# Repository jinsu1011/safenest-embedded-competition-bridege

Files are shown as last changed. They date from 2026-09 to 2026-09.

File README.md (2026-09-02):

# SafeNest

밀폐공간 작업자의 **호흡·움직임·자세**와 **공기질**을 동시에 감시해, 위험을 스스로 알릴 수 없는 상태가 되기 전에 경보하는 임베디드 안전 모니터링 시스템.

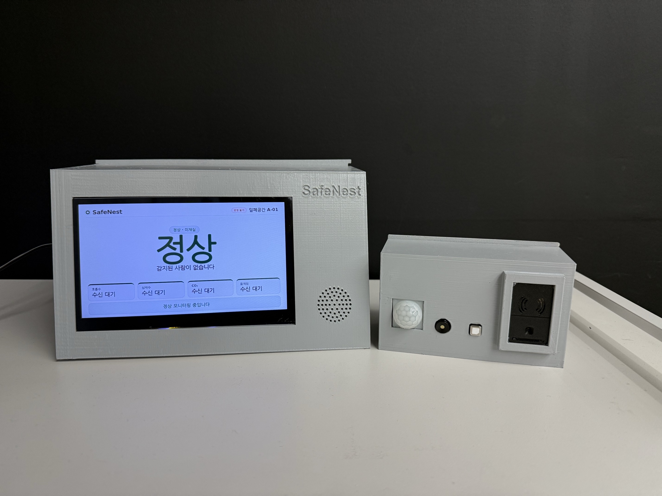
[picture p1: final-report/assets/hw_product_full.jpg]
SafeNest 완제품


| 현장 LCD 패널 | 관제 웹 대시보드 |
|---|---|
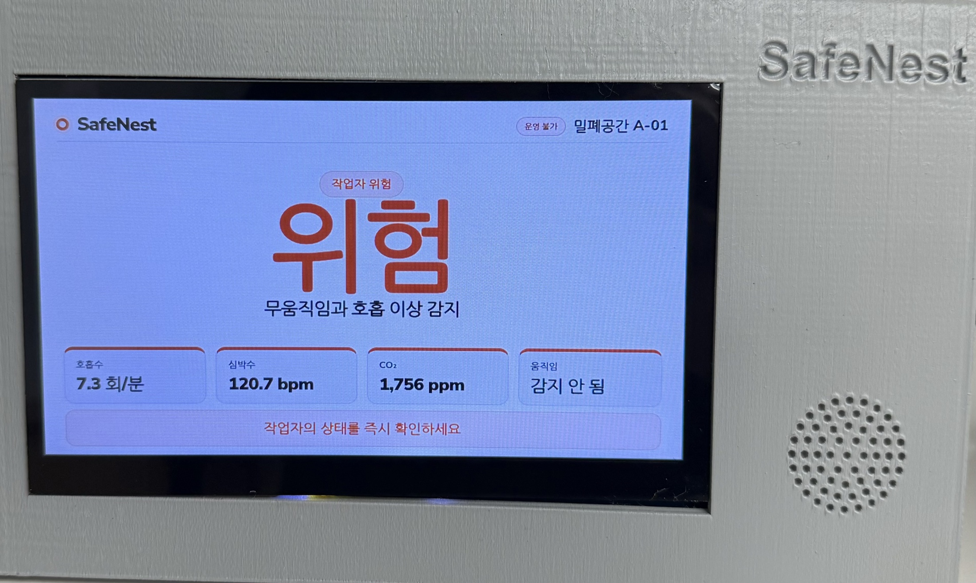
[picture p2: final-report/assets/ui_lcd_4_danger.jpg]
LCD 위험 상태
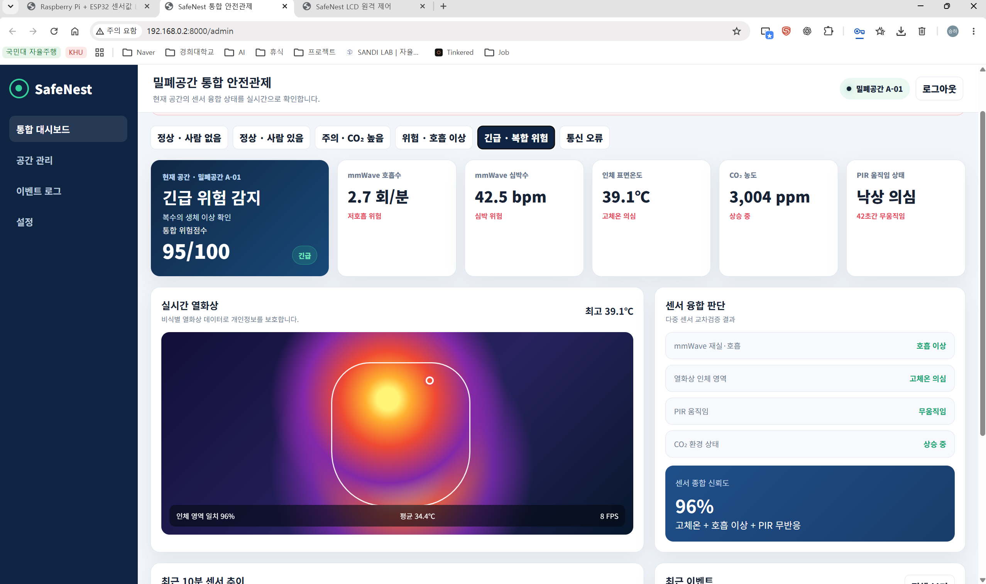
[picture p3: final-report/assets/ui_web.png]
웹 대시보드
|  |  |

---

## 프로젝트 개요

**문제.** 맨홀·정화조·탱크 같은 밀폐공간 질식 재해는 쓰러진 뒤에는 본인이 도움을 요청할 수 없다. 사고의 대부분은 "감지가 늦어서"가 아니라 "아무도 보고 있지 않아서" 커진다. 반대로 CO₂ 센서만 두면 사람이 이미 무호흡 상태여도 공기질이 기준 이하면 정상으로 표시된다.

**접근.** SafeNest는 한 가지 신호에 의존하지 않는다. mmWave 레이더로 **호흡**을, 열화상으로 **자세**를, PIR로 **움직임**을, NDIR 센서로 **CO₂**를 각각 독립적으로 관측하고, 네 결과를 하나의 위험도로 융합한다.

추론은 전부 Raspberry Pi 위에서 수행된다. **센서 데이터 처리, AI 추론, 위험도 판단, 현장 경보(부저·TTS), 화면 표시는 클라우드 서버 없이 Pi 안에서 완결된다.** ESP32 센서 노드와 Raspberry Pi 사이는 현장 Wi-Fi 의 TCP/UDP 로 연결되므로 이 구간이 끊기면 해당 센서는 데이터 없음(`INDETERMINATE`) 으로 처리된다.

**적용 환경.** 밀폐공간 단독·소수 작업, 상시 관제 인력이 없는 현장.

---

## 핵심 기능

- **4채널 센서 수집** — mmWave 호흡/심박, MH-Z19B CO₂, PIR 움직임, 80×62 열화상 프레임
- **이중 전송 경로** — 저속 스칼라는 TCP(`SNST` v1), 열화상 프레임은 청크 UDP(`SNTU` v1). 프레임 CRC32·형상·길이를 모두 검증하고 순서 무관 재조립
- **센서 상태 관리** — 센서별 freshness/유효성을 값과 분리해 추적. 오래된 값을 최신값처럼 표시하지 않음
- **온디바이스 AI 3종** — Thermal 자세 proxy(TFLite), CO₂ 재실 판정(TFLite INT8), mmWave 호흡 파형(PyTorch). 각 모델은 서로 격리되어 하나가 실패해도 나머지 판단이 유지됨
- **증거 충분성 기반 위험도 융합** — 가중합에 더해 ① 심각 신호가 평온한 신호에 희석되지 않는 escalation floor, ② 근거가 부족하면 NORMAL 대신 `INDETERMINATE` 를 게시하는 evidence gate, ③ 상위 두 확률 차가 작으면 "판단 없음"으로 처리하는 decisiveness gate
- **비상 대응 HMI** — 위험 확정 시 부저, 로컬 한국어 TTS 음성 안내, 담당자 SMS, 경보 확인/해제 절차
- **관제 화면 3종** — 관리자 포털, 관제 대시보드, QR 게스트 화면
- **현장 LCD 패널** — Raspberry Pi 로컬 LCD 상태 화면
- **SQLite 영속화** — 상태 스냅샷과 전이 이벤트 기록, 디스크 쿼터를 지키는 원시 센서 로깅

---

## System Architecture

```
MR60BHA2 (호흡·심박) ┐
MH-Z19B   (CO₂)      ├─→ ESP32 ─┬─ TCP  :9000  SafeNest v1 스칼라 telemetry
PIR       (움직임)   │          └─ UDP  :5005  Thermal 청크 프레임
MI48xx    (열화상)   ┘                 │
                                       ▼
                        Raspberry Pi ── Gateway (프로토콜 검증 / UDP 재조립)
                                       │
                                       ▼
                              Sensor State Manager  (freshness · 유효성 · revision)
                                       │
                                       ▼
                              On-device AI Pipeline
                                 ├ Thermal  TFLite fp32
                                 ├ CO₂      TFLite int8
                                 └ mmWave   PyTorch fp32
                                       │
                                       ▼
                              Risk Formula V1  (가중합 + escalation floor + evidence gate)
                                       │
                     ┌─────────────────┼─────────────────┐
                     ▼                 ▼                 ▼
                  SQLite         FastAPI :8000       Emergency
              (이벤트/이력)      REST + WebSocket   부저 · TTS · SMS
                                       │
                     ┌─────────────────┼─────────────────┐
                     ▼                 ▼                 ▼
                  /admin           /dashboard      /display (LCD)
                                   /guest/...
```

위험 등급: `NORMAL` · `WARNING` · `DANGER` · `INDETERMINATE`(근거 부족)

---

## Hardware

| 장치 | 부품 | 연결 |
|---|---|---|
| 센서 노드 MCU | ESP-WROOM-32 (ESP32 Dev Module) | — |
| 호흡 · 심박 · 재실 | Seeed MR60BHA2 60 GHz mmWave | UART2 GPIO 16/17 |
| CO₂ | Winsen MH-Z19B NDIR | UART1 GPIO 32/33 (별도 4.5–5.5 V 전원) |
| 움직임 | PIR 모션 센서 | GPIO 13 |
| 열화상 80×62 | MI48xx 기반 Thermal Camera HAT | I²C 21/22 제어 + SPI 18/19/23/27, READY 26, RESET 25 |
| 게이트웨이 · AI · 백엔드 | Raspberry Pi 5 | 2.4 GHz Wi-Fi |
| 표시 | Raspberry Pi 연결 LCD (Chromium 키오스크) | — |
| 경보 | 부저(GPIO), 스피커 | — |

외함 STL 과 설계 사양은 [`hardware/3d_models/`](hardware/3d_models/) 에 있다.

---

## Repository Structure

```
.
├── run_safenest.sh                  ★ 공식 실행 진입점 (유일)
├── README.md · THIRD_PARTY_NOTICES.md · COMPONENT_SOURCES.json
│
├── ESP32/
│   ├── Arduino/esp32_sensor_node/
│   │   ├── esp32_sensor_node.ino   ★ 정본 펌웨어
│   │   ├── secrets.example.h
│   │   └── ESP32.md
│   └── docs/            빌드 환경 가이드 · 통신 프로토콜 명세
│
├── RaspberryPi/
│   ├── Runtime/         ★ 게이트웨이 · 상태 · AI · 위험도 · 백엔드 · DB
│   │   ├── deployment/  run_pi.sh · verify_bundle.py
│   │   ├── gateway/     protocol.py · receiver.py · thermal_udp.py
│   │   ├── state/       manager.py
│   │   ├── ai/          pipeline.py · runtime.py · mmwave_b23_* · co2_canonical_runtime.py
│   │   ├── risk/        formula_v1.py · risk_formula_v1.json · engine.py
│   │   ├── backend/     app.py · run_backend.py · runtime.py · views.py · portal.py
│   │   ├── database/    schema.sql · repository.py · store.py
│   │   ├── services/    tts.py · buzzer.py · sms_service.py · emergency.py
│   │   ├── storage/     sensor_logger.py
│   │   ├── hil/         preflight.py(기동 필수) · 현장 수집/판정 도구
│   │   └── tests/       소프트웨어 테스트
│   ├── Ondevice_AI/
│   │   ├── inference/   ★ Thermal·CO₂ 활성 어댑터 (+ 비활성 M-N9)
│   │   ├── models/      ★ model_manifest.json + 모델 아티팩트
│   │   ├── risk/        risk_config.json (구형 V4, 활성 엔진 미사용)
│   │   └── tests/       활성 Thermal 모델 계약 테스트
│   ├── Web/             ★ 관리자 포털 · 대시보드 · 게스트 화면
│   │   └── vendor/      외부 라이브러리 로컬 포함 (Chart.js)
│   └── LCD/static/      ★ display.html · common.css
│
├── hardware/            3D 하우징 STL 및 설계 사양
└── final-report/        대회 개발완료보고서 PDF/PPTX 및 이미지 자산
```

---

## 실행되는 코드

런타임이 실제로 로드하는 진입점과 자산은 다음이다. 저장소에는 이 밖에 비활성 모델 아티팩트와 데모 모드 전용 대시보드 자산이 함께 보관되어 있으며, 어느 것도 기본 실행 경로에 로드되지 않는다.

| 구성 | 경로 |
|---|---|
| **ESP32 펌웨어** | [`ESP32/Arduino/esp32_sensor_node/esp32_sensor_node.ino`](ESP32/Arduino/esp32_sensor_node/esp32_sensor_node.ino) |
| **Runtime 진입점** | [`run_safenest.sh`](run_safenest.sh) → [`RaspberryPi/Runtime/deployment/run_pi.sh`](RaspberryPi/Runtime/deployment/run_pi.sh) → [`RaspberryPi/Runtime/backend/run_backend.py`](RaspberryPi/Runtime/backend/run_backend.py) |
| **Web 관리자** | [`RaspberryPi/Web/portal/preview.html`](RaspberryPi/Web/portal/preview.html) + `portal/admin-api.js` + `portal/thermal-client.js` |
| **Web 대시보드** | [`RaspberryPi/Web/index_final.html`](RaspberryPi/Web/index_final.html) + `app_final.js` + `styles_final.css` |
| **Web 게스트** | [`RaspberryPi/Web/guest/index.html`](RaspberryPi/Web/guest/index.html) |
| **LCD** | [`RaspberryPi/LCD/static/display.html`](RaspberryPi/LCD/static/display.html) + [`RaspberryPi/LCD/static/common.css`](RaspberryPi/LCD/static/common.css) |

경로 상수는 [`RaspberryPi/Runtime/paths.py`](RaspberryPi/Runtime/paths.py) 한 곳에 모여 있다.

---

## 핵심 코드

| # | 파일 | 역할 |
|---|---|---|
| 1 | [ESP32 정본 펌웨어](ESP32/Arduino/esp32_sensor_node/esp32_sensor_node.ino) | 4센서 수집, `delay()` 없는 millis 스케줄링, TCP/UDP 를 각각 FreeRTOS 태스크로 분리, 1-슬롯 열화상 큐로 최신 프레임 우선 |
| 2 | [`gateway/protocol.py`](RaspberryPi/Runtime/gateway/protocol.py) | `SNST` v1 16바이트 헤더 파싱과 페이로드 검증, 9,936바이트 열화상 계약 |
| 3 | [`gateway/thermal_udp.py`](RaspberryPi/Runtime/gateway/thermal_udp.py) | 청크 UDP 순서 무관 재조립, CRC32·형상·범위 검증, 프레임 타임아웃 |
| 4 | [`state/manager.py`](RaspberryPi/Runtime/state/manager.py) | 센서별 freshness/유효성/기기 건강을 값과 분리해 관리, publication revision 발행 |
| 5 | [`ai/pipeline.py`](RaspberryPi/Runtime/ai/pipeline.py) | 모델별 격리 평가. mmWave 는 wire rate 로 누적, CO₂ 는 measurement-event 기준으로 누적 |
| 6 | [`ai/runtime.py`](RaspberryPi/Runtime/ai/runtime.py) | 지연 로딩 + 실패 격리 어댑터. manifest selector 와 런타임이 어긋나면 `MODEL_SELECTOR_DRIFT` 로 차단 |
| 7 | [`ai/mmwave_b23_runtime.py`](RaspberryPi/Runtime/ai/mmwave_b23_runtime.py) | 활성 mmWave 경로. 30초 호흡 파형을 10 Hz 300표본으로 정규화 후 621차원 입력 생성 |
| 8 | [`risk/formula_v1.py`](RaspberryPi/Runtime/risk/formula_v1.py) | **활성 위험도 엔진.** 가중합 + escalation floor + evidence sufficiency + decisiveness gating |
| 9 | [`backend/app.py`](RaspberryPi/Runtime/backend/app.py) | FastAPI 라우트, WebSocket 게시, Web/LCD 서빙, 공간 포털, 비상 액션 API |
| 10 | [`hil/preflight.py`](RaspberryPi/Runtime/hil/preflight.py) | 기동 전 필수 검사. 모든 모델 SHA256 을 manifest 와 대조해 불일치 시 기동 차단 |

---

## Installation

Raspberry Pi 5 / 64-bit OS / **Python 3.10 이상** 기준.

```bash
git clone https://github.com/jinsu1011/safenest-embedded-competition-bridege.git safenest
cd safenest
./run_safenest.sh --install
```

`--install` 이 수행하는 것:

1. 저장소 루트에 `.venv` 생성
2. `RaspberryPi/Runtime/requirements-backend.txt` 설치 — FastAPI, uvicorn, qrcode, piper-tts
3. `RaspberryPi/Ondevice_AI/requirements-pi.txt` 설치 — LiteRT, numpy/scipy, spidev/smbus2, **torch(CPU wheel index 사용)**
4. `import fastapi, piper, qrcode, torch, uvicorn` 로 설치 검증
5. Piper 한국어 음성 `ko_KR-kss-medium` 다운로드 (`RaspberryPi/Runtime/data/tts/`, Git 미추적)

> **torch 가 필수인 이유** — 활성 mmWave 경로 B23 은 PyTorch float32 모델이고, 해당 모듈이 `backend/app.py → backend/runtime.py → ai/pipeline.py` import 체인에 포함된다. torch 가 없으면 백엔드가 기동되지 않는다.
> 일반 PyPI 의 ARM64 torch 는 Pi 에 없는 CUDA/NVIDIA 의존성을 끌어오므로, `requirements-pi.txt` 는 공식 CPU wheel index(`https://download.pytorch.org/whl/cpu`)를 함께 지정한다.

민감 설정은 저장소 루트 `.env` 로 주입한다. 키 목록은 [`RaspberryPi/Runtime/.env.example`](RaspberryPi/Runtime/.env.example) 참고 (SMS 자격증명, 담당자 연락처, 부저 GPIO, 센서 데이터 쿼터 등). `.env` 는 Git 에 올리지 않는다.

---

## Execution

**공식 실행 방법은 하나다.**

```bash
./run_safenest.sh
```

이 한 줄이 하나의 프로세스 트리에서 다음을 모두 띄운다.

| 구성 | 포트 |
|---|---|
| SafeNest TCP v1 게이트웨이 (mmWave/CO₂/PIR) | `9000/tcp` |
| SafeNest Thermal UDP v1 수신기 | `5005/udp` |
| FastAPI + WebSocket (Web · LCD · API) | `8000/tcp` |

기동 직전 `hil.preflight` 가 Python 버전, 필수 모듈, 포트 가용성, **모델 SHA256 계약**을 검사하고 실패 시 기동을 중단한다.

주요 옵션은 그대로 전달된다. 예: `./run_safenest.sh --api-port 8080 --room "밀폐공간 B-02"`

<details>
<summary>선택: Thermal 모델 A/B 비교 실행</summary>

```bash
# 현재 활성 모델 — 환경변수 없이 그대로 기동
./run_safenest.sh

# TV2 Candidate A
SAFENEST_THERMAL_TEST_MODE=1 SAFENEST_THERMAL_MODEL_SELECTOR=thermal_tv2_candidate_a_a0_fp32_v1 ./run_safenest.sh

# TV2 Candidate B
SAFENEST_THERMAL_TEST_MODE=1 SAFENEST_THERMAL_MODEL_SELECTOR=thermal_tv2_candidate_b_seed42_fp32_test_v1 ./run_safenest.sh
```

`SAFENEST_THERMAL_TEST_MODE=1` 이 없으면 selector 지정은 fail-closed 로 거부되고, manifest 에서 `controlled_test_allowed: true` 인 모델만 선택된다. 평시 운영 경로(`./run_safenest.sh`)는 영향을 받지 않는다. Candidate A/B 는 비교 대상이지 배포 모델이 아니다.
</details>

---

## ESP32 Build & Flash

1. Arduino IDE 에 ESP32 보드 패키지 설치 후 **ESP32 Dev Module** 선택
2. Library Manager 에서 **Seeed Arduino mmWave** 설치 (하위 의존성 `Install all`)
3. 자격증명 파일 생성 — 실제 값은 커밋되지 않는다

   ```bash
   cd ESP32/Arduino/esp32_sensor_node
   cp secrets.example.h secrets.h
   ```

   `secrets.h` 에 2.4 GHz Wi-Fi SSID/비밀번호, Raspberry Pi 의 WLAN IPv4(`RPI_HOST`), TCP 포트(`RPI_PORT`, 기본 9000)를 입력한다. 열화상 UDP 도 같은 호스트의 5005 로 전송된다.
4. `esp32_sensor_node.ino` 를 열어 컴파일 후 업로드
5. Serial Monitor `115200 baud` 에서 `[health]` 로그의 `wifi=up`, `rpi=<Pi IP>`, `udp_sent` 증가 확인

상세 절차·배선표·오류 대응은 [`ESP32/docs/ARDUINO_ENVIRONMENT_SETUP_KO.md`](ESP32/docs/ARDUINO_ENVIRONMENT_SETUP_KO.md), 와이어 포맷은 [`ESP32/docs/COMMUNICATION_PROTOCOL.md`](ESP32/docs/COMMUNICATION_PROTOCOL.md).

---

## Web Dashboard

`./run_safenest.sh` 실행 후 같은 네트워크에서 접속한다. 별도 웹 서버는 없다.

| 화면 | URL | 서빙 파일 |
|---|---|---|
| 관리자 포털 (기본 진입) | `http://<pi>:8000/admin` | `Web/portal/preview.html` |
| 관제 대시보드 | `http://<pi>:8000/dashboard` | `Web/index_final.html` |
| 게스트 QR 화면 | `http://<pi>:8000/guest/dashboard/<space_id>` | `Web/guest/index.html` |
| LCD 패널 | `http://<pi>:8000/display` | `LCD/static/display.html` |
| 헬스체크 | `http://<pi>:8000/health` | — |

`http://<pi>:8000/` 은 `/admin` 으로 리다이렉트된다.

**모든 화면은 외부 네트워크 자산을 참조하지 않는다.** 그래프 라이브러리(Chart.js 4.5.1)까지 저장소에 포함해 `/vendor/chart.js/chart.umd.min.js` 로 같은 서버가 서빙하므로, 인터넷이 없는 현장에서도 관리자·대시보드·게스트·LCD 화면이 모두 완전하게 동작한다. 출처와 라이선스는 [`THIRD_PARTY_NOTICES.md`](THIRD_PARTY_NOTICES.md) 6장 참고.

**API / WebSocket** — 전체 계약은 [`backend/views.py`](RaspberryPi/Runtime/backend/views.py) 의 `ROUTE_CONTRACTS` 에 정의되어 있다.

| 종류 | 경로 |
|---|---|
| 상태 | `GET /api/status` · `GET /api/sensors` · `GET /api/state` |
| 이력 | `GET /api/events` · `GET /api/history` |
| 공간 관리 | `GET/POST /api/spaces` · `GET/PATCH/DELETE /api/spaces/{id}` · `GET /api/qr/{id}.png` |
| 열화상 | `GET /api/thermal/{space_id}` (ETag 기반 바이너리 프레임) |
| 비상 대응 | `POST /api/emergency/contact` · `/acknowledge` · `/recovery/acknowledge` · `/voice` |
| 실시간 | `WS /ws` — publication revision 이 바뀔 때만 상태 문서 전송 |

**관리자 계정은 저장소에 없다.** `/admin` 로그인은 환경변수로만 설정한다.

```bash
export SAFENEST_ADMIN_ID=...
export SAFENEST_ADMIN_PASSWORD=...
export SAFENEST_AUTH_SECRET=...        # 선택. 없으면 프로세스마다 무작위 서명 키
```

두 값을 모두 설정하기 전까지 로그인은 **항상 거부**된다(fail-closed). 빈 값끼리 일치해 통과하는 경로도 없다. 나머지 런타임·API·LCD·게스트 화면은 계정 설정과 무관하게 정상 동작하며, 현재 설정 여부는 `GET /health` 의 `admin_auth_configured` 로 확인한다.

`SAFENEST_DEMO_MODE=1` 로 실행하면 데모 전용 화면(`/control`, `/dashboard` 의 데모판)과 119 신고 시뮬레이션 API 가 추가로 열린다. 평시 운영에서는 사용하지 않는다.

---

## LCD

Raspberry Pi 에 연결된 LCD 는 **통합 백엔드가 직접 서빙**한다. 별도 LCD 서버 프로세스는 없다.

| 경로 | 파일 |
|---|---|
| `/display` | `RaspberryPi/LCD/static/display.html` |
| `/common.css` | `RaspberryPi/LCD/static/common.css` |

`display.html` 은 `GET /api/state` 를 폴링해 갱신하며, 외부 자산을 참조하지 않는다. Chromium 키오스크 실행·종료 절차는 [`RaspberryPi/LCD/LCD_KIOSK_KO.md`](RaspberryPi/LCD/LCD_KIOSK_KO.md).

---

## On-device AI

추론은 모두 Raspberry Pi 에서 수행된다. 활성 모델은 [`models/model_manifest.json`](RaspberryPi/Ondevice_AI/models/model_manifest.json) 이 selector 와 SHA256 으로 고정하며, 기동 시 preflight 가 전 항목을 대조한다.

| 센서 | selector | 아티팩트 | 형식 | 출력 |
|---|---|---|---|---|
| Thermal | `thermal_public_sdt_fp32_active` | `models/thermal/public_sdt/public_sdt_pooled_mlp_fp32_tflite_v1.tflite` | TFLite fp32 | `NOT_HUMAN` / `HUMAN_NORMAL` / `HUMAN_FALL_PROXY` |
| CO₂ | `co2_occupancy_c_b6` | `models/rp_x0_b_complete/co2/C_B6_REDUCED_CO2_SLOPE_CANDIDATE_001_full_integer_int8.tflite` | TFLite full-int8 | 실내 재실 여부 |
| mmWave | `mmwave` (M-PROT-B23) | `models/mmwave/m_prot_b23/candidate_seed_23.pt` | PyTorch fp32 | 호흡 파형 판정 + 품질 |

**실행 경로.** [`ai/pipeline.py`](RaspberryPi/Runtime/ai/pipeline.py) 가 세 모델을 서로 격리해 평가한다.

| 센서 | 호출되는 코드 |
|---|---|
| Thermal | `ai/runtime.py` 의 `LazyModel` → `Ondevice_AI/inference/thermal_interpreter.py` |
| CO₂ | `ai/runtime.py` 의 `LazyModel` → `Ondevice_AI/inference/co2_c_b6_interpreter.py` |
| mmWave | [`ai/mmwave_b23_runtime.py`](RaspberryPi/Runtime/ai/mmwave_b23_runtime.py) 의 `B23TeamRuntime` (PyTorch 직접 실행) |

> **M-N9 은 활성 경로가 아니다.** `Ondevice_AI/inference/mmwave_m_n9_interpreter.py` 와
> `models/mmwave/m_n9/MMWAVE_M_N9_FULL_INT8_V1.tflite` 가 저장소에 남아 있지만,
> `ai/pipeline.py` 의 mmWave 경로는 항상 `B23TeamRuntime` 을 호출하므로 이 어댑터는
> 실행되지 않는다. manifest 에서도 `deployment_allowed: false`,
> `runtime_role: LEGACY_M_N9_NONACTIVE` 이며 강제 로드 시 `MODEL_RELEASE_BLOCKED` 로
> 차단된다. 파일이 남아 있는 이유는 기동 preflight 가 manifest 에 등재된 모든
> 아티팩트의 SHA256 을 검증하기 때문이다.

**주장 범위를 명시한다.**

- Thermal 모델은 공개 데이터(SDT)로 학습했고 **위험도에서는 사람 유무만** 판정한다. 실제 낙상 이벤트를 검증하지 않았다. 위험도에 들어가는 자세(서기·앉기 vs 눕기)는 모델 softmax 가 아니라 bbox 종횡비 오버레이가 정하며, `HUMAN_FALL_PROXY` 는 제한된 가중치(0.4)의 자세 proxy 로서 단독으로 비상을 선언하지 못한다.
- CO₂ 모델의 의미는 **실내 재실 판정**이며 질식·유해가스 ground truth 가 아니다. 안전 판정은 모델이 아니라 규칙이 담당한다. 빈방에서는 위험·긴급을 선언하지 않는다. 주의(`WARNING`)는 로컬라이징 기준값 대비 상대 상승(+500 ppm 진입 / +350 ppm 해제)과 CO₂ 기울기(50 ppm/min)로만 발생하고, 남아 있는 절대 ppm 트립은 비상 오버라이드 5,000 ppm 하나뿐이다.
- mmWave B23 은 prototype integration freeze 단계로, 위험도 기여가 유보(`risk_contribution_deferred`)되어 있다.

학습 데이터 출처와 이용 조건은 [`THIRD_PARTY_NOTICES.md`](THIRD_PARTY_NOTICES.md) 5장 참고. 원본 데이터셋은 저장소에 포함하지 않는다.

---

## Risk Engine

활성 엔진은 [`RaspberryPi/Runtime/risk/formula_v1.py`](RaspberryPi/Runtime/risk/formula_v1.py) (`SAFENEST_RISK_V1` v1.3.3), 설정은 [`risk/risk_formula_v1.json`](RaspberryPi/Runtime/risk/risk_formula_v1.json).

| 항목 | 값 |
|---|---|
| 가중치 | CO₂ 0.30 · Thermal 0.30 · mmWave 0.25 · PIR 0.15 |
| 종합 위험도 임계값 | `DANGER` ≥ 65 (종합 산식은 `WARNING` 을 게시하지 않는다) |
| 재실 게이트 | `DANGER`/`EMERGENCY` 는 `presence_detected == true` 일 때만 발생. 비재실이면 종합 위험도는 `NORMAL` |
| 주의 산식 | `SAFENEST_CAUTION_CO2_V1` — CO₂ 단독. 기준값 대비 +500 ppm 진입 · +350 ppm 해제 · 기울기 50 ppm/min |
| 비상 절대 트립 | CO₂ 5,000 ppm (유일한 절대 ppm 트립). 재실이면 즉시 긴급, 비재실이면 `WARNING` 으로 강등 |
| Thermal 자세 | 모델은 사람 유무만 판정. 서기/앉기 vs 눕기는 bbox 종횡비 오버레이 (`HUMAN_NORMAL` 0.0 / `HUMAN_FALL_PROXY` 0.4). 오버레이 실패 시 `PRESENCE_ONLY` + `HUMAN_NORMAL` |
| 증거 게이트 | 사용 가능한 구성요소의 가중치 합이 0.5 미만이면 `INDETERMINATE` |

단순 가중합이 갖지 못한 다섯 가지 성질을 갖는다.

1. **Escalation floor** — 심각한 신호 하나가 평온한 신호 셋에 희석되어 NORMAL 로 떨어지지 않는다.
2. **Evidence sufficiency** — 근거가 부족하면 NORMAL 을 게시하지 않고 `INDETERMINATE` 를 게시한다. "센서가 죽어서 조용한 것"과 "실제로 안전한 것"을 구분한다.
3. **Decisiveness gating** — 상위 두 확률의 차가 기준 미만인 분류 결과는 점수화하지 않고 "판단 없음"으로 처리한다.
4. **Caution 분리** — `WARNING` 은 가중합 점수 구간이 아니라 CO₂ 전용 주의 산식이 만든다. mmWave·PIR·Thermal 은 점수와 `DANGER`/`EMERGENCY` 에는 기여하지만 주의를 올리지 못한다. 밀폐 공간이 상시 1,500 ppm 근처에 머물러 종일 `WARNING` 을 만들던 절대 임계값(1,500 ppm)과 `danger_ppm` 2,500 ppm 은 제거했다.
5. **재실 게이팅** — 빈방에서는 위험·긴급을 만들지 않는다. `DANGER`/`EMERGENCY` 는 `presence_detected == true` 를 요구하고, 사람이 없는 공간의 5,000 ppm 은 `WARNING` 으로만 게시한다. 사람이 확인된 공간의 5,000 ppm 은 즉시 긴급이다. 자세 판정도 같은 원칙을 따른다 — 모델은 사람 유무만 결정하고, 위험도에 들어가는 서기/앉기 vs 눕기는 bbox 오버레이가 정한다. 모델의 눕기 softmax 는 위험도 입력이 아니며, 오버레이가 실패하면 `PRESENCE_ONLY` + `HUMAN_NORMAL` 로 떨어진다.

규칙 임계값(호흡 정상범위 10–24 rpm, 무호흡 지속 판정, PIR 무움직임 유예 30초 · 위험 180초, CO₂ 상대 +500/−350 ppm 및 절대 비상 5,000 ppm)은 활성 엔진이 읽는 [`RaspberryPi/Runtime/risk/risk_formula_v1.json`](RaspberryPi/Runtime/risk/risk_formula_v1.json) 한 곳에 있다.

---

## Validation

**검증 환경:** Raspberry Pi 5 (aarch64) / Debian 13 / Python 3.13.5 / 런타임 venv (fastapi 0.141.1, uvicorn, numpy 1.26.4, scipy, ai-edge-litert, torch 2.13.0+cpu, qrcode). 아래 소프트웨어 검증은 실제 배포 대상 Raspberry Pi 에서 실행했다. ESP32 빌드 환경은 사용하지 않았고, 센서 실측 결과는 별도 evidence 문서를 따른다.

| 항목 | 결과 | 비고 |
|---|---|---|
| Python 구문 검사 (전체 추적 `.py`) | **PASS** | 오류 0 |
| Shell 구문 검사 (`bash -n`) | **PASS** | `run_safenest.sh`, `run_pi.sh` |
| Runtime 테스트 (`RaspberryPi/Runtime/tests`) | **417 passed · 21 failed · 1 skipped** | Risk 1.3.3 / 재실 게이팅 / CO₂ 주의 산식 / TTS 우선순위 테스트 포함. 실패 21건은 아래 Known Limitations 참조 |
| On-device AI 테스트 (`RaspberryPi/Ondevice_AI/tests`) | **25 passed · 2 skipped** | 활성 Thermal 모델 SHA/selector 계약 + bbox 종횡비 자세 오버레이 |
| 모델 SHA256 계약 (preflight) | **PASS** | manifest 등재 10개 아티팩트 전부 일치 |
| 제출본 무결성 (`verify_bundle.py`) | **PASS** | 필수 파일 누락 0, 금지 산출물 0 |
| Web 정적 참조 정합성 | **PASS** | `/admin` HTML → JS(58개 DOM id) → API/WS 전 경로 연결 확인 |
| HTTP smoke (19개 route + `WS /ws`) | **PASS** | 실제 앱 부팅 후 응답 확인 |
| 외부 네트워크 자산 참조 | **0건** | 웹·LCD 전체에 외부 CDN/호스트 참조 없음 |
| Chart.js 오프라인 동작 | **PASS** | 브라우저에서 `window.Chart` 4.5.1 로드·차트 인스턴스 생성 확인, 배포본 SHA-256 일치 |
| 관리자 인증 fail-closed | **PASS** | 미설정 시 로그인 거부(503)·보호 API 401, 설정 후 정상 로그인·토큰 인가 |
| LCD 자산 참조 | **PASS** | `display.html` → `common.css`, `GET /api/state` |
| 문서 링크 · 파일 참조 | **PASS** | 4개 문서 47개 상대 링크, 깨짐 0 |
| `COMPONENT_SOURCES.json` 경로 | **PASS** | 30개 구성요소 경로 전부 실재 |
| 중복 파일 검사 | **PASS** | `.gitkeep` 외 바이트 동일 중복 없음 |
| Secret 스캔 | **PASS** | 토큰·키·자격증명 값 없음. `*.example` 템플릿만 추적 |
| 추적된 DB/캐시/빌드 산출물 | **PASS** | 없음 |
| **ESP32 펌웨어 빌드** | **PASS** | - |
| **Raspberry Pi 소프트웨어 검증** | **PASS — 실기기에서 실행** | 위 표의 테스트·preflight·부팅·HTTP/WS 검증을 배포 대상 Raspberry Pi 5 에서 직접 실행 |
| **Raspberry Pi 라이브 센서 구동** | **PASS** | - |
| **실제 낙상 이벤트 검증** | **NOT VERIFIED** | — |

> 별도 기록으로, Raspberry Pi 5 / aarch64 / torch 2.13.0+cpu 환경에서 PyTorch import, B23 모델 load, 백엔드 기동이 확인된 소유자 제공 결과가 있다. 해당 실행 기록은 소유자가 보유하며 제출 저장소에는 포함하지 않았다. 이는 **pre-live 준비 상태**이며 라이브 센서 E2E 검증이 아니다.

제출본 구성 완전성은 다음으로 확인할 수 있다.

```bash
python3 RaspberryPi/Runtime/deployment/verify_bundle.py
```

---

## Known Limitations

- **웹 대시보드에 런타임 상태(O4) 표시 미구현** — 백엔드는 `runtime_status`(센서 가용성과 AI 가용성을 분리한 판정)를 `/api/status`·`/api/sensors`·`/api/state` 로 이미 게시하고 **LCD 화면은 이를 소비**한다. 반면 웹 대시보드(`Web/app.js`·`app_final.js`)는 이 필드를 읽지 않고, 요구되는 DOM 요소(`runtimeBadge`, `thermalSensor`, `thermalAiStatus`, `co2Ai`, `pirAi`)도 없다. 해당 UI 는 과거 대시보드 세대에 구현되었으나 이후 웹 화면을 새로 작성해 교체하는 과정에서 유실되었고, 백엔드·LCD·검사 계약만 남았다. `--offline-preflight` 의 관련 검사 2건과 UI 테스트 8건(대시보드 정적 검사 1건 포함)이 이 때문에 실패한다. 이 검사는 **오프라인 검사 전용**이라 Raspberry Pi 기동 경로(`pi_start_document`)에는 포함되지 않아 실행을 막지 않는다.
- **stage9 스모크 도구 테스트 실패** — 현장 수집 판정 도구(`hil/stage9_*`)의 테스트 6건이 실패 상태다. 평가 도구 자체의 문제이며 런타임 판단 경로와 무관하다.
- **LCD legacy state 매핑 테스트 실패** — `test_legacy_lcd_state_mapping` 1건이 `runtime_status` 를 기대해 실패한다. 팀 운영 저장소 동일 리비전에서도 같은 실패가 재현되는 상류 기존 이슈이며, 위 O4 미구현과 같은 원인이다.
- **preflight 모델 해시 검사 개수 불일치** — `test_hil_criteria` 가 6개를 기대하지만 manifest 에 10개 항목이 있어 실패한다. 실제 해시 검증은 10개 모두 통과한다.
- **Thermal 모델의 낙상 판정은 proxy** — 공개 데이터 기반 자세 분류이며, 실제 낙상 이벤트와 MI48xx 하드웨어 도메인에서 검증되지 않았다. 단독 비상 선언 권한이 없다.
- **mmWave B23 위험도 기여 유보** — mmWave 센서의 관찰 범위가 최대 1.5m인 점을 감안하여 prototype freeze 단계로 위험도 산출에 정식 반영되지 않는다.

---

## License / External Sources

프로젝트 자체 라이선스는 **아직 지정하지 않았다.**

외부 라이브러리·모델·데이터셋의 출처와 이용 조건은 [`THIRD_PARTY_NOTICES.md`](THIRD_PARTY_NOTICES.md) 에 정리했다. 특히 다음 조건은 반드시 준수한다.

- **SDT Dataset** (doi:10.5281/zenodo.4124309) — 비상업적 연구 목적 + 출처 표시
- **Piper `ko_KR-kss-medium` 음성** — CC BY-NC-SA 4.0
- **UCI Occupancy Detection Dataset** — 원 배포처 조건

저장소 구성요소별 경로·역할·분류는 [`COMPONENT_SOURCES.json`](COMPONENT_SOURCES.json) 참고.

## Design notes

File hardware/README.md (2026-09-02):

# hardware

SafeNest 장치의 물리 하드웨어 설계 자산을 보관한다.

## 목적

센서 배치와 시야각 제약을 만족하는 외함을 제3자가 그대로 재현할 수 있도록,
출력 가능한 3D 모델과 치수 사양을 함께 둔다.

## 구성

| 경로 | 내용 |
|---|---|
| [`3d_models/`](3d_models/) | 센서 노드 외함과 LCD·부저 하우징 STL 4종 + 설계 사양 |

세부 치수·개구부·출력 조건은 [`3d_models/README.md`](3d_models/README.md) 참고.

## SafeNest 시스템과의 관계

| 하우징 요소 | 대응 구성 |
|---|---|
| 전면 개구부 (PIR / Thermal / CO₂ / mmWave) | ESP32 센서 노드에 연결된 4개 센서 |
| LCD 개구부 | 백엔드가 `:8000/display` 로 서빙하는 현장 LCD 패널 |
| 부저 그릴 | 위험 확정 시 동작하는 경보 부저 |
| 측면 팬/공기 개구부, 후면 환기 슬롯 | MH-Z19B 주변 공기 유통 |

센서 핀 배치와 배선은 [`ESP32/docs/ARDUINO_ENVIRONMENT_SETUP_KO.md`](../ESP32/docs/ARDUINO_ENVIRONMENT_SETUP_KO.md) 와 일치해야 한다.

## 포함 / 비포함 기준

포함: 출처가 확인된 STL·CAD, 치수 사양, 출력 조건, 조립 주의사항.
비포함: 펌웨어·코드, 슬라이서 G-code 및 캐시, 출처 불명 외부 모델, 개인 프린터 프로파일.

## 출처

이 디렉터리의 3D 모델과 설계 사양은 모두 SafeNest 팀이 직접 설계·제작했다.
외부에서 가져온 자산은 없다.

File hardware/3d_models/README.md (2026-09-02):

# hardware/3d_models

SafeNest 외함의 3D 프린팅용 STL 과 설계 사양이다. 단위는 모두 **mm**.

## 파일

| 파일 | 역할 |
|---|---|
| `housing_body.stl` | 센서 노드 외함 본체 (직육면체, 137×80×60) |
| `sliding_back_panel.stl` | 센서 노드 슬라이딩 후면 패널 |
| `trapezoid_housing_body.stl` | LCD·부저 하우징 본체 (사다리꼴, 240 W × 140 H) |
| `trapezoid_T_back_panel.stl` | LCD·부저 하우징 T형 후면 패널 (환기 슬롯 포함) |
| [`설계_사양.txt`](설계_사양.txt) | 센서 노드 외함 치수·개구부·환기구·출력 조건 |
| [`사다리꼴_하우징_설계사양.txt`](사다리꼴_하우징_설계사양.txt) | LCD·부저 하우징 치수·부저 그릴·음각·환기 사양 |

렌더 이미지는 [`final-report/assets/`](../../final-report/assets/) 의 `3d_*.png` 에 있다.

## 센서 개구부 (센서 노드 외함)

| 개구부 | 치수 | 대응 센서 |
|---|---|---|
| PIR | 24 × 24 | PIR 모션 센서 |
| Thermal | 직경 11.85 | MI48xx 열화상 |
| CO₂ | 13 × 26 (직각 모서리) | MH-Z19B |
| mmWave | 36 × 55 + 외부 L자 커버 | MR60BHA2 |

정확한 좌표와 공차는 `설계_사양.txt` 를 따른다.

## 출력 시 주의

- 출력 전 단위(mm)와 실제 센서 보드 치수를 반드시 대조한다.
- 본체는 센서 전면을, 후면 패널은 넓은 평면을 빌드 플레이트에 놓는다.
- 슬라이드 레일이 빡빡하면 XY 보정을 0.1–0.2 적용한다.
- 시험 출력 없이 최종 출력을 진행하지 않는다.

## 관리 규칙

동일 파일명을 덮어쓰지 않고 버전 접미사를 붙인다. 추가 시 설계 버전, 단위,
프린터·재질 조건, 변경 근거를 함께 남긴다. STL 은 재생성하지 않고 원본을 보존한다.

## 출처

SafeNest 팀 자체 설계다. 외부에서 내려받은 모델은 포함하지 않는다.

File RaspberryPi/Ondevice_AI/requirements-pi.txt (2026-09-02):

# Raspberry Pi OS 64-bit / Python 3.10+용 LiteRT interpreter.
ai-edge-litert>=2.1,<2.2
numpy>=1.24,<2
scipy>=1.8.0
pandas>=1.5,<3
matplotlib>=3.7
Pillow>=9
joblib>=1.3
scikit-learn>=1.3
spidev>=3.6
smbus2>=0.4.3

# 활성 mmWave 경로(M-PROT-B23)는 PyTorch float32 state_dict 를 그대로 로드한다.
# ai/mmwave_prototype/mmwave_m_prot_2_b23_runtime.py 가 최상위에서 torch 를 import 하고,
# 이 모듈은 backend/app.py -> backend/runtime.py -> ai/pipeline.py 체인에 포함되므로
# torch 가 없으면 backend 기동 자체가 실패한다.
#
# 일반 PyPI 의 ARM64 torch 는 CUDA/NVIDIA 의존성을 함께 끌어온다(Pi 에는 CUDA 없음).
# 반드시 공식 CPU wheel index 를 함께 사용한다. Raspberry Pi 5 / aarch64 에서
# torch 2.13.0+cpu 로 import·모델 load·backend 기동이 확인되었다. 해당 실행 기록은
# 소유자가 보유하며 제출 저장소에는 포함하지 않는다.
--extra-index-url https://download.pytorch.org/whl/cpu
torch>=2.1.0

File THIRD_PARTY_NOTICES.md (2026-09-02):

# Third-Party Notices

SafeNest가 사용하는 외부 라이브러리·모델·데이터셋의 출처와 이용 조건이다.

라이선스 식별자는 **저장소 안에 근거 기록이 있는 경우에만** 적었다.
근거가 없는 항목은 임의로 라이선스를 지정하지 않고 `확인 필요`로 남겼으며,
재배포 여부가 불확실한 원본 데이터는 이 저장소에 포함하지 않았다.

---

## 1. ESP32 펌웨어가 사용하는 Arduino 라이브러리

정본 스케치
`ESP32/Arduino/esp32_sensor_node/esp32_sensor_node.ino`
가 `#include` 하는 외부 라이브러리다. 소스는 저장소에 포함하지 않으며,
Arduino IDE / `arduino-cli` 로 각자 설치한다.

| 라이브러리 | 제공 | 용도 | 검증 버전 | 출처 | 라이선스 |
|---|---|---|---|---|---|
| Seeed Arduino mmWave (`Seeed_Arduino_mmWave.h`) | Seeed Studio | MR60BHA2 mmWave 레이더 파싱 | 안정 계열 `1.0.0` | https://github.com/Seeed-Projects/Seeed-mmWave-library | 확인 필요 — 상단 저장소 참조 |
| Adafruit NeoPixel | Adafruit | 위 라이브러리의 하위 의존성 | Seeed 라이브러리 요구 버전 | https://github.com/adafruit/Adafruit_NeoPixel | 확인 필요 — 상단 저장소 참조 |
| hp_BH1750 | Stefan Armborst | 위 라이브러리의 하위 의존성 | Seeed 라이브러리 요구 버전 | https://github.com/Starmbi/hp_BH1750 | 확인 필요 — 상단 저장소 참조 |
| Arduino ESP32 core (`WiFi`, `WiFiUdp`, `Wire`, `SPI`, FreeRTOS, lwIP) | Espressif | 보드 런타임 | ESP32 Dev Module 대응 core | https://github.com/espressif/arduino-esp32 | 확인 필요 — 상단 저장소 참조 |

설치 절차는 `ESP32/docs/ARDUINO_ENVIRONMENT_SETUP_KO.md` 에 있다.

## 2. 하드웨어 (센서 · 보드)

| 부품 | 제조사 | 역할 | 문서 |
|---|---|---|---|
| ESP-WROOM-32 (ESP32 Dev Module) | Espressif | 센서 노드 MCU | — |
| MR60BHA2 60 GHz mmWave | Seeed Studio | 호흡/심박/재실 | https://wiki.seeedstudio.com/getting_started_with_mr60bha2_mmwave_kit/ |
| MH-Z19B NDIR CO₂ | Winsen | CO₂ 농도 | — |
| MI48xx 기반 Thermal Camera HAT (80×62) | Waveshare / Meridian Innovation | 열화상 프레임 | — |
| PIR 모션 센서 | — | 움직임 감지 | — |
| Raspberry Pi 5 | Raspberry Pi Ltd. | 게이트웨이 · 온디바이스 AI · 백엔드 | — |

## 3. Raspberry Pi Python 의존성

설치 목록은 `RaspberryPi/Runtime/requirements-backend.txt`,
`RaspberryPi/Ondevice_AI/requirements-pi.txt` 에 있다.
PyPI 배포본을 그대로 설치하며 소스는 저장소에 포함하지 않는다.
각 패키지의 라이선스는 배포처 메타데이터를 따른다.

| 패키지 | 용도 |
|---|---|
| `fastapi`, `uvicorn[standard]` | HTTP/WebSocket 백엔드 |
| `qrcode[pil]` | 게스트 대시보드 QR 생성 |
| `piper-tts` | 로컬 한국어 TTS 음성 안내 |
| `ai-edge-litert` | TFLite 인터프리터 (Thermal · CO₂ 모델) |
| `torch` | mmWave B23 PyTorch float32 모델 |
| `numpy`, `scipy`, `pandas`, `scikit-learn`, `joblib`, `matplotlib`, `Pillow` | 전처리·수치 연산 |
| `spidev`, `smbus2` | Raspberry Pi SPI/I²C |

`torch` 는 반드시 공식 CPU wheel index
(`https://download.pytorch.org/whl/cpu`) 를 함께 사용한다.
일반 PyPI 의 ARM64 배포본은 Raspberry Pi 에 없는 CUDA/NVIDIA 의존성을 끌어온다.

## 4. TTS 음성 모델

| 항목 | 값 |
|---|---|
| 음성 | `ko_KR-kss-medium` (Piper) |
| 취득 | `./run_safenest.sh --install` 이 `piper.download_voices` 로 내려받음 |
| 저장 위치 | `RaspberryPi/Runtime/data/tts/` — **Git 미추적** |
| 라이선스 | 음성 데이터셋 **CC BY-NC-SA 4.0** (저장소 내 `RaspberryPi/Runtime/deployment/run_pi.sh` 주석에 기록) |

비상업적 조건이 있어 모델 바이너리를 저장소에 포함하지 않는다.

## 5. 온디바이스 AI 모델의 학습 데이터 출처

학습에 사용한 원본 데이터셋은 **이 저장소에 포함하지 않는다.**
배포되는 것은 학습 결과 아티팩트(`.tflite` / `.pt`)와 계약 메타데이터뿐이다.

### 5.1 Thermal — 활성 모델 `thermal_public_sdt_fp32_active`

| 항목 | 값 |
|---|---|
| 데이터셋 | SDT Dataset (Simulated/real thermal-depth posture dataset, TU Wien CVL) |
| 공식 문서 | https://cvl.tuwien.ac.at/research/cvl-databases/sdt-icip/ |
| 배포 기록 | https://zenodo.org/records/4124309 (doi:10.5281/zenodo.4124309) |
| 원 라벨 | `LYING`, `SITTING`, `STANDING`, `EMPTY_ROOM` |
| 이용 조건 | **비상업적 연구 목적 + 출처 표시**. 원 배포처 조건을 따른다 |
| 저장소 포함 여부 | 원본 아카이브 미포함 (모델 아티팩트만 포함) |

SafeNest 3-class(`NOT_HUMAN` / `HUMAN_NORMAL` / `HUMAN_FALL_PROXY`)는
SDT 자세 라벨에서 파생한 **proxy** 매핑이며, 실제 낙상 이벤트 라벨이 아니다.

### 5.2 CO₂ — 활성 모델 `co2_occupancy_c_b6`

| 항목 | 값 |
|---|---|
| 데이터셋 | UCI Occupancy Detection Dataset |
| 공식 출처 | https://archive.ics.uci.edu/dataset/357/occupancy+detection |
| 원 논문 | Candanedo, L. M., & Feldheim, V. (2016). *Accurate occupancy detection of an office room from light, temperature, humidity and CO2 measurements using statistical learning models.* Energy and Buildings, 112, 28–39 |
| 이용 조건 | UCI Machine Learning Repository 배포 조건 — 원 출처 확인 필요 |
| 저장소 포함 여부 | 원본 아카이브 미포함 (모델 아티팩트만 포함) |

의미 범위는 **실내 재실(occupancy) 판정**이며, 질식·유해가스 ground truth가 아니다.

### 5.3 mmWave — 활성 모델 `mmwave` (M-PROT-B23)

| 항목 | 값 |
|---|---|
| 데이터 | 팀이 MR60BHA2 로 직접 수집한 `breath_phase` 파형 |
| 외부 데이터셋 | 사용하지 않음 |
| 저장소 포함 여부 | 원 캡처 로그 미포함 (모델 아티팩트 + scaler 통계만 포함) |

## 6. 웹 프론트엔드에 포함한 외부 자산

관리자 화면의 추이 그래프에 사용하는 Chart.js 를 저장소에 포함(vendoring)했다.
외부 인터넷이 없는 현장에서도 동작해야 하기 때문이다.

| 항목 | 값 |
|---|---|
| 구성요소 | **Chart.js** |
| 버전 | **4.5.1** (고정) |
| 포함 경로 | `RaspberryPi/Web/vendor/chart.js/chart.umd.min.js` |
| 서빙 경로 | `/vendor/chart.js/chart.umd.min.js` (백엔드 same-origin) |
| 크기 · SHA-256 | 208,522 bytes · `48444a82d4edcb5bec0f1965faacdde18d9c17db3063d042abada2f705c9f54a` |
| 취득처 | `https://cdn.jsdelivr.net/npm/chart.js@4.5.1/dist/chart.umd.min.js` (공식 npm 배포본) |
| 저작권 | (c) Chart.js Contributors — https://www.chartjs.org |
| **라이선스** | **MIT** — 전문은 `RaspberryPi/Web/vendor/chart.js/LICENSE.md` |

번들에 포함된 의존성:

| 구성요소 | 버전 | 저작권 | 라이선스 |
|---|---|---|---|
| @kurkle/color | 0.3.2 | (c) 2023 Jukka Kurkela | MIT (배포본 배너에 명시) |

배포본은 수정하지 않고 원본 바이트 그대로 포함했다. 위 SHA-256 은 취득 시점의
공식 배포본과 일치하며, `.gitattributes` 에서 줄바꿈 정규화를 제외해 바이트
동일성을 유지한다.

그 외 웹·LCD 자산(HTML/CSS/JS, 아이콘, 폰트)은 모두 SafeNest 팀이 작성했고
외부 호스트를 참조하지 않는다. 현재 제출본의 웹·LCD 화면은 **외부 네트워크
자산을 하나도 참조하지 않는다.**

## 7. 이 저장소 자체의 라이선스

프로젝트 라이선스는 **아직 지정되지 않았다.** 별도로 결정한다.
라이선스가 없는 동안 위 3항의 외부 구성요소 조건은 그대로 유효하며,
5항 데이터셋의 비상업적/출처표시 조건은 어떤 경우에도 지켜야 한다.

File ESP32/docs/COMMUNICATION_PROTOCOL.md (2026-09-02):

# SafeNest 통신 규격 요약

## 포트

| 용도 | 프로토콜 | 기본 포트 | 방향 |
|---|---|---:|---|
| 센서 데이터 | TCP | 9000 | ESP32 → Raspberry Pi |
| Thermal frame | UDP | 5005 | ESP32 → Raspberry Pi |
| LCD/API | HTTP | 8000 | LCD·노트북 → Raspberry Pi |

## TCP 패킷 헤더

모든 정수는 네트워크 바이트 순서(big-endian)입니다. 헤더 크기는 16바이트입니다.

| 오프셋 | 크기 | 필드 | 값/설명 |
|---:|---:|---|---|
| 0 | 4 | magic | ASCII `SNST` |
| 4 | 1 | version | `1` |
| 5 | 1 | type | `1`: telemetry JSON, `2`: thermal frame |
| 6 | 2 | flags | v1에서는 `0` |
| 8 | 4 | sequence | 패킷 순번 |
| 12 | 4 | payload_length | 뒤따르는 payload의 바이트 수 |

TCP는 패킷 경계를 보존하지 않으므로 Raspberry Pi는 `recv_exact()`로 헤더와 payload 길이만큼 끝까지 읽습니다.

## Type 1: 센서 telemetry JSON

스키마 이름은 `safenest.telemetry.v1`입니다.

```json
{
  "schema": "safenest.telemetry.v1",
  "device_id": "esp32-01",
  "boot_id": "0123456789abcdef0123456789abcdef",
  "seq": 42,
  "uptime_ms": 12345,
  "resp_rate_bpm": 16.25,
  "heart_rate_bpm": 72.5,
  "co2_ppm": 820,
  "co2_measurement_event_id": 42,
  "co2_measurement_monotonic_ms": 12000,
  "co2_measurement_event_valid": true,
  "pir_motion": true,
  "pir_event_id": 3,
  "pir_last_transition_monotonic_ms": 11500,
  "valid": {
    "respiration": true,
    "heart": true,
    "co2": true
  },
  "health": {
    "telemetry_queue_overwrites": 0,
    "thermal_queue_overwrites": 0,
    "tcp_connection_failures": 0,
    "tcp_send_failures": 0,
    "thermal_udp_frames_sent": 42,
    "thermal_udp_send_failures": 0,
    "co2_data_ready_query_failures": 0,
    "co2_read_failures": 0,
    "thermal_status_query_failures": 0
  }
}
```

유효하지 않거나 아직 측정되지 않은 수치 값은 `null`로 보냅니다. `valid` 플래그와 값을 함께 확인해야 합니다. 기존 v1 sender의 확장 필드 부재는 허용하지만, 새 sender의 `boot_id + co2_measurement_event_id`가 실제 측정의 reboot-safe identity입니다. 같은 event ID가 약 1초마다 재전송되어도 새 물리(또는 추론) 측정으로 중복 계산하지 않습니다.

### CO₂ 계측기 (SCD4x와 MH-Z19B)

**이 저장소가 포함하는 sender 는 MH-Z19B 하나뿐입니다** (`ESP32/Arduino/esp32_sensor_node/`). 아래 표의 SCD4x 열은 같은 프로토콜을 쓰던 이전 팀 변형으로, 제출본에 포함하지 않았습니다. 대조해 두는 이유는 event identity 의미가 서로 다르고, 이어지는 규칙이 그 차이를 전제하기 때문입니다.

**ppm 단위가 같다고 drop-in 호환이 아닙니다.** Pi는 계속 `co2_ppm`과 event identity로 150 s slope를 재구성하며, ESP32는 slope/점유 모델을 돌리지 않습니다. C-B6 threshold 0.43과 모델 아티팩트는 이 프로토콜 변경으로 건드리지 않습니다.

| CO₂ 센서 | 제출본 포함 | 버스 | 이벤트 정체성 |
|---|---|---|---|
| Winsen MH-Z19B | **예 — 정본 sender** | UART1 9600 8N1, ESP32 RX=32 / TX=33 (**MR60 UART2 16/17과 공유 금지**) | **INFERRED_UART_SAMPLE**. manufacturer data-ready 없음. checksum-valid `0x86`를 선언된 UART poll 주기(기본 5 s)당 최대 1회 수락한 뒤에만 `co2_measurement_event_id` 증가. 이 주기는 물리 NDIR 변환 주기가 아님 |
| Sensirion SCD40/SCD4x | 아니오 — 이전 변형 | I²C `0x62`, SDA=21 SCL=22 | SCD4x `getDataReadyStatus` 후 성공한 `readMeasurement`만 새 이벤트. `co2_ppm==0`은 이벤트 아님 |

MH-Z19B sender는 다음 필드를 추가로 보냅니다.

```json
{
  "firmware_version": "safenest-esp32-sensor-node/1.7.0-mhz19b.1",
  "co2_sensor_model": "MH-Z19B",
  "co2_event_identity_class": "INFERRED_UART_SAMPLE",
  "co2_measurement_event_id": 42,
  "co2_measurement_monotonic_ms": 180000,
  "co2_measurement_event_valid": true,
  "co2_preheat": false
}
```

규칙:

- checksum 실패, timeout, short frame, 예열(3분), stale(`CO2_STALE_MS` 15 s)에서는 `co2_ppm`이 `null`이고 `valid.co2=false`이며, event tuple은 프로토콜이 요구하는 `0 / 0 / false`입니다.
- `valid.co2`(최근 성공이 stale 한도 안)와 `co2_measurement_event_valid`(이번 snapshot이 그 이벤트를 현재로 실어도 되는지)는 다릅니다.
- `co2_event_identity_class`가 `INFERRED_UART_SAMPLE`이면 SCD40 conversion이라고 기록하지 마십시오. 두 센서를 한 device-domain으로 풀링하지 않습니다.
- MH-Z19B는 Vin 4.5–5.5 V(피크 150 mA)가 필요합니다. ESP32 3.3 V 레일로 켜지 않습니다.

## Thermal UDP v1 logical frame

payload는 16바이트 metadata 다음에 80 × 62개의 `uint16` 픽셀이 이어집니다.

| 오프셋 | 크기 | 필드 |
|---:|---:|---|
| 0 | 2 | width (`80`) |
| 2 | 2 | height (`62`) |
| 4 | 4 | frame_sequence |
| 8 | 4 | uptime_ms |
| 12 | 2 | minimum_raw |
| 14 | 2 | maximum_raw |
| 16 | 9,920 | 픽셀 4,960개, 각 `uint16` big-endian |

logical payload 9,936바이트는 1,168바이트 이하 payload를 가진 9개 UDP datagram으로 나뉩니다. 각 32바이트 UDP header는 `SNTU`, version 1, frame sequence, chunk index/count, logical size/offset/length와 logical-frame CRC32를 포함합니다. Pi는 순서와 무관하게 bounded reassembly한 뒤 CRC32, shape, payload length와 min/max를 모두 검증합니다. Thermal은 TCP로 보내지 않습니다.

## Sequence와 시간 의미

- TCP telemetry `seq`: scalar publication 때 증가
- `co2_measurement_event_id`: SCD4x sender는 새 `readMeasurement` 성공 때만 증가. MH-Z19B sender는 checksum-valid `0x86`를 선언된 UART poll 주기로 수락했을 때만 증가(`INFERRED_UART_SAMPLE`). 어느 sender든 1 Hz TCP 재전송에서는 증가하지 않음
- Thermal `frame_sequence`: frame 획득 때 증가
- Thermal `chunk_index`: 동일 frame 안의 chunk 위치이며 sequence가 아님
- `pir_event_id`: PIR 상태 전환 때만 증가
- ESP `uptime_ms`와 event time은 source monotonic domain, Pi 수신 wall/monotonic time은 receiver domain이며 clock synchronization을 가정하지 않음

`health`는 scalar/thermal queue overwrite, TCP connect/send failure, Thermal UDP frame send success/failure와
센서 취득 경로에서 실제로 관찰된 실패의 누적값을 담는다. SCD4x sender의 `co2_data_ready_query_failures`는
`getDataReadyStatus` API 오류만 세며 정상적인 `not-ready` 응답은 실패가 아니다. `co2_read_failures`는
`readMeasurement` 오류만 세고, 성공했지만 유효한 CO₂ 값이 없는 경우에는 새 measurement event를 만들지
않는다. MH-Z19B v2-port sender는 slim LCD JSON에 `health` 객체를 넣지 않으며, UART checksum/timeout/short
frame 카운터는 Serial `[health] co2` 줄에만 남긴다. `thermal_status_query_failures`는 READY 핀 fallback에서
실제 I2C status query가 실패한 경우만 센다. Queue overwrite는 소비 task가 dequeue한 sequence gap으로
계산하므로 실제로 건너뛴 one-slot queue item만 센다.

현재 MI48xx/SPI 경로는 독립적인 acquisition result나 camera-native CRC를 제공하지 않는다
(`THERMAL_ACQUISITION_ERROR_DETAIL_UNAVAILABLE`). 따라서 그런 값을 꾸며내지 않는다. SafeNest logical-frame
CRC32와 Pi reassembly failure는 별도 metric이다.

## HTTP API

| 메서드 | 경로 | 설명 |
|---|---|---|
| GET | `/display` | Raspberry Pi LCD 화면 |
| GET | `/control` | 노트북 원격 제어 화면 |
| GET | `/api/state` | 화면 상태와 최신 센서 데이터 |
| POST | `/api/state` | 화면 상태 또는 공간 이름 변경 |
| GET | `/health` | 서버, 부저, 센서 연결 상태 |

상태 변경 예시 (`SAFENEST_DEMO_MODE=1` 로 기동했을 때만 열리는 데모 전용 경로):

```bash
curl -s -X POST http://127.0.0.1:8000/api/state \
  -H 'Content-Type: application/json' \
  -d '{"state":"emergency"}'
```

허용 상태:

- `normal-empty`
- `normal-occupied`
- `warning`
- `danger`
- `emergency`
- `offline`

## 장애 확인 순서

1. Raspberry Pi에서 `ss -ltn | grep ':9000 '`으로 TCP 수신 포트를 확인합니다.
2. ESP32 시리얼 로그에서 Wi-Fi 연결과 `Raspberry Pi connected`를 확인합니다.
3. `/health`의 `sensors.status`, `peer`, `age_seconds`, `listener_error`를 확인합니다.
4. HTTP 서버는 정상이지만 LCD가 보이지 않으면 `logs/chromium.log`를 확인합니다.
5. 종료할 때는 `bash stop_lcd.sh`를 사용합니다.

## Pi ingest note (MH-Z19B, 2026-08-31)

ESP32 스케치 변경은 PR #68 (`feature/esp32-mhz19b-co2-v2-port`)으로 `main`에 들어갔습니다. 이 절은 Raspberry Pi 수신만 적습니다.

Pi Runtime은 아래 필드를 `safenest.telemetry.v1`의 **optional** 확장으로 파싱합니다. 없으면 거절하지 않습니다.

- `co2_sensor_model` (`MH-Z19B`)
- `co2_event_identity_class` (`INFERRED_UART_SAMPLE`; SCD40 `getDataReady` 변환이 아님)
- `co2_preheat_complete` (bool). 펌웨어가 `co2_preheat`만 보내면 Pi가 같은 의미로 매핑합니다.
- `abc_enabled`, `configured_range_ppm` (`2000` / `5000` / `10000`)

H150(`CO2_slope`, 150 s endpoint difference)은 `co2_measurement_event_id`만 이력 키로 씁니다. Pi는 `seq`, `/health`의 `fresh`, `age_seconds`로 event id를 만들지 않습니다. `co2_preheat_complete`가 true가 아니면 C-B6 입력에 넣지 않습니다. 수식·scaler·threshold 0.43은 그대로입니다.

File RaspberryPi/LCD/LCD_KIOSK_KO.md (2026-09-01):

# LCD 키오스크 실행 방법

Raspberry Pi 에 연결된 LCD 에 SafeNest 상태 화면을 띄우고 내리는 방법이다.

LCD 화면은 별도 서버가 아니라 **SafeNest 통합 백엔드(`:8000`)가 직접 서빙**한다.

| 경로 | 파일 |
|---|---|
| `http://127.0.0.1:8000/display` | `RaspberryPi/LCD/static/display.html` |
| `http://127.0.0.1:8000/common.css` | `RaspberryPi/LCD/static/common.css` |

화면은 `GET /api/state` 를 주기적으로 폴링해 갱신한다. 별도의 LCD 서버 프로세스는 없다.

## 1. 백엔드 확인

```bash
pgrep -af run_backend.py || true
curl -fsS http://127.0.0.1:8000/health
curl -fsS -o /dev/null http://127.0.0.1:8000/display
```

백엔드가 실행 중이 아니면 저장소 루트에서 시작한다.

```bash
mkdir -p logs
nohup bash ./run_safenest.sh > logs/runtime.log 2>&1 &
echo $! > .runtime.pid
```

## 2. LCD 화면 켜기

```bash
export DISPLAY=:0
export WAYLAND_DISPLAY=wayland-0
export XDG_RUNTIME_DIR=/run/user/1000
[ -f "$HOME/.Xauthority" ] && export XAUTHORITY="$HOME/.Xauthority"

pkill -f "chromium.*8000/display" 2>/dev/null || true

nohup chromium --kiosk --noerrdialogs --disable-infobars \
  --check-for-update-interval=31536000 \
  --user-data-dir=/tmp/safenest-chromium-display \
  --ozone-platform=x11 \
  http://127.0.0.1:8000/display \
  >/tmp/chromium-display.log 2>&1 &
```

## 3. 화면만 끄기

통합 백엔드는 유지하고 Chromium 만 종료한다.

```bash
pkill -f "chromium.*8000/display" 2>/dev/null || true
```

## 4. 화면과 백엔드 모두 끄기

```bash
pkill -f "chromium.*8000/display" 2>/dev/null || true
kill "$(cat .runtime.pid)" 2>/dev/null || true
pkill -f "backend/run_backend.py" 2>/dev/null || true
```

## 5. 실행 확인

```bash
pgrep -af "chromium.*8000/display" | head -3
curl -fsS http://127.0.0.1:8000/health
```

## 6. 데모용 수동 상태 전환 (선택)

`SAFENEST_DEMO_MODE=1` 로 백엔드를 실행하면 `http://<pi>:8000/control` 조작
화면이 함께 열리고, `POST /api/state` 로 LCD 표시 상태를 수동 전환할 수 있다.
평시 운영에서는 사용하지 않는다.

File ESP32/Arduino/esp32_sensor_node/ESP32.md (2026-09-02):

# ESP32 MH-Z19B v2 포트 변경 로그

## 범위

이 스케치는 SCD40/SCD4x I²C 를 쓰던 v2 스케치를 **제자리에서 덮어쓰지 않고** 복사한 뒤, CO₂ 계측만 Winsen MH-Z19B UART 로 바꾼 것에서 출발했습니다. 아래 변경 이력의 폴더명은 각 버전 당시의 이름이며, 현재 정본 위치는 다음과 같습니다.

- 폴더: `ESP32/Arduino/esp32_sensor_node/`
- 펌웨어: `safenest-esp32-sensor-node/1.7.10-mhz19b.1` (`esp32_sensor_node.ino` 의 `NODE_FIRMWARE_VERSION`)
- 출발점이던 SCD40 v2 스케치는 이 제출 저장소에 포함하지 않았습니다.

모델 재학습, threshold 0.43, C-B6 scaler/TFLite, ESP32 쪽 slope/점유 모델은 **범위 밖**입니다. Pi `RaspberryPi/Runtime/ai/co2_canonical_runtime.py`가 이미 ENDPOINT_H150 / 150 s slope를 재구성합니다.

## 배선 / 전원 (MH-Z19B)

Winsen MH-Z19B User’s Manual v1.7 (2020-10-15) 기준입니다. 임의 블로그가 아닙니다.

| 항목 | 값 | 주의 |
|---|---|---|
| Vin | 4.5–5.5 V DC | **ESP32 3.3 V 레일에서 켜지 말 것.** 피크 150 mA |
| UART | 9600 8N1 TTL 3.3 V (5 V 호환) | TX/RX **교차** |
| 이 스케치 UART | **UART1** GPIO **32 (RX)** / **33 (TX)** | MR60 UART2 GPIO **16/17을 절대 공유하지 않음** |
| PWM | 미사용 | PWM 주기(~1 s)를 UART 변환 주기로 취급하지 않음 |
| HD | 미연결 | 잠긴 교정 정책이 생기기 전에는 쓰지 않음 |
| 예열 | 3분 | 예열 중 TCP 패킷은 나가지만 모델 측정으로 표시하지 않음 |

핀을 32/33으로 고른 이유: v2 핀맵(I²C 21/22, PIR 13, Thermal SPI/I2C 18/19/23/27/26/25, MR60 16/17) 이후 남는 출력 가능 GPIO이고, WROOM 플래시/스트래핑 핀이 아닙니다. `HardwareSerial(1).setPins()`를 `begin()` 전에 호출해 기본 9/10(플래시)을 피합니다.

공통 GND는 ESP32와 5 V 공급을 함께 묶습니다.

## ABC / 측정 범위

- Winsen 문서상 출하 ABC는 **ON** (24 h, 400 ppm). 이 스케치는 `0x79`를 **보내지 않습니다.** 의도 상태는 factory default ON입니다.
- 범위 명령 `0x99`도 **보내지 않습니다.** 모듈 variant를 실측으로 증명하기 전입니다.
- 수용 상한은 **10000 ppm** (0은 fail-closed). UCI 학습이 2076 ppm까지 갔으므로 2000 ppm 클립을 가정하지 않습니다. 구성된 실측 범위는 **미확인**이며 5000 ppm class를 선호할 뿐입니다.
- SCD40 숫자에 맞추려고 ABC를 켜고 끄는 “같아 보일 때까지 교정”은 구현하지 않았습니다.

ppm 단위가 같다고 drop-in 호환이 **아닙니다.** 감사 결론은 `COMPATIBLE_ONLY_AS_NEW_DEVICE_DOMAIN` / PATH B, 재학습 NO, threshold 0.43 유지입니다.

## 이벤트 정체성 (INFERRED_UART_SAMPLE)

MH-Z19B에는 SCD4x `getDataReadyStatus`가 없습니다. 공식 문서는 각 `0x86` 응답이 새 NDIR 변환임을 증명하지 않습니다. 반복 UART 읽기는 최신 가용 값을 돌려줍니다.

따라서 이 노드는 **추론된** producer identity를 붙입니다.

| JSON 필드 | 의미 |
|---|---|
| `co2_sensor_model` | `"MH-Z19B"` |
| `co2_event_identity_class` | `"INFERRED_UART_SAMPLE"` — SCD40 conversion이라고 주장하지 않음 |
| `co2_measurement_event_id` | checksum-valid `0x86`를 **선언된 UART poll 주기당 최대 1회** 수락했을 때만 증가. wrap 시 0 건너뜀 |
| `co2_measurement_monotonic_ms` | 수락 시점의 `millis()` |
| `co2_measurement_event_valid` | 그 샘플이 stale/예열이 아닐 때만 true. 아니면 `0/0/false` |
| `co2_preheat` | boot 후 180 s 동안 true (지금 예열 중) |
| `co2_preheat_complete` | `!co2_preheat`. Pi C-B6 게이트. canonical이 있으면 alias를 이긴다 |
| `valid.co2` | 예열 종료 후 마지막 성공이 `CO2_STALE_MS`(15 s) 안. **새 이벤트와 다름** |

정책:

- 선언된 UART 샘플 주기: `CO2_UART_SAMPLE_PERIOD_MS = 5000`. SCD4x가 ~5 s였고 PWM 인코딩은 ~1 s라서 그 사이에 맞춘 것입니다. **UART poll rate = 물리 변환 rate가 아닙니다.**
- 1 Hz TCP snapshot마다 event_id를 올리지 않습니다. 같은 event_id는 캐시 재전송이며 Pi slope가 무시해야 합니다.
- ppm이 안 변할 때만 올리는 방식은 쓰지 않습니다(빈 방이 영원히 freeze됨).
- checksum 실패 / timeout / short frame → 추정 ppm을 발행하지 않음. JSON `co2_ppm`은 `null`, `valid.co2=false`.
- stale ppm을 새 이벤트로 forward-fill하지 않음.
- 3분 예열: 패킷은 계속 나가지만 `event_valid=false`, `valid.co2=false`.

ESP32는 slope를 계산하지 않습니다.

## v2에서 유지한 것

- MR60 UART2 16/17, `human_detected_raw` 3상태 null/true/false
- Thermal SPI/I2C/UDP 계약, PIR
- TCP `safenest.telemetry.v1`, FreeRTOS TCP/UDP, backpressure / mutex
- loop에 `delay()` 없음, `millis()` 스케줄
- 무효 수치는 JSON `null`
- `secrets.h` 미커밋

## 검증 및 제한

- v2 대비 차이는 CO₂ 드라이버와 그에 필요한 JSON 필드에 한정되도록 정적 비교했습니다.
- JSON `snprintf` truncation은 전송 실패(fail-closed). 호스트에서 worst-case payload < 1024 B를 확인합니다.
- Arduino CLI가 있으면 이 스케치를 컴파일합니다.
- **실기 flash / MH-Z19B UART ppm 관측은 이 작업에서 수행하지 않았습니다.** `DEVICE_VALIDATED=NO`.
- 잔여 위험: ABC 출하 상태, 범위 variant(2000/5000/10000), manufacturer data-ready 부재.

## 1.7.1 — UDP 청크 양보 + 주기 힙 회수

MH-Z19B 스케치는 PR #71 청크 양보가 빠져 있었고, 9개 UDP datagram을 2 ms 간격으로 연속 송신하면 lwIP 풀이 차고 TCP 1 Hz JSON이 밀렸습니다. 힙이 ~40 KB 떨어지는 현상과 같은 경로입니다.

- 청크 사이 `UDP_CHUNK_GAP_MS = 20`. TCP가 그 틈에 mutex를 잡고 JSON을 보냅니다.
- TCP write/connect 중이면 같은 청크를 버리고 끝내지 않고 기다렸다가 이어서 보냅니다 (`yieldRadioToTcp`). 센서 JSON 값/시퀀스는 바꾸지 않습니다.
- 5초마다, 또는 free heap이 48 KB 아래로 떨어지면 thermal UDP 소켓만 `stop()`/`begin()` 해서 lwIP pbuf를 돌려줍니다. TCP 클라이언트와 큐에 있는 telemetry JSON은 건드리지 않습니다. TCP가 보내는 중이면 회수를 건너뜁니다.
- 펌웨어 id: `safenest-esp32-sensor-node/1.7.1-mhz19b.1`

## 1.7.2 — mmWave 0.0 vs stale null

`[health] sensors resp=0.0`는 Pi의 `nan`/`null`과 다른 의미였습니다. 헬스는 마지막 캐시를 stale 검사 없이 찍고, `mmw_miss`는 레이더 고장이 아니라 `update(0)`이 빈 UART에서 false를 준 루프 횟수였습니다.

- 헬스 `resp`/`heart`는 TCP와 같이 10 s stale이면 `null`. `resp_age_ms` / `heart_age_ms` / `presence_age_ms`를 같이 찍습니다.
- `mmw_miss`는 UART에 바이트가 있는데 프레임이 안 열릴 때만 증가합니다.
- thermal SPI 전후에 mmWave를 drain합니다.
- 레이더가 보낸 0.0 bpm(미검출)은 그대로 0.00으로 둡니다. 0을 숨기지 않습니다.

## 1.7.4 — MR60 breath_phase 복구 (Pi 300윈도우)

LCD 슬림 JSON이 `mmwave.human_detected_raw`만 남겨서 Pi M-N4/B23 창이 한 샘플도 못 쌓았습니다. 벤더 `resp_rate_bpm`은 창에 들어가지 않습니다.

- `pollMmWave()`가 다시 `getHeartBreathPhases()`를 호출합니다 (0x0A13).
- JSON `mmwave`에 1.3.0과 같은 `breath_phase` / `total_phase` / `heart_phase` / `breath_rate_raw` / `phase_age_ms` / `ts_monotonic_ms` / `seq` / `schema_version`을 넣습니다. MH-Z19B 이벤트 필드는 유지합니다.
- 위상 값은 `PHASE_MAX_AGE_MS = 500` 안에서만 숫자로 나갑니다. seq/시각은 마지막 샘플이 있으면 남깁니다.
- `TELEMETRY_PERIOD_MS`를 1000 → 100으로 되돌립니다. 1 Hz면 500 ms freshness에 걸려 `breath_phase`가 거의 항상 null입니다.
- JSON 버퍼 1536 B. 펌웨어 id: `safenest-esp32-sensor-node/1.7.4-mhz19b.1`

## 1.7.5 — 부분 TCP 패킷 스킵

UDP를 꺼도 TCP가 `wrote=97/808 errno=11`로 세션을 닫고, 실패 로그가 Serial mutex를 잡아 MR60 파서가 풀렸습니다.

- 한 바이트도 못 나가면 40 ms 후 그 스냅샷만 버리고 소켓은 유지.
- 이미 나간 부분 패킷만 200 ms 안에 끝내고, 실패 시 세션 종료.
- `[tcp-drop]`/`[tcp-send-fail]`/`[tcp-send-timeout]`는 1초에 한 줄.
- `u`로 UDP를 끄면 SPI capture도 같이 멈춤.
- 펌웨어 id: `safenest-esp32-sensor-node/1.7.5-mhz19b.1`

## 1.7.6 — TCP 원자 송신 + 로컬 mmWave 프레임 조립

1.7.5를 켠 부팅 로그에서 mmWave는 180 s 동안 `phase=nan` / `mmw_ok=0`이었고, TCP는 `wrote=186/794 errno=11`로 세션을 닫은 뒤 `connect_ms=1502 errno=119` 폭풍이 났습니다. thermal UDP는 기본이 켜져 있었습니다.

- 첫 `lwip_send`가 0 바이트면 재시도하지 않고 스냅샷만 건너뜀. 40 ms 동안 EAGAIN을 기다리다가 186 바이트만 나가는 경로를 없앰.
- thermal UDP/capture 기본 OFF. 시리얼 `u` 다음에 `c`.
- 부분 송신으로 소켓을 닫은 뒤 300 ms를 기다리고 다시 SYN.
- Seeed `fetch()`의 static `startFrame`을 쓰지 않음. UART2를 로컬 조립하고 100 ms 미완성 프레임은 버림. 5 s 동안 `mmw_ok=0`이면 `[mmw-rx]` hex dump.
- 펌웨어 id: `safenest-esp32-sensor-node/1.7.6-mhz19b.1`
- 스케치 폴더: `ESP32/Arduino/esp32_sensor_node_mhz19b_20260901-0431-junwoo/`

## 1.7.10 — 열화상 런타임 재초기화

1.7.9는 `initializeThermalCamera()`를 `setup()`에서만 호출한다. 부팅 때 MI48가 I2C에 없으면 `thermalStarted`가 false로 남고, 카메라가 나중에 켜져도 프레임이 0이다. 현장은 시리얼 입력을 전제로 하지 않는다.

- 루프가 2초마다 상태를 본다. 캡처가 7초 멈추거나 시작 실패면 GPIO25를 **먼저** 리셋하고 그다음 0x40/0x41을 본다. I2C ACK를 기다렸다가 리셋하면, 버스에서 빠진 MI48는 영원히 STALE이다.
- 캡처가 돌고 있으면 카메라를 건드리지 않는다.
- 시리얼 `t`는 디버그 강제 재init일 뿐이고, 복구 조건이 아니다.
- `c`/`u`로 끈 상태는 죽은 카메라로 보지 않는다.
- 펌웨어 id: `safenest-esp32-sensor-node/1.7.10-mhz19b.1`
- 스케치 폴더: `ESP32/Arduino/esp32_sensor_node/`

## 1.7.9 — C-B6 H150 예열 극성

1.7.8은 `co2_preheat`(예열 중 true)만 보냈다. Pi는 그 필드를 반전 없이 `co2_preheat_complete`로 써서, 예열이 끝나면 모델 입력이 영원히 0건이 된다.

- JSON에 `co2_preheat_complete`를 `!co2_preheat`로 보낸다. Pi는 canonical을 우선한다.
- `co2_preheat` 의미는 그대로(180 s 동안 true). Pi 코드는 안 바꾼다.
- 펌웨어 id: `safenest-esp32-sensor-node/1.7.9-mhz19b.1`
- 스케치 폴더: `ESP32/Arduino/esp32_sensor_node_mhz19b_20260901-1958-junwoo/`

## 1.7.8 — TCP 다운 시 thermal capture 정지 해제

1.7.7은 `tcpLinkHealthy`가 false면 SPI capture까지 멈췄다. UDP send는 이미 `TCP_CRITICAL_BIT`에 양보하므로, 재연결 동안 capture를 끄면 Pi thermal만 STALE이 되고 TCP는 그대로 흔들렸다.

- `captureThermalIfReady()`에서 `tcpLinkHealthy` 가드를 뺀다. UDP가 꺼져 있으면 (`u`) SPI는 여전히 안 한다.
- thermal UDP/capture 기본 ON. 시리얼 `u`/`c`로 끌 수 있다.
- UDP send의 `tcpLinkHealthy` defer와 `yieldRadioToTcp`는 그대로. 캡처만 계속하고, 세션이 내려가 있으면 송신은 미룬다.
- 펌웨어 id: `safenest-esp32-sensor-node/1.7.8-mhz19b.1`
- 스케치 폴더: `ESP32/Arduino/esp32_sensor_node_mhz19b_20260901-1921-junwoo/`

## 1.7.7 — AP 업링크 TCP 유지

SafeNest-ESP에서 Pi가 ESP를 −80 dBm으로 듣고 ARP/SYN이 깨진 뒤 `connect_ms=1503 errno=119` 폭풍이 났습니다. 리셋만으로는 같은 패턴이 반복됩니다.

- STA TX를 `WIFI_POWER_19_5dBm`으로 고정. Pi가 ESP를 듣게 하는 방향.
- connect timeout 1.5 s → 4 s. 실패 후 2.5 s 대기. 5연속 실패 시 `WiFi.reconnect()`.
- 부분 송신 후 재SYN 대기를 300 ms → 2 s. SYN-RECV 적체 완화.
- 펌웨어 id: `safenest-esp32-sensor-node/1.7.7-mhz19b.1`

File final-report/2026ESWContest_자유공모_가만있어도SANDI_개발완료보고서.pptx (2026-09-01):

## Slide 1

제24회 임베디드SW경진대회 개발완료보고서

자 유 공 모 부 문

SafeNest

엣지 AI 기반 밀폐공간·차량 생명감지 및 위험도 자동경보 시스템

가만있어도SANDI

경희대학교 전자공학과

김진수 · 유승하 · 김태균 · 한준우 · 강유나

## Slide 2

Ⅰ. 개발 개요

1.1 밀폐공간 질식재해 현황과 개발 필요성

재해 통계 (최근 10년, 2014~2023)

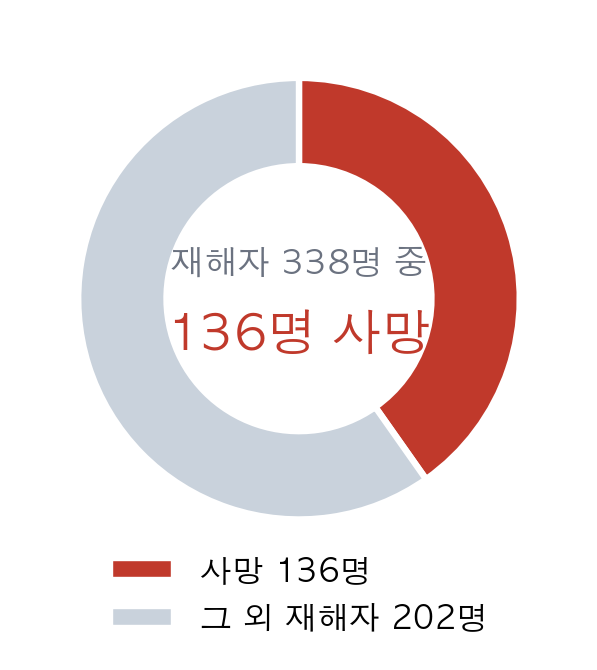
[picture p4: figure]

밀폐공간 질식재해 발생 건수

174건

제도와 현실의 간극

· 산업안전보건법 제619조는 밀폐공간 작업 시 산소·유해가스 농도 측정과 감시인 배치를 사업주 의무로 규정한다.

· 중대재해처벌법 확대 적용으로 소규모 사업장까지 예방 설비 수요가 늘었다.

· 감시인 상시 배치가 어려운 소규모 사업장이 대다수여서, 사람의 상태까지 자동으로 확인하는 무인 감시 수단이 필요하다.

재해자

338명

사망자

136명

검찰 송치 중대재해 중
산소·유해가스 농도 미측정 상태에서 발생

85.7%

사고 진행 단계와 현재 감시 수단의 공백

가스 감지기·PIR·CCTV가 사람의 상태를 놓치는 구간

작업자 진입

밀폐공간 내부

이상 발생

산소결핍·유해가스

움직임 정지

스스로 신고 불가

▼

발견 지연

감시인 부재

▼

사고 확정

구조 골든타임 경과

▶

▶

▶

▶

SafeNest는 이 구간에서 사람의 존재와 상태를 자동으로 확인하고 현장에 경보를 낸다.

※ 출처 : 고용노동부 밀폐공간 질식재해 예방 보도자료(2024), 경향신문 밀폐공간 중대재해 분석 보도(2025). 법령 : 산업안전보건법 제619조.

SafeNest · 가만있어도SANDI

1

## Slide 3

Ⅰ. 개발 개요

1.2 기존 감지 방식의 한계

감지 방식 | 정지 인체 | 사생활 보호 | 착용 불필요 | 환경 위험 감시 | 한계
가스 감지기 | × | ○ | ○ | ○ | 공기질만 측정하므로 사람의 존재를 알지 못한다
CCTV | △ | × | ○ | × | 정지 인체 판별이 어렵고 사생활 침해 소지가 크다
PIR 센서 | × | ○ | ○ | × | 움직일 때만 감지하여 쓰러진 사람을 놓친다
웨어러블 | ○ | ○ | × | × | 착용과 충전에 의존하며 미착용 시 무력하다
단일 mmWave | ○ | ○ | ○ | × | 환경 위험을 모르고 비생체 반사와 구분이 어렵다
단일 열화상 | △ | ○ | ○ | × | 히터·기계 열원과 사람의 구분이 어렵다

공백의 성격

여섯 가지 방식은 각각 다른 이유로 실패한다. 공통점은 하나다. 센서가 값을 내지 못하거나 값이 오래된 상황을 스스로 인지하지 못한다는 점이다.
그래서 값이 도착하지 않아도 시스템은 조용하고, 조용한 상태는 안전한 상태로 읽힌다. SafeNest는 서로 다른 성질의 증거를 함께 모으고, 그 증거를 지금 신뢰해도 되는지까지 판정하는 구조로 이 공백에 대응한다.

○ 충족 · △ 조건부 충족 · × 미충족. 비교는 감지 방식의 범주를 기준으로 하며 특정 제품의 성능을 단정하지 않는다. 유사 제품과의 비교는 15페이지에 별도로 제시한다.

SafeNest · 가만있어도SANDI

2

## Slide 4

Ⅰ. 개발 개요

1.3 개발 목표 및 시스템 구성

시스템 구성도

mmWave
MR60BHA2

UART2

resp_rate_bpm
heart_rate_bpm

▼

Thermal-44
(80×62)

I²C + SPI

thermal_max_c

▼

PIR

GPIO

pir_motion

▼

SCD40
(CO₂)

I²C

co2_ppm

▼

개발 목표 (중간계획서 기준 초기 목표)

① mmWave와 열화상 융합으로 정지 상태의 인체를 비영상 방식으로 감지한다.

② 다중 센서 증거 융합과 온디바이스 AI로 정상·주의·위험 3단계를 자동 판단한다.

ESP32 Dev Module 4센서 수집 · 유효성 판정 · 패킷화

▼ SafeNest TCP protocol v1 (16 B 헤더 · Wi-Fi · valid{} 동봉)

③ 위험 감지 시 현장 경보·상태 표시·이벤트 기록을 자동 수행한다.

④ Raspberry Pi 단일 노드 MVP를 완성하고 다중 노드로 확장 가능한 구조를 갖춘다.

Raspberry Pi 5
유효성·신선도 재검사 → INT8 TFLite 추론 → Risk Engine 가중 융합

▼

소스코드 (GitHub)

시연동영상 (YouTube)

SafeNest는 mmWave·열화상·PIR·CO₂ 센서의 서로 다른 정보를 결합하고, 각 값의 유효성과 신선도를 확인한 뒤 위험도를 판단하여 현장 경보와 화면으로 전달하는 임베디드 안전 시스템이다.

정상

R < 30

▼

주의

30 ≤ R < 65

▼

위험

R ≥ 65

▼

판단 보류

증거 부족

▼

부저

GPIO18 · 880 Hz

LCD

상태 6종 표시

Web 관제

Express 5 · QR 공간코드

표기 원칙 : 구현 완료 / SW 검증 / 실기기 검증 / 실기기 E2E / 미검증 을 구분해 표기한다. 초기 개발 목표와 달성 결과는 분리하며, 달성 여부는 16페이지 완성도 표에 증거 등급과 함께 제시한다.

SafeNest · 가만있어도SANDI

3

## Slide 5

Ⅱ. 개발 환경 설명

2.1 시스템 계층 구조 및 개발 환경

감지

4계층 역할 분담

MR60BHA2 · Thermal-44 · SCD40 · PIR

수집·검증

ESP32 Dev Module. 버스 판독, valid·freshness 판정, CRC, 패킷화

판단

대응

Raspberry Pi 5. 센서 상태 관리, INT8 TFLite 추론, Risk Engine

부저·LCD·Web 관제. 등급별 경보와 상태 표시

개발 환경

구분 | 사용 기술 | 대상 기기 | 저장소 근거 경로
MCU 펌웨어 | Arduino / PlatformIO (C++) | ESP32 Dev Module | devices/esp32_node/firmware/
수신·표시 서버 | Python 3 표준 라이브러리 (http.server, socket, struct) | Raspberry Pi 5 | integration/pi_lcd/server.py
온디바이스 AI | TensorFlow Lite INT8 추론 / 학습·검증 TensorFlow 2.19.1 | Raspberry Pi 5 | ondevice_ai/inference/, models/
위험도 엔진 | Python, 규칙+플로어 융합 | Raspberry Pi 5 | RaspberryPi/Runtime/risk/formula_v1.py
웹 관제 | Node.js Express 5 (bcryptjs · jsonwebtoken · qrcode) | Raspberry Pi 5 | integration/web/
센서 계약 | Python 추상 인터페이스 | 전 영역 공통 | shared/contracts/base_sensor.py
외함 | 3D CAD → STL 4종 | FDM 출력 | hardware/3d_models/

저장소 전체 파일 수 1,904개 (패키징 시점 개발 스냅샷, commit 3f22fb1). 위 표는 개발 환경에 해당하는 구성만 발췌한 것이다.

SafeNest · 가만있어도SANDI

4

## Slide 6

Ⅱ. 개발 환경 설명

2.2 센서 구성 및 하드웨어 인터페이스

센서 | 인터페이스 | ESP32 핀 / 주소 | 수집 값
MR60BHA2 (mmWave) | UART2 115200 bps | RX GPIO16 / TX GPIO17 | 호흡수, 심박수, 재실, phase
SCD40 (CO₂) | I²C 100 kHz | SDA 21 / SCL 22 / 0x62 | co2_ppm
PIR | GPIO 디지털 입력 | GPIO 13 (20 ms 폴링) | pir_motion
Thermal-44 (MI48xx) | I²C 제어 + SPI 1 MHz | 0x40 · 0x41 / SCLK18 MISO19 MOSI23 CS27 READY26 RESET25 | 80×62 uint16 프레임

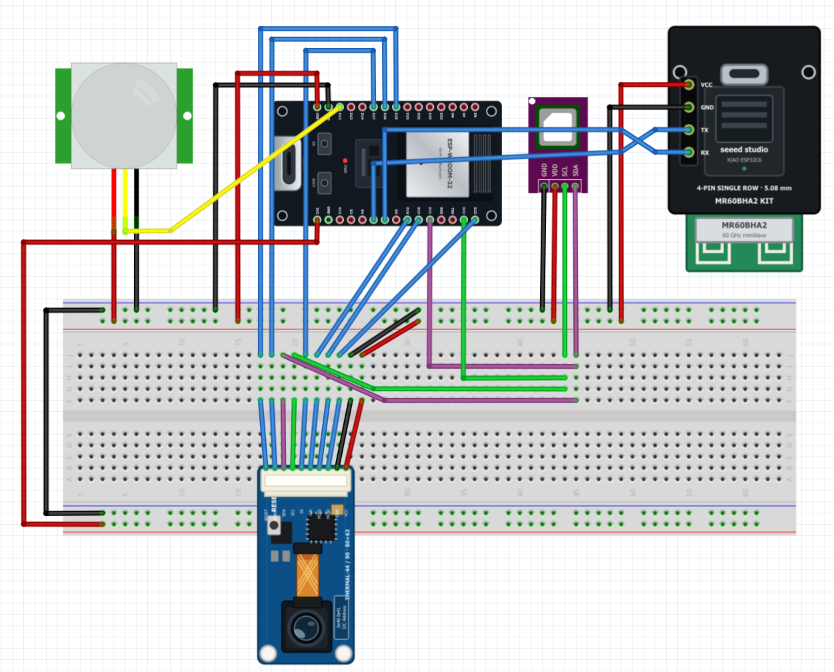
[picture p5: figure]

[그림 1] ESP32 4센서 결선도. 좌측 표의 핀 배정과 1:1로 대응한다.

설계상 중요한 점

· 열화상 RESET(GPIO25)을 단독 핀으로 확보해 부팅 시퀀스와 무프레임 자동 재초기화를 구현하였다.

· 브레드보드·점퍼 배선 환경을 고려해 SPI 1 MHz, I²C 100 kHz로 운용한다.

· 실행 루프에서 delay()를 사용하지 않고 millis() 주기 판정과 FreeRTOS 네트워크 태스크로 분리하였다.

· 10개 신호선이 서로 다른 버스에 물리므로 핀 상수를 펌웨어 상단에 모아 배선도와 1:1로 대응시켰다.

근거 : devices/esp32_node/firmware/esp32_sensor_node.ino (741줄) 의 핀 상수 정의 PIN_*, SCD4X_ADDRESS, THERMAL_ADDRESS_A·B.

SafeNest · 가만있어도SANDI

5

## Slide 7

Ⅲ. 개발 프로그램 설명

3.1 소프트웨어 모듈 구성

경로 | 역할 | 입력 → 출력
devices/esp32_node/firmware/ esp32_sensor_node.ino | 4센서 수집, 유효성 판정, 패킷화 (741줄) | 센서 버스 → SafeNest TCP v1 패킷
devices/{mmwave,co2,pir,thermal}/src/ | 센서별 어댑터, mock, 설정 | 원시 판독 → 공용 센서 계약
shared/contracts/base_sensor.py | 모든 영역이 의존하는 센서 계약 | 인터페이스 정의
integration/pi_lcd/server.py | TCP 9000 수신, HTTP 8080 API, 상태 6종, 부저 | 패킷 → 상태·화면·경보
ondevice_ai/inference/ | TFLite Interpreter, 모델 레지스트리, 검증기 | 프레임·윈도우 → InferenceResult
RaspberryPi/Runtime/risk/ formula_v1.py | 가중 융합 + 채널별 안전기준 플로어 | 센서·AI → risk_score / WARNING·DANGER
ondevice_ai/integrated_node/run_node.py | 통합 실행 노드, 외부 provider 주입 | 센서 provider → 위험도 출력
integration/web/ | Express 5 관제 웹, QR 생성, 시뮬레이터 | 상태 → 관리자·방문자 화면
hardware/3d_models/ | 외함 CAD STL 4종 + 설계사양 2종 | 설계 → FDM 출력

외부 오픈소스 및 데이터셋 고지 (대회 규정 제10조 ③)

데이터셋 : Zenodo mmWave vital-sign (DOI 10.5281/zenodo.18599983, CC BY 4.0) · UCI Occupancy Detection (ID 357, CC BY 4.0) · SDT Thermal (TU Wien / Zenodo 4124309, 라이선스 조건 확인 중)
라이브러리 : TensorFlow Lite, Sensirion SCD4x, Seeed mmWave, Express 5, gpiozero, NumPy. 위 자산은 학습·추론·통신에 활용하였으며, 센서 통합 펌웨어와 통신 프로토콜, 상태 관리, 위험도 엔진은 팀 자체 구현이다.

본 보고서의 저장소 경로는 패키징 시점 스냅샷(commit 3f22fb1) 기준이다. 이후 저장소를 기기 단위로 재편하여 현재 main 에서는 ESP32/ 와 RaspberryPi/ 아래에 있으며, 스냅샷 구조는 archive/legacy_main_repo/ 에 그대로 보존되어 있다.

SafeNest · 가만있어도SANDI

6

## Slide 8

Ⅲ. 개발 프로그램 설명

3.2 통신 프로토콜 설계

SafeNest TCP protocol v1. 모든 정수는 network byte order

16 B 고정 헤더 구조

magic

4 B

"SNST"

version

1 B

1

type

1 B

1=JSON, 2=열화상

flags

2 B

0

sequence

4 B

uint32

payload_length

4 B

uint32

전송 흐름과 페이로드

센서 판독

▶

유효성 판정

▶

SNST 16 B 헤더 + payload

▶

TCP 9000 송신

▶

Pi 수신·재검사

Type 1 스칼라 JSON, 1초 주기

Type 2 열화상 프레임, 현재 비활성

Type 1 페이로드 (schema safenest.telemetry.v1)

device_id · seq · uptime_ms
resp_rate_bpm · heart_rate_bpm · co2_ppm
thermal_max_c · pir_motion
valid { respiration, heart, co2, thermal }

Type 2 규격 (12페이지의 구조 변경으로 전송 비활성)

16 B 메타 (width 80, height 62, frame_sequence,
uptime_ms, minimum_raw, maximum_raw)
+ 4,960 × uint16 = 9,920 B
→ payload 9,936 B / 패킷 9,952 B

0 ppm과 측정 실패를 같은 숫자로 보내면 수신 측은 둘을 구분할 수 없다. 값과 valid 플래그를 함께 보내야 판단 계층이 결측을 정상값으로 오해하지 않는다.

무효값 처리

void formatNullableFloat(char *output, size_t outputSize, bool valid, float value) {
if (valid && isfinite(value)) snprintf(output, outputSize, "%.2f", value);
else strlcpy(output, "null", outputSize); // 0으로 대체하지 않는다
}

근거 : esp32_sensor_node.ino 프로토콜 정의 L113–124, formatNullableFloat L546–553 · integration/pi_lcd/server.py 의 PACKET_HEADER, recv_exact.

SafeNest · 가만있어도SANDI

7

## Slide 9

Ⅲ. 개발 프로그램 설명

3.3 센서 유효성 및 신선도 검사

수신부터 상태 확정까지

패킷 수신

recv_exact()로 헤더 16 B를 읽고
payload_length 만큼 정확히 수신

형식 검사

magic·version·flags 확인
payload > 20,000 B 이면 연결 종료

스키마 검사

safenest.telemetry.v1 확인
valid{} 객체 존재 확인

신선도 검사

ESP32 : mmWave 5 s / CO₂ 15 s / 열화상 30 s
Pi : 5 s 독립 판정

상태 확정

LIVE · STALE · INVALID
DISCONNECTED · WAITING

▶

▶

▶

▶

열화상 프레임 무결성 검사

검사 | 방법 | 불합격 시 처리 | 구현 위치
CRC-16/CCITT-FALSE | poly 0x1021, init 0xFFFF 로 계산해 헤더 기록값과 대조 | 프레임 폐기 | thermalFrameCrc()
헤더 범위 재계산 | min/max 를 픽셀에서 다시 계산해 헤더 값과 대조 | 프레임 폐기 | server.py
시퀀스 교차 확인 | 외부 헤더 sequence 와 내부 frame_sequence 일치 확인 | 프레임 폐기 | server.py
죽은 화소 배제 | raw 2332–4231 (약 −40~150 ℃) 범위 밖 화소 제외 | 사용 가능 화소 32개 미만이면 폐기 | .ino / server.py
무프레임 자동 복구 | 30 s 무프레임 시 GPIO RESET LOW 20 ms → HIGH 300 ms | 센서 재초기화 | recoverThermalIfStale()

설계 원칙 : 센서가 정해진 시간 안에 갱신되지 않으면 해당 입력을 STALE로 분리하고, 마지막 정상값을 현재 증거로 다시 쓰지 않는다. 유효하지 않은 증거는 판단에서 제외하며 0으로 대체하지 않는다.

검증 : 본 문서 작성 시점에 integration/pi_lcd 테스트 13건을 실행해 전부 통과하였다. 부분 수신, 잘못된 헤더, 시퀀스 불일치, 신선도 판정이 포함된다.

SafeNest · 가만있어도SANDI

8

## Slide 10

Ⅲ. 개발 프로그램 설명

3.4 온디바이스 AI 모델 구성과 검증 범위

기능 | 모델 | 입력 → 출력 | 양자화 | 검증 범위 | 상태
열화상 기반 인체 자세 분석 | thermal_fall_int8 v0.1.0 | 62×80×1 프레임 → 3-class NOT_HUMAN / HUMAN_NORMAL / HUMAN_FALL | full INT8 318 KB | 실제 Thermal 프레임 → Raspberry Pi 5 → 실제 INT8 TFLite E2E 관통 | 허용
CO₂ 기반 재실 분석 | co2_occupancy_int8 v0.1.0 | CO₂ slope · 습도 · ppm → 2-class VACANT / OCCUPIED | full INT8 4.4 KB | 공개 데이터셋 기반 오프라인 검증 (실센서 평가 미수행) | 허용 (제한)
mmWave 기반 호흡 패턴 분석 | mmwave_resp_int8 v0.1.0 | 300샘플 30 s 창 → 3-class NORMAL / RAPID / APNEA | full INT8 466 KB | 재현 검증에서 클래스 붕괴 확인 acc 0.3996 · macro-F1 0.19 · recall 0.0 | 차단
mmWave 기반 호흡 패턴 분석 | mmwave_resp_int8 v0.2.0 후보 | 동일 | full INT8 22 KB | 합성 데이터 468샘플 한정 smoke 실센서 성능 검증 불가 | 후보

열화상 채널
실기기 실측

Raspberry Pi 5
30.06 s · 138회

p50

162.70 ms

p95

173.90 ms

평균

167.92 ms

유효 프레임

135/138

처리량

4.6 FPS

※ 네트워크 수신 + 추론 포함, 열화상 채널 한정

실기기 E2E

오프라인

배포 차단

합성 한정

① HUMAN_FALL 은 눕기(LYING) 정적 자세의 프록시이며 시간축 낙상 사건을 검증한 결과가 아니다.
② 열화상이 산출하는 값은 표면 온도이며 의료용 체온이 아니다. ③ mmWave 호흡 관련 신호는 임상 진단 목적이 아니다. ④ v0.2.0 후보의 합성 데이터 정확도 1.0은 실센서 성능이 아니다.

근거 : ondevice_ai/models/model_manifest.json · 03_Evidence/Thermal/phase4_6_inference_report.md · phase11_12_fail_closed_benchmark.md

표현 범위

SafeNest · 가만있어도SANDI

9

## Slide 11

Ⅲ. 개발 프로그램 설명

3.5 위험도 산출과 안전기준

R = 100 × ( 0.25 · mmWave + 0.30 · CO₂ + 0.15 · PIR + 0.30 · Thermal ) 정상 R < 30 · 주의 30 ≤ R < 65 · 위험 R ≥ 65

채널별 안전기준. 플로어가 가중합보다 등급을 올릴 수 있다

채널 | 주의 플로어 | 즉시 위험 | 점수에 넣는 방식
CO₂ | ≥ 1,500 ppm 또는 기준값+700 ppm 상승 ≥ 15 ppm/min | ≥ 5,000 ppm 비상 2,500 ppm 은 주의 유지 | ppm 곡선. occupancy 모델은 제외
열화상 | HUMAN_FALL_PROXY 점수 0.4 비상 없음 | HUMAN_FALL 신뢰도 ≥ 0.8 현재 모델은 프록시만 출력 | 눕기 자세 프록시. 낙상 사건 검증 전
mmWave | 미검증 APNEA 2회 연속 호흡 10–24 rpm 이탈 지속 | 하드웨어 확인 apnea 만 | 신경망은 관측 전용. 스펙트럼 호흡수 우선
PIR | 재실 확인 후 180 s 무움직임 | 해당 없음 | 재실 미확인이면 비가용 (0점으로 채우지 않음)

SW 검증

계산 예시 : CO₂ 1,500 ppm, 사람 상태는 평온

입력 호흡 16 rpm · CO₂ 1,500 ppm (성분 0.325) · 움직임 있음 · 열화상 HUMAN_NORMAL
가중합 R = 100 × (0.25×0 + 0.30×0.325 + 0.15×0 + 0.30×0) = 9.75 → 점수 등급 정상
플로어 co2_warning → 주의 · 비상 아님 · mmWave 신경망 관측 전용이라 health = DEGRADED

fail-closed (formula_v1.py)

전 채널 무효 → score·level = None
유효 가중치 < 0.5 이고 정상이면
INDETERMINATE (정상으로 채우지 않음)
점수가 낮아도 플로어가 주의를 올린다

임계값의 근거 1,500 ppm 은 별표2 비고(자연환기 불가+기계환기)이며 기본 유지기준은 1,000 ppm 이다. 5,000 ppm 은 OSHA/NIOSH 8h TWA와 같은 값이며 순간 비상으로 쓴다. 제618조 적정공기는 15,000 ppm. 인증 준수 주장은 하지 않는다. 출처는 docs/09_SAFETY_CRITERIA_V1.md.

계산 예시는 RaspberryPi/Runtime/risk/formula_v1.py 실행 값. 검증 : tests/test_risk_formula_v1.py. occupancy 로컬라이징은 본 식에서 제외한다.

SafeNest · 가만있어도SANDI

10

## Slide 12

Ⅲ. 개발 프로그램 설명

3.6 실측 검증 결과

서로 다른 조건에서 채널별로 수행하였으며, 통합 시스템 성능으로 합산하지 않는다

① CO₂ 센서 연속 수신 검증

ESP32 192.168.1.16 → Pi 5 192.168.1.44:9000, TCP 실경로, 2026-08-12

② mmWave 수신 안정성 및 리플레이 결과

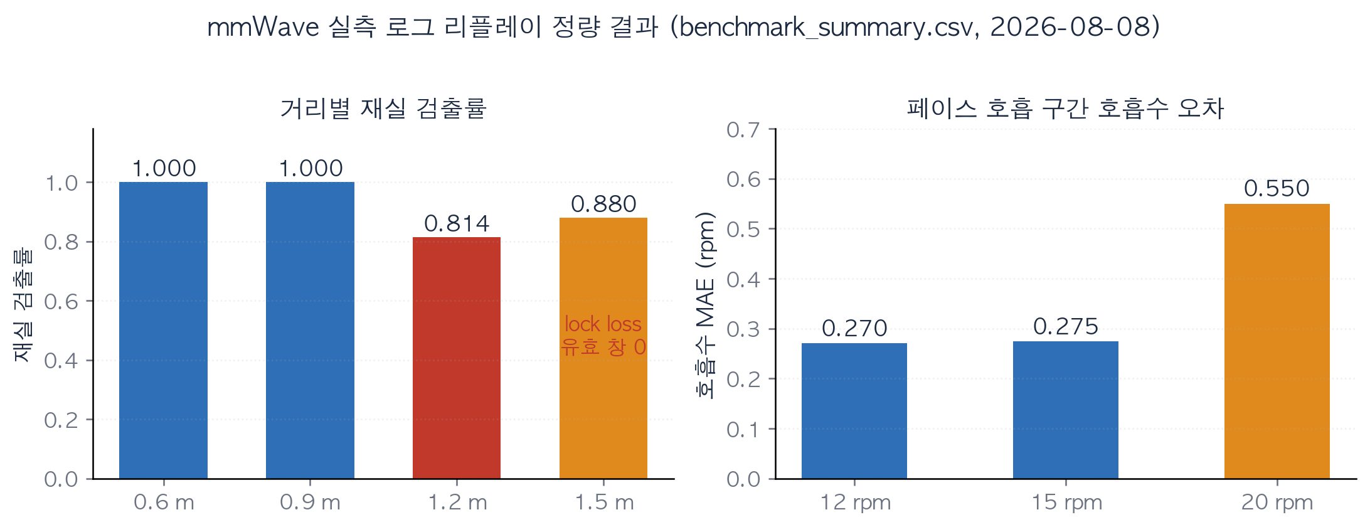
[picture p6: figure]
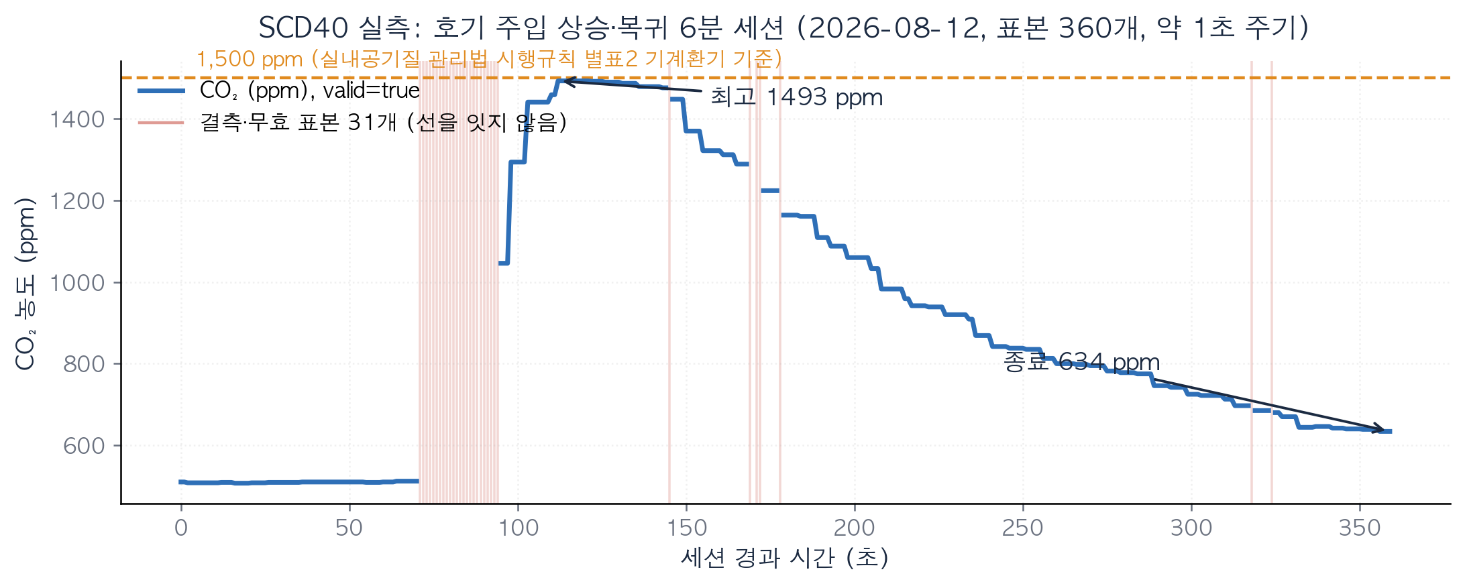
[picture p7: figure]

세션 | 유효 표본 | 결측률 | 판정
프리플라이트 30초 | 30 / 30 | 0 % | PASS
baseline 5분 (최초) | 277 / 300 | 7.67 % | FAIL
baseline 5분 (재측정) | 300 / 300 | 0 % | PASS
호기 6분 | 329 / 360 | 8.61 % | PASS

라이브 UART 수신 (2026-08-08)

9.990 Hz · 1,201 레코드 · 199/199 창 파싱 · 시퀀스 누락 0 · UART / checksum / parser 오류 0 / 0 / 0

③ Thermal 실기기 End-to-End

Raspberry Pi 5, 30.06 s / 138회 측정

p50 162.70 ms · p95 173.90 ms · 평균 167.92 ms
유효 프레임 135 / 138 (97.8 %) · 처리량 4.6 FPS
fail-closed 6종(순서위반 · NaN/Inf · 형식오류 · 물리적 단선 · 복구 · close 후 read) 실기기 PASS

최초 baseline 의 결측은 채우거나 삭제하지 않고 원본을 실패 증거로 보존한 뒤 재측정하였다. 호기 세션 최고 1,493 ppm, 종료 634 ppm.

ESP32 펌웨어 빌드 자원 : RAM 32,356 / 327,680 B (9.9 %), Flash 268,765 / 1,310,720 B (20.5 %). 4센서 동시 수신 로그는 아직 확보하지 않았다 [추가 검증 필요].

SafeNest · 가만있어도SANDI

11

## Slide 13

Ⅳ. 장애요인과 해결방안

4.1 열화상 전송 구조 개선

문제

열화상 프레임을 계속 전송하면 1초 주기 telemetry(호흡·심박·CO₂·PIR)가 밀린다. 화면 값이 갱신되지 않거나 stale 로 떨어졌다.

원인

패킷 하나가 9,952 B (메타 16 B + 4,960 × 2 B + 헤더 16 B). 당시 분주비 4로 25 FPS 센서에서 초당 약 6.25 프레임을 요청하여 약 60 KB/s 를 ESP32 Wi-Fi 단일 TCP 연결에 투입하였다. 열화상 write 가 블로킹되면 뒤의 telemetry write 도 함께 지연된다.

시도

① TCP write 를 별도 FreeRTOS 태스크로 분리 ② 열화상 큐를 길이 1로 두고 xQueueOverwrite 로 최신 프레임만 유지 ③ 512 B 청크 분할 전송 ④ 분주비 4 → 8 (약 3.125 FPS) ⑤ SPI 8 MHz → 1 MHz

실패

수집이 네트워크 때문에 멈추는 현상은 사라졌지만, 스트리밍을 켠 상태에서 1초 주기는 여전히 유지되지 않았다. 큐를 줄인 것은 지연을 감춘 것이지 전송량을 줄인 것이 아니었다. 링크에 실리는 총 바이트는 그대로였다.

해결

THERMAL_STREAM_FRAMES = false 로 전환하였다. 프레임을 보내는 대신 ESP32 가 그 자리에서 요약한다. 측정 범위 밖 죽은 화소를 제외하고, 살아 있는 화소가 32개 이상일 때 가장 뜨거운 16개 중 최저값을 골라 thermal_max_c 하나로 환산해 1초 telemetry 에 싣는다.

type 2 패킷 9,952 B 를 초당 약 6.25회 전송 시도
→ 1초 telemetry 주기 붕괴, 화면 값 지연

개선 전

type 2 전송 없음. telemetry JSON 1개(상한 512 B)로 1초 주기 유지
대신 LCD 열화상 영상은 제외하였고, 프레임 자체는 별도 리그에서만 검증한다.

개선 후

배운 점 : 대역폭이 한정된 링크에서는 판정에 필요한 최소 정보를 송신 측에서 뽑아 보내야 한다. 9,936 B 프레임에서 실제 판정에 쓰인 정보는 최고온도 하나였다.

근거 : esp32_sensor_node.ino 의 THERMAL_STREAM_FRAMES, THERMAL_FRAME_RATE_DIVIDER, xQueueOverwrite 사용부.

SafeNest · 가만있어도SANDI

12

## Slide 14

Ⅳ. 장애요인과 해결방안

4.2 자원·버스·재현성 장애요인

① GPIO 자원 제약으로 자동 복구 기능이 막힌 문제

문제·원인

XIAO ESP32-C6 의 외부 디지털 핀 11개 중 D6/D7 은 보드 내부에서 MR60BHA2 와 UART 로 묶여 외부 사용이 불가능하고, D3 은 레이더 부트·리셋 회로에, D1 은 온보드 RGB LED 에 물려 있었다.

시도·실패

nRESET 을 연결하지 않는 방안을 시도하였으나, 초기화가 I²C 주소를 찾기 전에 RESET 을 LOW 20 ms → HIGH 300 ms 로 토글해야 해서 부팅 시퀀스가 성립하지 않았다. 사람이 버튼을 눌러야 복구되는 장치는 무인 감시에 쓸 수 없다.

해결

ESP32 DevKit V1(30-pin)으로 교체하고 10개 신호선을 모두 단독 핀에 배정하였다. RESET(GPIO25) 제어를 확보하여 30초 무프레임 자동 재초기화가 동작한다.

② 브레드보드 배선이 버스 속도를 견디지 못한 문제

문제·원인

SPI 8 MHz, I²C 400 kHz 에서 MI48 과 SCD4x 양쪽에서 판독 누락이 재현되었다. 배선을 다시 꽂고 길이를 줄여도 동일하였다.

시도·실패

속도를 낮추면 프레임 판독 시간이 늘어 요청 주기를 넘길 위험이 있었으므로, 시간 예산 안에 들어오는지를 함께 계산해야 했다.

해결

SPI 1 MHz, I²C 100 kHz 로 조정하였다. 1 MHz 에서 한 프레임 판독이 약 81 ms 로, 분주비 8이 요구하는 160 ms 예산 안에 들어가 READOUT_TOO_SLOW 정지가 사라졌다.

③ 학습이 끝난 모델이 재현 검증을 통과하지 못한 문제

문제·원인

mmWave 호흡 이상 분류 모델 v0.1.0 을 저장소 데이터로 재현 평가한 결과, 468개 표본 전부를 NORMAL 로 예측하는 클래스 붕괴가 확인되었다. 정확도 0.3996, macro-F1 0.19, RAPID·APNEA 재현율 0.0 이다.

시도·실패

아티팩트는 존재하였고 SHA-256 과 텐서 계약도 일치하였다. 모델 파일이 있다는 것이 검증을 통과했다는 뜻은 아니라는 사실이 드러났다.

해결

매니페스트에 deployment_allowed = false 와 차단 사유 CLASS_COLLAPSE_ON_REPOSITORY_NPZ 를 기록해 배포를 차단하고 후보를 다시 세웠다. 안전 판단 경로에 검증되지 않은 모델을 올리지 않는 것을 우선하였다.

세 번째 사례가 특히 중요하다. 성능이 나오지 않은 모델을 팀이 스스로 찾아내 배포를 차단한 것은, 검증되지 않은 구성요소를 안전 경로에 올리지 않는다는 원칙을 실제로 적용한 결과다.

근거 : esp32_sensor_node.ino (핀 상수 · THERMAL_SPI_HZ · Wire.setClock · recoverThermalIfStale) · ondevice_ai/models/model_manifest.json (validation_status: BLOCKED).

SafeNest · 가만있어도SANDI

13

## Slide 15

Ⅴ. 개발 결과물의 차별성

5.1 기술적 차별성

1

증거가 무효이거나 결측이면 마지막 정상값을 재사용하지 않는다. 네 채널이 모두 무효이면 위험도를 산출하지 않고 risk_score 와 risk_level 을 None 으로 두며 system_health 를 FAILED 로 기록한다. 침묵을 안전의 증거로 삼지 않는다.

fail-closed 판단 보류

RaspberryPi/Runtime/risk/formula_v1.py

SW 검증

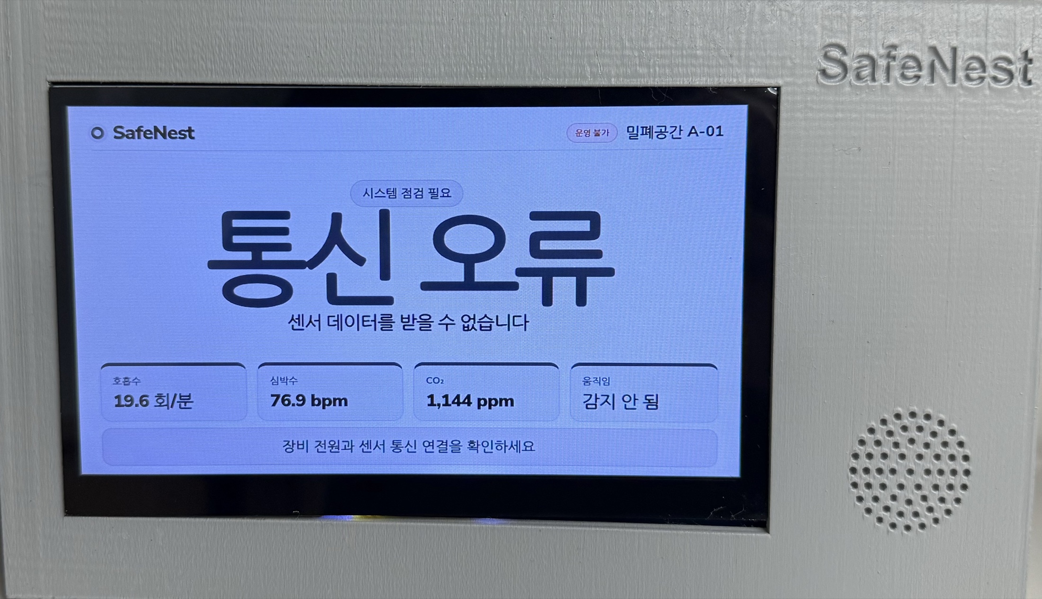
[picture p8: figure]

[그림 2] 전 센서 무효 시 표시 화면. 정상으로 표시하지 않고 점검 필요 상태를 출력한다. 표시 계층 검증용 시나리오 화면이며 실센서 측정값이 아니다.

2

값과 함께 valid 플래그를 전송하며, 유효하지 않은 수치는 0으로 대체하지 않고 null 로 보낸다. ESP32 와 Raspberry Pi 가 신선도를 각각 독립적으로 판정하고, STALE 입력은 판단에서 제외한다.

유효성·신선도의 1급 상태 관리

formatNullableFloat() · SensorStore

SW 검증

3

영상 센서를 쓰지 않는다. mmWave 의 미세 움직임, 열화상의 저해상도 열 분포, CO₂ 의 환경 추세, PIR 의 움직임 이벤트가 서로 다른 실패 모드를 상쇄한다. 열화상은 80×62 해상도로 개인 식별용 영상이 아니다.

카메라 없는 이종 센서 증거 융합

RaspberryPi/Runtime/risk/formula_v1.py

SW 검증

4

모델마다 검증 범위와 배포 허용 여부를 매니페스트에 기록한다. 재현 검증에 실패한 모델은 실제로 배포가 차단되었다.

검증 등급에 따른 배포 통제

오프라인 검증

5

CRC-16/CCITT-FALSE 검사, 헤더 범위 재계산, 시퀀스 교차 확인을 거치며 30초 무프레임 시 GPIO RESET 으로 센서를 재초기화한다.

각 항목은 03_CLAIM_EVIDENCE_LEDGER 의 근거 파일과 1:1로 연결되어 있으며, 근거가 확인되지 않은 주장은 포함하지 않았다.

SafeNest · 가만있어도SANDI

프레임 무결성과 자동 복구

실기기 검증

14

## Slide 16

Ⅴ. 개발 결과물의 차별성

5.2 기존 방식 및 유사 사례 비교

비교 축 | 가스감지기 | CCTV | PIR | 웨어러블 | Vayyar Care | TI IWR6843 | SafeNest
사생활 보호 (비영상) | ○ | × | ○ | ○ | ○ | ○ | ○
정지 인체에 대한 증거 | × | △ | × | ○ | ○ | ○ | ○
환경 위험 감시 | ○ | × | × | × | × | × | ○
다중 증거 교차 확인 | × | × | × | × | × | × | ○
무효·결측 데이터 인지 | × | × | × | △ | 확인 불가 | 확인 불가 | ○
증거 부재 시 판단 보류 | × | × | × | × | 확인 불가 | 확인 불가 | ○
통합 실기기 검증 완료 | ○ | ○ | ○ | ○ | ○ | ○ | ×

Vayyar Care
(상용 제품)

SafeNest 가 다르게 한 지점은 감지 성능보다 증거를 다루는 정책에 있다. 조사한 세 사례 모두 공개 자료에서 무효·결측 인지와 판단 보류 정책을 확인할 수 없었다. 다만 SafeNest 는 4센서 통합 실기기 검증을 완료하지 않았으므로 마지막 행을 그대로 표기한다.

60 GHz 4D 이미징 레이더 기반 낙상 감지 장치. 카메라·마이크·웨어러블을 쓰지 않고 1대가 약 16 m²를 감시하며 낙상을 3단계로 구분한다. 환경 가스 감시 기능은 제품 설명에서 확인되지 않는다.

TI IWR6843
(상용 부품)

60~64 GHz FMCW 단일칩 mmWave 센서. 재실 감지와 생체신호 검출 레퍼런스 디자인이 공개되어 있다. 센서 단위 부품이므로 환경 센서 융합과 판단 보류 정책은 범위 밖이다.

학술 연구
(arXiv 2403.05634, 2024)

SafeNest · 가만있어도SANDI

TI mmWave 레이더 3대로 다중 인체 추적과 낙상 감지를 수행하여 정확도 96.3 %를 보고하였다. 단일 모달리티 실험이며 센서 무효·결측 시의 처리 정책은 다루지 않는다.

○ 충족 · △ 조건부 충족 · × 미충족 · 확인 불가는 공개 자료에서 판정 근거를 찾지 못한 항목이다. 출처 : vayyar.com/care-pages/how, ti.com/tool/IWR6843ISK, arXiv:2403.05634.

15

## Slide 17

Ⅴ. 개발 결과물의 차별성

5.3 구현 결과 및 검증 수준

구성요소 | 구현 | 검증 수준 | 증거 | 남은 과제
ESP32 4센서 통합 노드 | 완료 | SW 검증 | esp32_sensor_node.ino 741줄 · 빌드 RAM 9.9 % / Flash 20.5 % | 4센서 동시 수신 실측
TCP v1 송·수신 및 유효성 검사 | 완료 | SW 검증 | 수신기 테스트 13건 통과 · CRC-16 · 범위 재계산 · 이중 TTL | 실환경 장시간 수신
Risk Engine · fail-closed | 완료 | SW 검증 | 위험도 테스트 22건 실행 통과 | 실입력 기반 HIL
mmWave 채널 | 완료 | 실기기 검증 | 9.990 Hz · 1,201 레코드 · 오류 0 · 리플레이 MAE 0.270 rpm | 통합 노드 편입
CO₂ 채널 | 완료 | 실기기 검증(부분) | 실측 4세션 · 재측정 결측 0 % · 호기 최고 1,493 ppm | 센서 분리 결측 계약
Thermal 채널 | 완료 | 실기기 E2E | Pi 5 p50 162.70 / p95 173.90 ms · 유효 97.8 % · fail-closed 6종 통과 | 정본 노드 경유 검증
Web · LCD · 부저 · 외함 | 완료 | SW 검증 + 실물 | 상태 6종 표시·경보 확인 · 하우징 2종 출력·조립 완료 | 실센서 구동 화면
4센서 통합 HIL | 미착수 | 미검증 | 해당 없음 | 최우선 과제

하드웨어 없이 실행 가능한 테스트를 직접 실행하여 57건 통과, 2건 실패(데이터 파일 부재)하였다. 저장소의 테스트 함수 1,483개는 소스에 정의된 개수이며 실행·통과 건수와 다르다.

테스트 수치의 의미

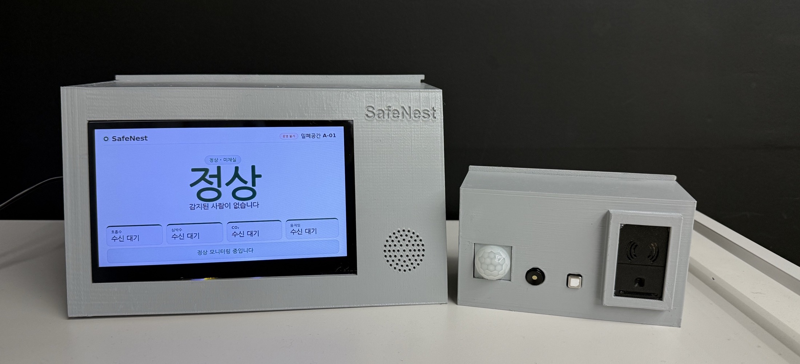
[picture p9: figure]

[그림 3] 완성품. 좌측 표시부, 우측 센서 노드. 하우징 2종은 자체 설계 STL 출력물이다.

SafeNest · 가만있어도SANDI

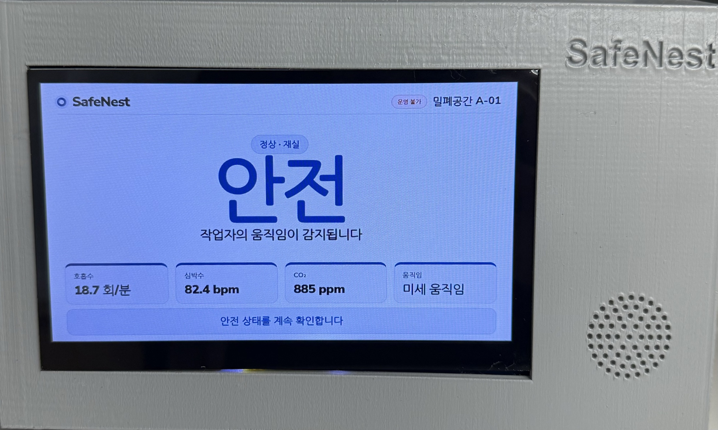
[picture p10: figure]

안전 · 재실

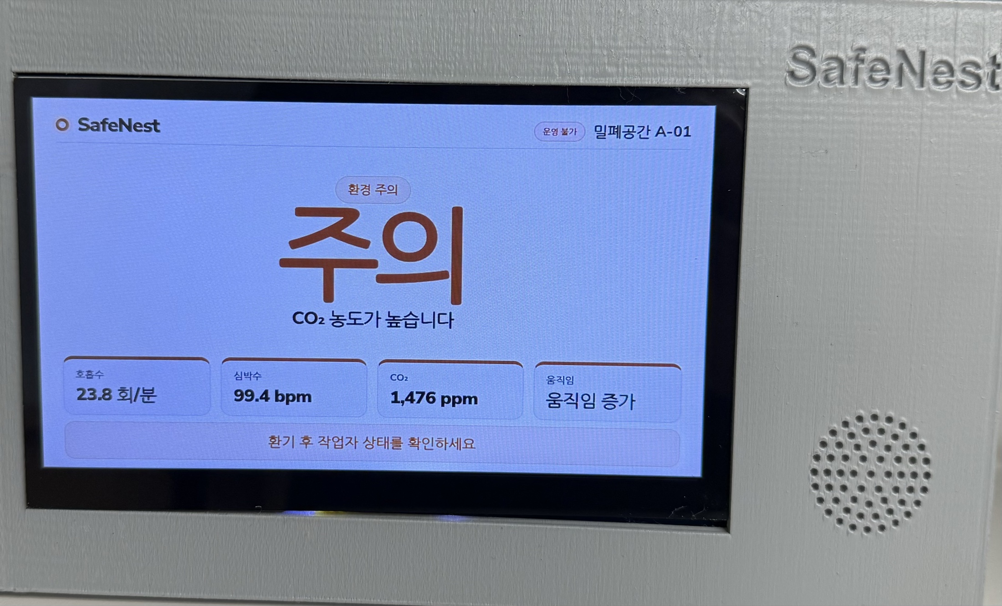
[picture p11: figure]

주의 · CO₂ 높음


위험 · 호흡 이상

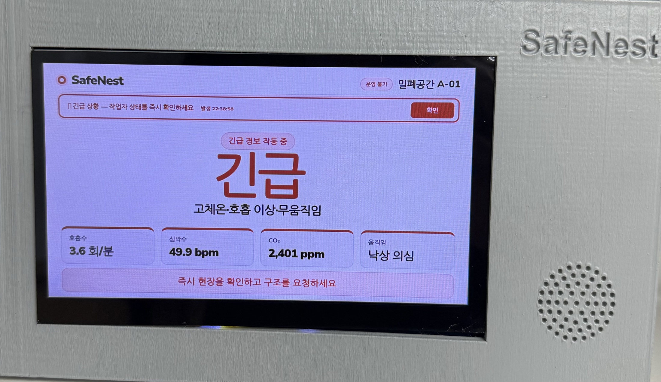
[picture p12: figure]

긴급 · 복합 위험

[그림 4] 위험도 등급별 표시·경보 화면. 주의는 화면 경고, 위험부터는 부저 경보가 함께 출력된다. 화면 값은 표시 계층 검증용 시나리오 입력이며 실센서 측정값이 아니다.

검증 수준 : SW 검증은 소프트웨어 테스트 통과, 실기기 검증은 실제 센서·보드에서 확인, 실기기 E2E 는 실센서부터 추론까지 관통, 통합 HIL 은 4센서 동시 실기기 검증(미완)을 뜻한다.

16

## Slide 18

Ⅵ. 파급력 및 기대효과

6.1 적용 분야 및 기대효과

1차 적용 : 밀폐공간 무인 감시

· 맨홀·정화조·집수정 등 산업안전보건법 시행규칙 별표18이 정한 밀폐공간

· 감시인 상시 배치가 어려운 소규모 사업장의 보조 감시 수단

· 공기질(CO₂)과 사람의 상태를 함께 확인하여 가스 감지기 단독 운용의 공백을 메운다

· 카메라를 쓰지 않으므로 작업자 사생활 문제를 설계 단계에서 줄인다


[그림 5] Express 5 관제 웹. 공간 단위 상태 조회와 다중 노드 관제로의 확장 근거다. 표시 계층 구현 결과이며 화면 값은 시나리오 입력이다.

확장 적용과 실측 감지 특성의 대응

좌석까지의 거리가 0.6~0.9 m 구간에 해당한다. 해당 구간의 재실 검출률은 리플레이 기준 1.000 이다.

통학차량 잔류 감지

창고·냉동·양생 공간

작업자 고립 감지와 환경 악화 추세를 동시에 관측한다. 1.2 m 이상에서는 검출률이 0.814로 낮아지므로 노드 배치 간격을 좁혀야 한다.

다중 노드 확장

1.5 m 에서는 lock loss 로 유효 창이 0이었다. 따라서 대형 공간은 단일 노드를 키우는 대신 노드를 분산 배치하여 대응한다.

공간 식별 체계

기대효과 서술의 범위

확장 시나리오는 동일한 노드 구조로 대응 가능하다는 설계 판단과 리플레이 실측 감지 특성에 근거한다. 현장 파일럿과 정량 효과, 시장 규모는 아직 검증하지 않았다. 매출·판매가·시장 점유 수치는 제시하지 않으며, 부품 단가도 공개 출처로 전 항목을 확인하기 전까지 기재하지 않는다.

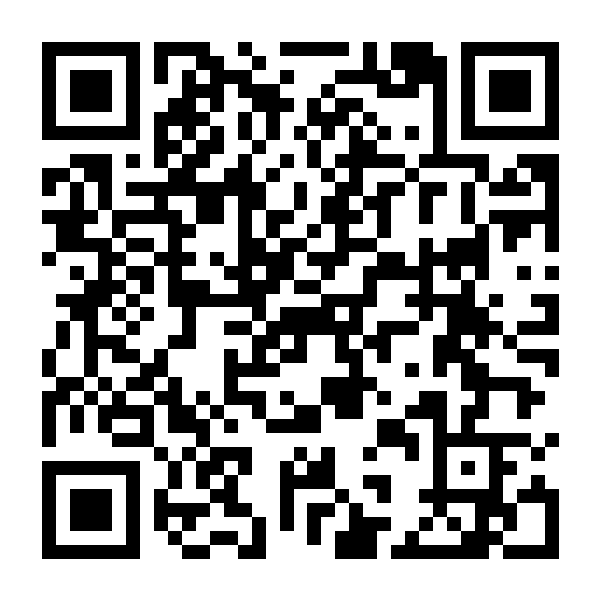
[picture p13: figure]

QR 로 공간을 식별한다. 관제 웹에 밀폐공간 A-01, 통학차량 B-02, 창고 C-03 등록.

SafeNest · 가만있어도SANDI

적용 근거 : 산업안전보건법 시행규칙 별표18 밀폐공간의 범위. 감지 거리 근거 : devices/mmwave/validation_results/replay_v5/benchmark_summary.csv.

17

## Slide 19

Ⅵ. 파급력 및 기대효과

6.2 발전 가능성 및 외함 설계

단계별 진행 상황

✓

✓

3

4

5

6

1단계

채널별 실기기 검증
+ SW 검증

2단계

하우징 출력·조립
완제품 형상 확보

3단계

4센서 통합 HIL
실입력 → Risk → 경보

4단계

현장 데이터 수집
임계값·보정 확정

5단계

다중 노드 확장
무선 관제

6단계

인증·현장 평가

설계에서 실물까지

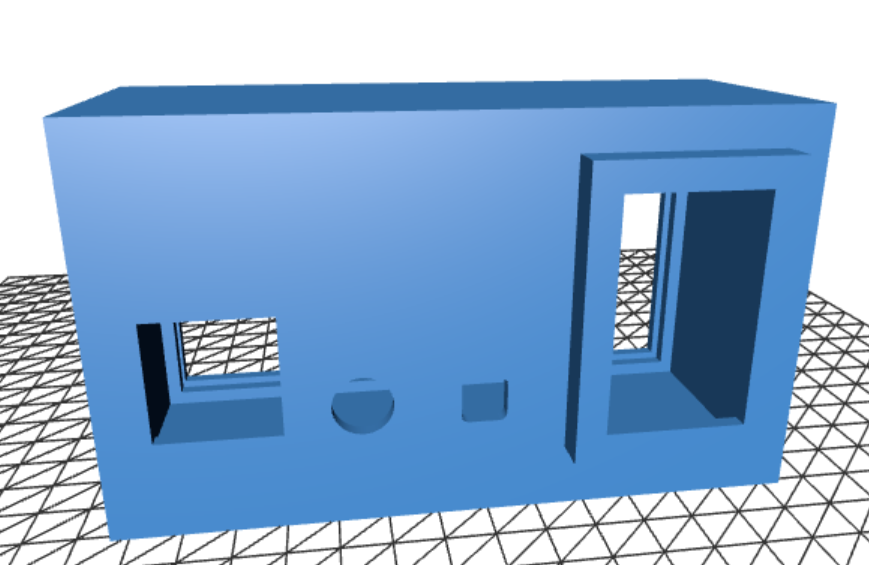
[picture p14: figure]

[그림 6] 센서 하우징 전면 개구부 설계

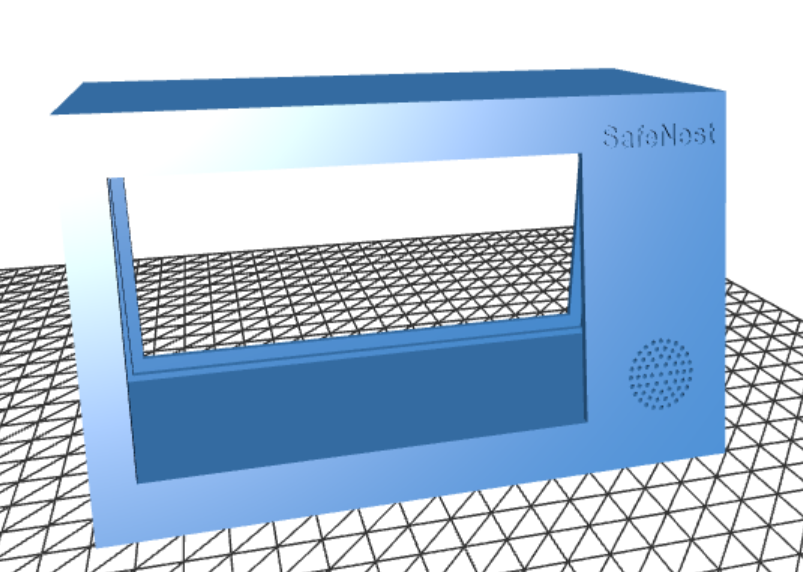
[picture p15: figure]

[그림 7] LCD·부저 하우징 전면 설계

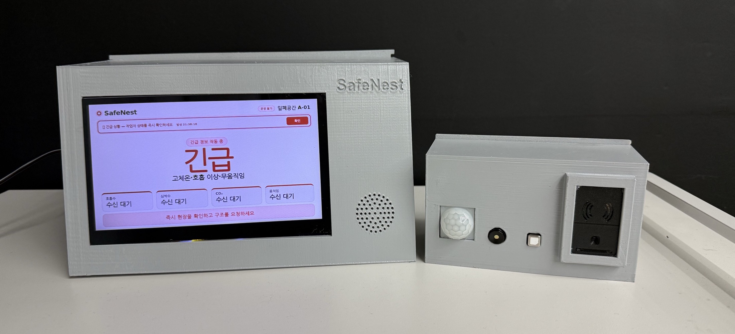
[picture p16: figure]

[그림 8] FDM 출력·조립을 마친 실물. 긴급 등급 표시 상태이며 화면 값은 시나리오 입력이다.

▶

센서 하우징 137×80×60 mm (벽 3 mm) · LCD·부저 하우징 240×140 mm · 슬라이딩 슬롯 3.5 mm · 편측 유격 0.25 mm. STL 4종과 설계사양 2종을 전달하였고 출력·조립을 완료하였다. 장시간 체결 강도와 발열 특성은 아직 확인하지 않았다.

CAD 설계와 STL 출력물 모두 팀 자체 산출물이다.

SafeNest · 가만있어도SANDI

18

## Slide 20

Ⅶ. 개발 일정 및 업무 분장

7.1 개발 일정 및 주요 설계 변경

7월

실제 수행 일정

요구사항 정의 · 시스템 설계 · 부품 확보 · 개발환경 구축 · 센서별 드라이버 착수

8/01

8/02–8/03

mmWave 장시간 실측. 빈 공간 30분 / 재실 31분 원시 로그 확보

저장소 통합 및 기기·책임 영역 재편 · CODEOWNERS 정의 · 회귀 테스트

8/08

mmWave 라이브 검증(9.990 Hz, 오류 0) · 실측 로그 리플레이 벤치마크 12종

8/11

8/12

Thermal-44 실기기 E2E 검증 · fail-closed 6종 · Pi 5 지연 실측

SCD40 실기기 4세션 측정 · ESP32 → Pi TCP 실경로 확인 · 검증 리포트 작성

8/16–8/21

8/23

mmWave 물리 측정 정합 감사 · 패키징 시점 개발 스냅샷(3f22fb1) 확정

하우징 STL 출력·조립 완료 · 표시·경보 계층 상태 6종 확인

이후

4센서 통합 HIL · 시연동영상 촬영 (미완료)

개발 과정에서 내린 주요 설계 변경

MCU 교체

XIAO ESP32-C6 → ESP32 DevKit V1

GPIO 자원 부족으로 열화상 RESET 제어가 불가능해 자동 복구 요구사항을 충족할 수 없었다.

SafeNest · 가만있어도SANDI

열화상 전송 구조

전 프레임 스트리밍 → 송신측 요약

9,952 B 패킷을 초당 약 6.25회 보내면서 1초 telemetry 주기가 무너졌다.

모델 배포 통제

mmWave v0.1.0 배포 차단

재현 검증에서 클래스 붕괴를 확인하여 검증 실패 모델을 안전 경로에 올리지 않기로 하였다.

일정은 저장소 커밋 이력과 검증 문서의 실제 일자를 기준으로 작성하였으며, 계획서의 예정 간트를 그대로 옮기지 않았다.

19

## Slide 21

Ⅶ. 개발 일정 및 업무 분장

7.2 업무 분장 및 협업 구조

성명 | 구분 | 담당 업무 | 책임 영역 (CODEOWNERS) | 주요 산출물
김진수 | 팀장 | mmWave 펌웨어·어댑터·실측, 저장소 구조 통합, 문서 총괄 | devices/mmwave/ · docs/ · 저장소 전체 기본 리뷰어 | MR60 실측 로그 30분·31분, 라이브 검증(9.990 Hz), 리플레이 벤치 12종
유승하 | 팀원 | CO₂(SCD40) 연동·실측, ESP32 4센서 노드 펌웨어, Pi LCD·부저 서버, 회로 | devices/co2/ · devices/esp32_node/ · integration/ | esp32_sensor_node.ino(741줄), CO₂ 실측 4세션·검증 리포트, TCP v1 송·수신
김태균 | 팀원 | Thermal-44 드라이버·프레임 파서·전처리, 열화상 온디바이스 AI 검증 | devices/thermal/ · docs/thermal/ | 실기기 E2E 관통, fail-closed 6종, Pi 5 지연 실측(p95 173.9 ms)
한준우 | 팀원 | 데이터셋 출처·분할, 모델 학습·비교·재현, Pi AI 준비, 위험 판단 연계 | ondevice_ai/ · shared/contracts/ | 모델 3종 매니페스트, 재현 검증·클래스 붕괴 발견 및 배포 차단
강유나 | 팀원 | PIR 어댑터, 3D 하우징 CAD 설계 및 출력, LCD·Web 초기 골격 | devices/pir/ · hardware/3d_models/ | STL 4종 + 설계사양 2종, 하우징 출력·조립, PIR 어댑터, LCD 초기 서버

담당 경계를 고정한 협업 인터페이스

센서 계약

shared/contracts/base_sensor.py

모든 센서 담당자 ↔ AI 담당자

텔레메트리 스키마

패킷 규격

safenest.telemetry.v1 (valid 블록 포함)

SafeNest TCP protocol v1 (16 B 헤더)

ESP32 담당 ↔ 수신 서버 담당

ESP32 담당 ↔ Pi 수신 담당

추론 결과 계약

위험도 출력

InferenceResult / SensorState

SafeNestRiskOutput (schema 5.0)

센서 담당 ↔ 위험도 담당

위험도 담당 ↔ 표시·경보 담당

담당 표기는 저장소 CODEOWNERS 와 실제 산출물로 확인한 범위만 기재하였으며, 기여도를 인위적으로 균등화하지 않았다.

SafeNest · 가만있어도SANDI

20

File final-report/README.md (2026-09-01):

# final-report

제24회 임베디드SW경진대회(2026) 자유공모 부문 **개발완료보고서** 제출본과
보고서에 사용한 원본 이미지 자산을 보관하는 폴더다.

| 파일 | 설명 |
|---|---|
| `2026ESWContest_자유공모_가만있어도SANDI_개발완료보고서.pdf` | 제출용 PDF (표지 1 + 본문 20 = 21페이지) |
| `2026ESWContest_자유공모_가만있어도SANDI_개발완료보고서.pptx` | 위 PDF의 원본 슬라이드 |
| `assets/` | 보고서에 사용한 하드웨어·UI·3D 하우징 사진 및 렌더 |

`assets/` 주요 항목

| 파일 | 내용 |
|---|---|
| `hw_product_full.jpg`, `hw_product_full_crop.jpg` | 통합 완제품 외형 |
| `hw_product_full_emergency.jpg`, `hw_product_emergency_crop.jpg` | 긴급 상태 표시 |
| `hw_node_final.png` | 센서 노드 배선도 |
| `hw_esp32_wiring.jpg`, `hw_bench.jpg` | ESP32 실물 배선과 벤치 |
| `ui_lcd_1_normal_empty.jpg` ~ `ui_lcd_6_failed.jpg` | LCD 6개 상태 화면 |
| `ui_web.png` | 관리자 웹 화면 |
| `3d_*.png` | 3D 하우징 설계 렌더 (STL 원본은 `hardware/3d_models/`) |
| `thermal_spotcheck.jpg` | Thermal 현장 점검 |
| `qr_confined.png` | 게스트 대시보드 QR |

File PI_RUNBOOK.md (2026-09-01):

# SafeNest Pi 실행 절차 (필드용)

이 문서는 **실제 프로토타입 Pi**에서 SafeNest 런타임을 켜고 확인하는 절차만 정리한다.
기준 경로: `/home/sandi/safenest-team-main`
기준 커밋: 팀 `main` (`jinsu1011/safenest-embedded-competition`, Risk V1 / M-N9 포함본)

> Pi IP가 바뀌면 아래 `PI_IP`만 바꿔 읽으면 된다.
> 현재 필드 IP: **`192.168.0.3`**
> USB 이더넷으로 붙는 세션은 **`192.168.137.x`** 일 수 있다. ESP 목표 주소와 모니터 `--base`를 같은 IP로 맞춘다.

---

## 필드 모니터 (바로 실행)

`--once`를 **빼면** 계속 갱신, 넣으면 한 번만 보고 종료.

```bash
cd /home/sandi/safenest-team-main/RaspberryPi/Runtime
python3 hil/pi_field_monitor.py                 # 계속 보기 (기본 4초)
python3 hil/pi_field_monitor.py --once          # 한 번만
python3 hil/pi_field_monitor.py --interval 2    # 2초 간격 계속
python3 hil/pi_field_monitor.py --raw-labels    # 짧은 라벨 대신 원문 코드
# 종료: Ctrl+C
# 맥에서: python3 hil/pi_field_monitor.py --base http://<PI_IP>:8000
```

맨 위 `Thermal:` 줄은 지금 기동된 프로세스의 Thermal selector다 (`BASELINE` / `A` / `B`). 표 읽는 법 → **3-B**. 짧은 라벨(`PHYS_OK` 등) 의미 → **3-C**.
Thermal baseline/A/B 현장 비교는 `PI_RUNBOOK_THERMAL.md` 참조.

---

## 개발 규칙 (필수)

Pi에 손대기 전에 **로컬 worktree 브랜치 → GitHub PR → merge → Pi pull** 순서로 한다.

- `main` 체크아웃을 직접 수정하지 않는다.
- 팀원과 `main`을 공유하므로 **git worktree**로 작업 트리를 분리한다.
- Pi에서 `app.py` 등을 SSH로 핫패치하지 않는다 (긴급 복구 후 반드시 브랜치에 반영·PR).
- 배포 권한 레포: `jinsu1011/safenest-embedded-competition` (`/home/sandi/safenest-team-main`).

## 0. 이것만 쓴다

| 경로 | 용도 |
|---|---|
| `/home/sandi/safenest-team-main` | **정식 배포** (여기만 실행) |
| `/home/sandi/safenest-runtime` | 예전 클론. 참고용. **기동하지 말 것** |
| `/home/sandi/integration` 등 | 옛 진단/통합 클론. **기동하지 말 것** |

한 번에 하나만 띄운다. LCD 패널은 이 백엔드가 `:8000/display` 로 직접 서빙하므로 별도 LCD 서버를 따로 켜지 않는다.
`:8000`은 **팀 런타임 백엔드만** 소유한다.

**중요:** `./run_safenest.sh`는 백엔드·센서 수신·웹 서빙까지다.
LCD에 Chromium을 **자동으로 띄우지는 않는다** → 아래 **2-B**를 따로 실행한다.

---

## 1. 최초 1회 (이미 끝났으면 생략)

```bash
cd /home/sandi/safenest-team-main
git fetch origin
git checkout main
git pull --ff-only origin main

# 의존성 + preflight
bash ./run_safenest.sh --install
```

확인:

- `.venv/bin/python` 존재
- `RaspberryPi/Runtime/risk/formula_v1.py` 존재
- `.env` 존재 (비밀값 포함 — git에 올리지 말 것)
- `RaspberryPi/LCD/static/display.html` 존재

### mmWave / B23 (필드 현재)

기본 mmWave AI는 **B23 PyTorch 프로토타입** (`M_PROT_B23`)이다. M-N9 INT8 호흡 분류(`NORMAL`/`APNEA`)는 기본 경로가 아니다.

이 Pi에는 추론이 실제로 돌도록 **런타임 어댑터**(재실 래치 + 10Hz 샘플 인덱스)가 들어가 있을 수 있다. 팀 `main` 원본만 있으면 ESP `human_detected_raw=null`에서 `NO_OCC`로 멈추고, 센서 시계가 들쭉날쭉하면 `R1_TIME`으로 막힌다.

- B23 가중치/스케일러는 동결. 다시 학습·TFLite 변환하지 않는다.
- `PHYSIOLOGY_ELIGIBLE`(`PHYS_OK`)는 **병원 진단이 아니다.** 무호흡 판정도 아니다.
- Risk 점수(`RR_OK`/`RR_ABN`)는 아직 **벤더 BPM 룰**이 주이고, B23 RR은 화면에 보이더라도 위험도 공식의 주입력이 아니다.

### `/display` 라우트 (필드 필수)

팀 `main` 원본 `backend/app.py`에는 `/display`가 없을 수 있다.
필드 Pi에는 LCD 정적 파일(`RaspberryPi/LCD/static`)을 `:8000`에서 서빙하도록 **로컬 패치**가 들어가 있다.

기동 후 반드시:

```bash
curl -s -o /dev/null -w "%{http_code}\n" http://127.0.0.1:8000/display
# 기대: 200
```

`404`면 LCD HTML이 안 나온다. `app.py`에 `/display`, `/common.css` 라우트가 있는지 확인하고 백엔드를 재기동한다.
`git pull` / `git reset` 하면 이 패치가 날아갈 수 있으니, pull 후 `/display`가 **200**인지 다시 확인한다.

---

## 2. 평소 기동

### 2-A. 백엔드 (런타임)

```bash
cd /home/sandi/safenest-team-main

# 이미 떠 있으면 중복 기동하지 말 것
pgrep -af run_backend.py || true
ss -ltnp | grep -E ":8000|:9000" || true
ss -lunp | grep 5005 || true

# 백그라운드 기동
mkdir -p logs
nohup bash ./run_safenest.sh > logs/runtime.log 2>&1 &
echo $! > .runtime.pid
```

포그라운드로 보려면:

```bash
cd /home/sandi/safenest-team-main
bash ./run_safenest.sh
```

Thermal V2 후보를 같은 스택에서 바꿔 보려면 (기본 `./run_safenest.sh`는 기존 baseline 유지):

```bash
bash ./run_safenest_thermal_test.sh baseline
bash ./run_safenest_thermal_test.sh a
bash ./run_safenest_thermal_test.sh b
```

Thermal baseline/A/B 현장 비교·LCD·필드 모니터 모델 확인은 **`PI_RUNBOOK_THERMAL.md`** 를 본다. 핫 스위칭 없음. Team default는 바뀌지 않는다.

기동 직후 확인:

```bash
curl -fsS http://127.0.0.1:8000/health
curl -s -o /dev/null -w "display:%{http_code}\n" http://127.0.0.1:8000/display
ss -ltnp | grep -E ":8000|:9000"
ss -lunp | grep 5005
```

기대 포트:

| 포트 | 역할 |
|---|---|
| TCP `:8000` | FastAPI / Web / **LCD `/display`** / admin |
| TCP `:9000` | ESP 스칼라 텔레메트리 (mmWave / CO₂ / PIR) |
| UDP `:5005` | ESP 열화상 프레임 |

URL:

- LCD / display: `http://192.168.0.3:8000/display`
- Admin: `http://192.168.0.3:8000/admin`
- Dashboard: `http://192.168.0.3:8000/dashboard`
- Health: `http://192.168.0.3:8000/health`
- Status: `http://192.168.0.3:8000/api/status`
- LCD state API: `http://192.168.0.3:8000/api/state`

### 2-B. LCD에 화면 띄우기 (Chromium 키오스크)

백엔드가 떠 있고 `/display`가 **200**인 다음, **Pi 본체 디스플레이(seat0 / `:0`)** 에서:

```bash
export DISPLAY=:0
export WAYLAND_DISPLAY=wayland-0
export XDG_RUNTIME_DIR=/run/user/1000
[ -f "$HOME/.Xauthority" ] && export XAUTHORITY="$HOME/.Xauthority"

# 이미 떠 있으면 재실행 전 종료
pkill -f "chromium.*8000/display" 2>/dev/null || true

nohup chromium --kiosk --noerrdialogs --disable-infobars \
  --check-for-update-interval=31536000 \
  --user-data-dir=/tmp/safenest-chromium-display \
  --ozone-platform=x11 \
  http://127.0.0.1:8000/display \
  >/tmp/chromium-display.log 2>&1 &
```

확인:

```bash
pgrep -af "chromium.*8000/display" | head -3
# 물리 LCD에 SafeNest 화면이 보이는지 확인
```

일반 창(키오스크 아님):

```bash
DISPLAY=:0 chromium http://127.0.0.1:8000/display &
```

SSH만으로는 LCD가 안 바뀐다. Chromium은 **Pi의 그래픽 세션(`DISPLAY=:0`)** 으로 띄워야 한다.

---

## 3. 중지 / 재시작

```bash
cd /home/sandi/safenest-team-main

# Chromium LCD
pkill -f "chromium.*8000/display" 2>/dev/null || true

# 백엔드
kill "$(cat .runtime.pid)" 2>/dev/null || true
pkill -f "backend/run_backend.py" || true

# 포트 비었는지 확인
ss -ltnp | grep -E ":8000|:9000" || echo "tcp free"
ss -lunp | grep 5005 || echo "udp free"

# 다시 기동: 2-A → 2-B
```

---

## 3-B. 필드 모니터 (저장 / AI 입력 / 통신 / LCD)

파일: `RaspberryPi/Runtime/hil/pi_field_monitor.py`
실행(계속): `cd …/RaspberryPi/Runtime && python3 hil/pi_field_monitor.py`
실행(한 번): 같은 명령 + `--once` / 종료: `Ctrl+C` / 맥 원격: `--base http://192.168.0.3:8000`

헤더 `Thermal:` 줄은 GET `/api/status`의 `runtime_status.model_selector`다. A/B 전용 모니터 스크립트는 없다.

아래는 **화면에 나오는 표 4개를 읽는 법**이다. 위→아래 순서로 본다.

공통 기호:

| 기호 | 의미 |
|---|---|
| `Δ` | 직전 샘플 대비 **이번 간격(기본 4초) 동안 증가량**. `+12`면 늘었음, `0`이면 그 구간 유입 없음 |
| `-` | 값 없음 / 해당 없음 |
| `…` | 칸이 좁아 잘린 문자열 (중요하면 터미널을 넓히거나 그 행 `detail`/`note`를 본다) |
| 헤더 `Δ window Ns` | 지금 표의 Δ가 몇 초 간격인지 |

ESP 끄기 전: Verdict가 대부분 `NO` / LCD `OFFLINE`인 것이 정상이다.
ESP 켠 뒤: **Δ가 양수인지**를 먼저 보면 된다.

---

### 표 1) `## Verdict` — 한눈에 YES/NO

열:

| 열 | 읽는 법 |
|---|---|
| `check` | 무엇을 판정했는지 |
| `ok?` | 판정 결과. 대부분 `YES`/`NO`. **LCD state 행만** 상태 문자열(`OFFLINE`, `NORMAL-EMPTY` 등) |
| `detail` | 판정에 쓰인 숫자·부가 설명 (`conn=`, `telem=`, `Δ=`, `fail=` …) |

행별로:

| check | ok? 읽는 법 | detail에서 볼 것 |
|---|---|---|
| `TCP flow` | `YES` = 이번 구간에 ESP TCP 패킷 증가 | `conn`, `telem`, `Δ` |
| `UDP flow` | `YES` = 열화상 완성 프레임 증가 | `frames`, `Δ` |
| `Save mmW` / `Save CO2` / `Save thm` | `YES` = 해당 센서가 디스크에 기록됨 | `n`, `Δ` |
| `DB grow` | `YES` = SQLite 스냅샷 증가 | `snap`, `ev`, `Δ` |
| `Log worker` | `YES` = 저장 워커 살아 있음 | `on`, 큐 `q`, `err` |
| `AI input` | `YES` = 센서가 LIVE이고 AI가 `NO_IN`이 아님 (`WARMUP`/`PHYS_OK`도 YES) | `ok=` 또는 `fail=` |
| `Risk` | `YES` = `formula_id`가 `SAFENEST_RISK_V1` | `score`, `level`, `evid` |
| `LCD state` | LCD 상태 문자열 | `room`, `rev` |

읽는 팁: 이상하면 **`ok?`가 NO인 행만** 보고, 그 행 `detail`의 `Δ=0`인지 `conn=0`인지부터 확인한다.

---

### 표 2) `## Link & storage` — 통신·저장 수치

열:

| 열 | 읽는 법 |
|---|---|
| `metric` | 항목 이름 |
| `now` | **지금 누적값** (또는 현재 상태 문자열) |
| `Δ` | 이번 간격 증가량. 흐름 판정의 핵심 |
| `note` | 부가 카운터·경로 |

행별로:

| metric | now | Δ가 의미하는 것 | note에서 볼 것 |
|---|---|---|---|
| `system` | `ONLINE/…` 또는 `OFFLINE/FAILED` | (보통 `-`) | `ready`, `offline` |
| `tcp:9000 conn` | ESP TCP 동시 연결 수 | 연결이 늘/줄었는지 | `disc` 끊김, `gaps` 시퀀스 갭, `proto_err` |
| `telemetry pkts` | 스칼라 텔레메트리 누적 패킷 | 패킷이 들어오는지 | unexpected thermal-on-TCP 등 |
| `udp:5005 frames` | 조립 완료된 열화상 프레임 누적 | 프레임이 들어오는지 | `dgram`, `incomplete`, `fps` |
| `log written mm/co2/thm` | 센서별 파일 기록 누적 | 저장이 도는지 | `accepted` vs `dropped` (드롭 많으면 큐/부하) |
| `db snapshots` | DB 스냅샷 개수 | 런타임이 주기적으로 기록하는지 | DB 경로 |
| `db events` | 이벤트 개수 | 이벤트 적재 | `schema`, `avail` |

읽는 팁:

- **흐름**은 `now`보다 **`Δ`** 를 본다. `now`만 크고 `Δ=0`이면 “예전에 쌓였고 지금은 안 들어옴”.
- `conn≥1`인데 `telemetry Δ=0`이면 소켓만 있고 페이로드가 안 오는 경우.
- `written Δ>0`이면 “AI 입력 전 단계인 저장”은 통과.

---

### 표 3) `## Sensors / AI / risk component` — 센서 한 줄씩

센서마다 한 행 (`mmwave` / `thermal` / `co2` / `pir`).
**이 열에 뜨는 문자열은 코드에 정해진 집합**이다. 아래 “경우별”을 보면 된다.

| 열 | 의미 | 좋은 예 | 나쁜 예 |
|---|---|---|---|
| `sensor` | 센서 ID | — | — |
| `status` | 센서 수신/신선도 | `LIVE` | `NONE`, `STALE`, `DISC`, `BAD` |
| `age_s` | 마지막 데이터 나이(초) | TTL 안쪽 | `-` / 큰 값 |
| `ai` | AI 짧은 라벨 (원문은 `--raw-labels`) | `PHYS_OK` 등 | `NO_IN` |
| `err` | 막힌 이유 짧은 코드 | `-` | `WARMUP`, `NO_OCC`, `R1_TIME` … |
| `score` | mmWave는 B23 **숨 확률**(0~1). 다른 센서는 기존 score | 숫자 | `-` |
| `ms` | 추론 지연 | 작은 숫자 | `-` |
| `risk` | Risk 성분 짧은 라벨 | `RR_OK` 등 | `NA` |
| `rsc` | Risk 성분 점수 | 숫자 | `-` |
| `values` | 힌트. mmWave는 `occ/latch/br/rr/q/vRR/r1` | 아래 3-C | `-` |

읽는 팁: 왼쪽→오른쪽 `status` → `ai_state`/`ai_err` → `risk_st`/`risk_sc` → `values`.

---

#### 표 3 · `status` (모든 센서 공통)

| 값 | 짧은 라벨 | 의미 |
|---|---|---|
| `LIVE` | `LIVE` | 최근 TTL 안 유효 데이터 |
| `NO_DATA` | `NONE` | 아직/전혀 유효 샘플 없음 |
| `STALE` | `STALE` | 예전에 왔지만 TTL 초과 |
| `DISCONNECTED` | `DISC` | 연결 끊김 |
| `INVALID` | `BAD` | 수신은 됐으나 유효성 실패 |
| `DEGRADED` | `DEG` | 시스템 저하 (센서 표보다 시스템 쪽에 흔함) |

---

#### 표 3 · `ai` — **thermal** (모델 `thermal_fall_int8`, 3클래스)

`probabilities` 순서 = `[NOT_HUMAN, HUMAN_NORMAL, HUMAN_FALL]`.

| 원문 | 짧은 라벨 | 의미 | 필드에서 |
|---|---|---|---|
| `NOT_HUMAN` | `NO_HUM` | 배경/비인간 (class 0) | 사람 없음·화각 밖·자주 |
| `HUMAN_NORMAL` | `HUMAN` | 사람 정상 자세 (class 1) | 서 있/앉아 있음 |
| `HUMAN_FALL` | `FALL` | 전도/누움 (class 2) | 낙상·누운 자세로 판단 |
| `INPUT_UNAVAILABLE` | `NO_IN` | 모델 입력 없음 | `status`가 LIVE가 아니거나 프레임 없음 |

---

#### 표 3 · `ai` — **co2** (C-B6, 2클래스)

| 원문 | 짧은 라벨 | 의미 |
|---|---|---|
| `VACANT` | `VACANT` | 공실 쪽 |
| `OCCUPIED` | `OCC` | 재실 쪽 |
| `INPUT_UNAVAILABLE` | `NO_IN` | CO₂ 입력/윈도우 불가 |

---

#### 표 3 · `ai` — **mmwave** (B23 프로토타입, 현재 기본)

M-N9의 `NORMAL` / `RAPID_OR_ABNORMAL` / `APNEA` 는 **기본 경로가 아니다.** 옛 경로가 보이면 런타임이 B23가 아닌 것이다.

B23는 30초 위상 창을 돌려 **숨 있음 여부 + 품질 + 호흡수** 세 헤드를 낸다. 무호흡(APNEA) 클래스를 내지 않는다.

| 원문 | 짧은 라벨 | 한 줄 의미 |
|---|---|---|
| `PHYSIOLOGY_ELIGIBLE` | `PHYS_OK` | B23 추론 성공. 숨 있음 + 품질 통과 + RR 숫자 있음 |
| `ABSENT` | `ABSENT` | 모델이 “숨 약함/없음” 쪽으로 판단. 무호흡 진단 아님 |
| `QUALITY_SUPPRESSED` | `Q_LOW` | 숨은 있다 했지만 품질이 낮아 RR을 안 냄 |
| `RR_UNAVAILABLE` | `NO_RR` | 품질은 됐는데 RR 숫자를 못 디코드 |
| `WINDOW_NOT_READY` | `WARMUP` | 300샘플(약 30초) 창이 아직 안 참 |
| `PRESENCE_UNAVAILABLE` | `NO_OCC` | 재실 bool을 한 번도 못 받음 (`null`만) |
| `PRESENCE_FALSE` | `EMPTY` | 재실=없음(빈 방). 추론 안 함 |
| `WINDOW_UNAVAILABLE` | `NO_WIN` | **옛 M-N9/정규창** 실패 코드. B23 기본 경로면 잘 안 나옴 |
| `INPUT_UNAVAILABLE` | `NO_IN` | 센서 입력 자체 없음 |

`PHYSIOLOGY_ELIGIBLE` 상세는 **3-C**.

---

#### 표 3 · `ai` — **pir** (룰, 모델 없음)

| 원문 | 짧은 라벨 | 의미 |
|---|---|---|
| `MOTION` | `MOVE` | 움직임 감지 |
| `NO_MOTION` | `STILL` | 움직임 없음 |
| `INPUT_UNAVAILABLE` | `NO_IN` | PIR 입력 없음 |

---

#### 표 3 · `risk` — Risk 성분 state (formula_v1)

모니터 `risk` 열은 **성분 state**다. Verdict의 `AI`/`RULE`/`RULE_FALLBACK`과는 별개.

**thermal**

| 원문 | 짧은 라벨 | 의미 |
|---|---|---|
| `NOT_HUMAN` / `HUMAN_NORMAL` / `HUMAN_FALL` | `NO_HUM` / `HUMAN` / `FALL` | 열화상 AI를 그대로 사용 |
| `UNAVAILABLE` | `NA` | 비LIVE 또는 AI 차단 |

**mmwave**

| 원문 | 짧은 라벨 | 의미 |
|---|---|---|
| `RESPIRATION_NORMAL` | `RR_OK` | 벤더 BPM이 정상 구간 |
| `RESPIRATION_ABNORMAL` | `RR_ABN` | 벤더 BPM이 이상 구간 (지속되면 점수↑) |
| `UNAVAILABLE` | `NA` | 호흡 입력 없음 |

중요: 이 열은 **B23 RR이 아니라 MR60 벤더 `breath_rate_raw`(모니터 `vRR`)** 로 계산되는 경우가 많다. `ai=PHYS_OK` 인데 `risk=RR_ABN` 이면 “모델은 돌았고, 위험도 공식은 벤더 BPM을 보고 있다”는 뜻이다. B23 출력은 현재 **관찰용**이다.

**co2**

| 원문 | 짧은 라벨 | 의미 |
|---|---|---|
| `CO2_NORMAL` | `CO2_OK` | ppm·기울기 정상 |
| `CO2_WARNING` | `CO2_WN` | 경고 |
| `CO2_DANGER` | `CO2_DG` | 위험 |
| `CO2_IMMEDIATE_DANGER` | `CO2_NOW` | 즉시 위험 |
| `UNAVAILABLE` | `NA` | CO₂ 입력 없음 |

**pir**

| 원문 | 짧은 라벨 | 의미 |
|---|---|---|
| `MOTION` | `MOVE` | 움직임 있음 |
| `NO_MOTION` | `STILL` | 단시간 무움직임 |
| `NO_MOTION_RISING` | `STILL+` | 무움직임이 위험 점수로 상승 중 |
| `LONG_NO_MOTION` | `STILL++` | 장시간 무움직임 |
| `UNAVAILABLE` | `NA` | PIR 입력 없음 |

---

#### 표 3 · 지금 필드에서 자주 보는 조합

짧은 라벨 기준.

| 행 | status | ai | err | risk | 해석 |
|---|---|---|---|---|---|
| thermal | `LIVE` | `NO_HUM` | `-` | `NO_HUM` | 프레임 OK, 모델이 비인간 |
| thermal | `LIVE` | `HUMAN` | `-` | `HUMAN` | 열화상 재실·정상 |
| thermal | `LIVE` | `FALL` | `-` | `FALL` | 열화상 전도 클래스 |
| thermal | `LIVE` | `NO_IN` | `INT8` | `NA` | 모델 파일은 있는데 INT8 리뷰로 추론 안 함 |
| mmwave | `LIVE` | `WARMUP` | `WARMUP` | `RR_*` | 패킷은 오는데 30초 창 모으는 중 |
| mmwave | `LIVE` | `PHYS_OK` | `-` | `RR_OK` 또는 `RR_ABN` | **B23 추론 중.** risk는 벤더 BPM |
| mmwave | `LIVE` | `NO_OCC` | `NO_OCC` | `RR_*` | 창은 돼도 재실 bool이 한 번도 없음 |
| mmwave | `LIVE` | `EMPTY` | `EMPTY` | `RR_*` | 빈 방으로 래치. 추론 안 함 |
| mmwave | `LIVE` | `-`/`NO_IN` | `R1_TIME` | `RR_*` | 어댑터 없이 센서 시계를 R1에 넣음 → 격자 거절 |
| mmwave | `LIVE` | `NO_WIN` | `GAP` | `RR_*` | 옛 M-N9 창 실패 + 룰 폴백 |
| co2 | `LIVE` | `OCC` | `-` | `CO2_WN` | 재실 AI + ppm 경고 |
| co2 | `BAD` | `NO_IN` | `BAD` | `NA` | CO₂ 값이 유효하지 않음 |
| pir | `LIVE` | `STILL` | `-` | `STILL+` | 무움직임이 점수로 반영 중 |
| * | `NONE` | `NO_IN` | `NO_DATA` | `NA` | ESP/해당 채널 미수신 |

`err=NO_DATA` 이면 모델 버그가 아니라 **센서 미수신**이다.

---

## 3-C. B23 / 짧은 라벨 사전 (지금 런북에 없던 것)

### `PHYSIOLOGY_ELIGIBLE` (`PHYS_OK`)는 무슨 뜻인가

B23가 **이번 30초 위상 창**을 모델에 넣었고, 세 헤드가 전부 통과했다는 뜻이다.

1. **숨 헤드** `br` (breathing_probability) ≥ 임계값 → `PRESENT` (모니터 `br=0.6` 같은 값)
2. **품질 헤드** `q` ≥ 임계값 → 이 창을 RR로 써도 된다고 모델이 봄
3. **RR 헤드**가 숫자로 디코드됨 → 모니터 `rr=15` (B23 호흡수, **벤더 BPM이 아님**)

그래서 이름은 “생리학적으로 쓸 수 있는 출력(physiology eligible)”이다.

**아닌 것**

- 병원/임상 적격이 아니다
- 무호흡(APNEA) 판정이 아니다. B23는 APNEA 클래스를 안 낸다
- 최종 선정 모델이 아니다 (프로토타입, 교체 대상)
- Risk 위험도 공식에 이 숫자가 그대로 들어간다는 뜻이 아니다 (`vRR` 룰이 따로 있음)
- LCD “정상/경고”와 1:1이 아니다

같은 창에서 `ABSENT`가 나오면 숨 확률이 낮다는 뜻이지, “임상 무호흡”이 아니다.

### B23가 돌아가기까지의 문

```
ESP 위상 → 신선도(phase_age) OK → 샘플 300개 모음
        → 재실 래치가 true
        → R1이 10Hz 300개로 받음
        → R2 621벡터
        → B23 PyTorch
        → PHYS_OK / ABSENT / Q_LOW / NO_RR
```

| 짧은 라벨 | 원문 | 언제 | 다음에 볼 것 |
|---|---|---|---|
| `WARMUP` | `WINDOW_NOT_READY` | 기동 후 ~30초, 또는 갭/부트 후 창 리셋 | `r1` 비어 있음. seq가 늘면 기다림 |
| `NO_OCC` | `PRESENCE_UNAVAILABLE` | ESP가 `human_detected_raw`를 계속 `null`만 보냄. **한 번도 true/false가 없음** | values `occ=? latch=?` |
| `EMPTY` | `PRESENCE_FALSE` | 재실=false (빈 방)로 래치됨 | 사람 있으면 ESP true가 나와야 함 |
| `PHYS_OK` | `PHYSIOLOGY_ELIGIBLE` | 위 문 통과 + 세 헤드 통과 | `br` `rr` `q` |
| `ABSENT` | `ABSENT` | 모델이 숨 없음 쪽 | `br`가 낮음. APNEA 아님 |
| `Q_LOW` | `QUALITY_SUPPRESSED` | 숨은 있다 했지만 품질 실패 | RR 없음 |
| `NO_RR` | `RR_UNAVAILABLE` | 품질 OK, RR 디코드 실패 | 창/위상 이상 가능 |
| `R1_TIME` | `R1_TIMESTAMP_GRID_INCONSISTENT` | 물리 `millis()`를 그대로 R1에 넣음. Seeed는 ~9.8Hz 들쭉날쭉 | 샘플 인덱스 어댑터가 없는 빌드 |
| `R1_N` | `R1_SAMPLE_COUNT_MISMATCH` | R1 출력이 300개가 아님 | 창 길이 |
| `SLOW` | `SOURCE_RATE_BELOW_TARGET` | 선언 샘플레이트가 10Hz 미만 (어댑터 없는 옛 경로) | |
| `GAP` | `WINDOW_CONTAINS_LARGE_GAP` / 내부 큰 간격 | 0.5초 넘게 위상 공백이면 창을 이어 붙이지 않음 | |
| `NO_PH` | `PHASE_MISSING` | `breath_phase`가 없음/NaN | UART/펌웨어 |
| `OLD_PH` | `PHASE_STALE` | `phase_age_ms`가 너무 큼 (>1000) | |
| `BOOT` | `BOOT_BOUNDARY` | ESP `boot_id`가 바뀜. 창·재실 래치 리셋 | 다시 30초 |
| `BAD_TS` | `TIMESTAMP_INVALID` | `ts_monotonic_ms` 없음 | |
| `NO_SEQ` | `PHASE_SEQUENCE_MISSING` | nested `mmwave.seq` 없음 | |
| `NO_IN` | `INPUT_UNAVAILABLE` / `SENSOR_*` | 센서 LIVE가 아님 | `status` |
| `NO_DATA` | `SENSOR_NO_DATA` | 미수신 | ESP·`:9000` |
| `BAD` | `SENSOR_INVALID` / `INVALID` | 값 유효성 실패 | |
| `STALE` | `SENSOR_STALE` | TTL 초과 | |
| `DISC` | `SENSOR_DISCONNECTED` | 소켓 끊김 | `TCP flow` |
| `INT8` | `INT8_QUANTIZATION_REVIEW_REQUIRED` | 열화상 INT8 리뷰 게이트 | thermal만 |

### 재실 래치 (지금 필드에서 꼭 필요)

ESP `human_detected_raw`는 삼값이다: `true` / `false` / `null`.

- `null` = 모름. **없다로 바꾸면 안 됨**
- 이 ESP는 `true`가 **한 패킷만** 깜빡이고 대부분은 `null`. `false`는 거의 없음
- 모니터: `occ=Y/N/?` = **지금 패킷**, `latch=Y/N/?` = **B23가 쓰는 유지값**
- `occ=?` 인데 `latch=Y` 이고 `ai=PHYS_OK` 이면 정상 (래치가 펄스를 기억)
- `latch=?` 이면 기동 이후 true/false를 한 번도 못 본 것 → `NO_OCC`, 추론 없음
- `false`가 오면 래치가 풀림(`EMPTY`). ESP 재부팅(`BOOT`)이면 래치도 리셋

### 10Hz 샘플 인덱스 (R1_TIME을 넘는 방법)

B23/R1은 **초당 10개, 간격이 일정한 300개**를 기대한다.
실제 MR60 시계는 대략 초당 9.8개이고 간격이 흔들려, 그대로 넣으면 `R1_TIME`.

필드 어댑터:

- 물리 `ts_monotonic_ms` → 신선도·0.5초 갭·부트 검사용
- R1에 넣는 시각 → 들어온 위상 샘플 번호 × 0.1초
- 창이 차면 `r1=300` (모니터 values)

물리로 0.5초 넘게 끊기면 창을 이어 붙이지 않는다. nested seq가 +1이 아니면 기존처럼 창이 리셋될 수 있다.

### mmWave `values` 칸

| 키 | 의미 |
|---|---|
| `occ` | ESP가 **지금** 보낸 재실 (`Y`/`N`/`?`) |
| `latch` | B23 게이트가 유지 중인 재실 |
| `br` | B23 숨 확률 0~1 |
| `rr` | B23 호흡수 (모델) |
| `q` | B23 품질 확률 |
| `vRR` | 벤더 `breath_rate_raw` (모델 입력 아님, Risk가 이걸 봄) |
| `r1` | R1 샘플 수. 추론 중이면 300 |
| `B23` | 런타임이 `M_PROT_B23` |

게시 주기: 센서 패킷은 ~10Hz, `/api/status`의 AI 숫자는 **약 15초**마다 바뀔 수 있다. 모니터가 4초여도 `br`/`rr`이 몇 번 동일하게 보이는 것이 정상이다.

### 기동 직후 타임라인

1. ESP 붙음 → `TCP flow YES`, mmwave `LIVE`, `ai=WARMUP`
2. ~26–35초, 재실 펄스 1회라도 있으면 `latch=Y`
3. `ai=PHYS_OK`, `r1=300`, `br`/`rr`/`q` 숫자
4. `vRR`와 `rr`이 달라도 버그 아님 (소스가 다름)

재실 펄스가 전혀 없으면 창이 차도 `NO_OCC`에서 멈춘다.

### 옛 코드가 모니터에 남을 때

| 보이면 | 의미 |
|---|---|
| `NORMAL` / `RAPID` / `APNEA` | M-N9 경로. 지금 기본이 아님 |
| `NO_WIN` + `GAP` | 옛 240샘플/정규창 |
| torch 없음 / `NO_MDL` | 가중치는 있는데 런타임이 모델을 못 염 |

긴 원문을 보려면:

```bash
python3 hil/pi_field_monitor.py --raw-labels
```

### 표 4) `## Risk / LCD (display)` — 위험도·LCD 문구

키-값 표. LCD 화면과 맞춰 볼 때 쓴다.

| field | 읽는 법 |
|---|---|
| `formula_id` | `SAFENEST_RISK_V1`이어야 함 |
| `formula_version` | 공식 버전 문자열 |
| `risk_score / level` | 점수 / 레벨(`warning`·`danger` 등). 센서 없으면 `None` |
| `effective_weight` | 가용 성분 가중 합. `0`이면 성분 없음 |
| `evidence_sufficient` | 증거 충분한지 (`True`/`False`) |
| `presence` | 재실 판정과 출처 (`UNCONFIRMED` 등) |
| `degraded_mode` | 저하 모드 여부 |
| `reasons` | Risk가 그렇게 나온 **이유 코드** 나열 (디버그 핵심) |
| `LCD state` | LCD가 쓰는 상태 키 (`offline`, `normal-empty`, `warning` …). 물리 LCD와 같아야 함 |
| `LCD room` | 표시 공간 이름 |
| `LCD revision` | LCD 상태 revision |
| `pub_revision` | 백엔드 publication revision (내부 갱신 카운트) |

읽는 팁:

- LCD에 “통신 오류”면 여기 `LCD state=offline` + `reasons`에 `*_SENSOR_NO_DATA`가 같이 있는 경우가 많다.
- `formula_id`는 YES인데 `risk_score=None`이면 **엔진은 떠 있고 입력만 없는** 상태.

---

### 네 표를 이어서 읽는 짧은 순서

1. **Verdict**에서 NO인 행만 고른다.
2. 통신 NO → **Link & storage**의 `tcp:9000 conn` / `telemetry`·`udp frames`의 **Δ**.
3. 저장 NO → 같은 표의 `log written *` **Δ** / `Logging worker`.
4. AI NO → **Sensors** 표에서 해당 센서 `status`·`err`. mmWave면 **3-C**.
5. LCD 문구 이상 → **Risk / LCD**의 `LCD state` + `reasons`.

## 4. ESP 켜기 전 / 후

### ESP 켜기 전

- Pi 런타임만 먼저 올려 두면 된다 (`:9000` / `:5005` listen).
- 이 상태에서는 `/api/status`가 `NO_DATA` / `OFFLINE`인 것이 정상이다.
- LCD는 `offline` / 센서 연결 대기처럼 보일 수 있다.

### ESP 목표 주소 (필수)

ESP 펌웨어 / 설정의 Pi 주소를 **현재 Pi IP**로 맞춘다.

```text
TCP  → 192.168.0.3:9000
UDP  → 192.168.0.3:5005
```

IP가 또 바뀌면 ESP 쪽도 같이 갱신한다.

### ESP 켠 뒤 (3~4분 warm-up)

```bash
# 연결 여부
ss -Htn state established "( sport = :9000 or dport = :9000 )"

# 상태 스냅샷
curl -fsS http://127.0.0.1:8000/api/status | python3 -m json.tool | less
```

짧게 증가량만 보려면:

```bash
python3 - <<'PY'
import json, time, urllib.request
def get(p):
    return json.load(urllib.request.urlopen("http://127.0.0.1:8000"+p, timeout=5))
a=get("/health"); time.sleep(4); b=get("/health")
ra,rb=a["receiver"],b["receiver"]
print("tcp_conn", ra.get("connections"), "->", rb.get("connections"))
print("telemetry", ra.get("telemetry_packets"), "->", rb.get("telemetry_packets"))
ua,ub=ra.get("thermal_udp") or {}, rb.get("thermal_udp") or {}
print("thermal_frames", ua.get("completed_frames"), "->", ub.get("completed_frames"))
s=get("/api/status")
print("system", s.get("system"), s.get("system_health"))
r=s.get("risk") or {}
print("risk", r.get("formula_id"), r.get("risk_score"), r.get("risk_level"), r.get("component_status"))
for name in ("mmwave","thermal","co2","pir"):
    st=(s.get(name) or {}).get("state") or {}
    print(name, st.get("status"), "age", st.get("age_seconds") or st.get("age_s"))
PY
```

---

## 5. 프로토타입 PASS 기준 (필드)

모두 만족해야 PASS:

1. mmWave / Thermal / CO₂ / PIR → **LIVE** (또는 허용된 DEGRADED만)
2. 저장(`sensor_logging.written`)이 증가
3. Risk가 **`SAFENEST_RISK_V1`**으로 연속 산출
4. **물리 LCD**에 `/display` 화면 + admin / health / status 사용 가능

허용:

- mmWave Risk `RULE_FALLBACK` / `RR_ABN` (벤더 BPM 룰). B23 `PHYS_OK`와 동시에 나올 수 있음
- 일부 `DEGRADED`
- `DEVICE_VALIDATED=false`

B23 `PHYS_OK`는 프로토타입 PASS의 **가산 증거**이지, 임상 PASS가 아니다.

권장 펌웨어:

- ESP ≥ **1.3.0**, 텔레메트리에 `human_detected_raw` 포함 (`true`가 가끔이라도 나와야 래치됨)

---

## 6. 업데이트 (코드만 최신으로)

런타임이 떠 있으면 먼저 중지한 뒤:

```bash
cd /home/sandi/safenest-team-main
git fetch origin
git pull --ff-only origin main
# 의존성이 바뀌었을 때만
bash ./run_safenest.sh --install
# 다시 기동 (2-A) 후 /display 200 확인 → 2-B
```

**주의:**

- `data/` 와 `.env` 는 지우거나 `git reset --hard`로 날리지 않는다.
- pull 후 `/display`가 404면 LCD 라우트 패치를 다시 넣고 백엔드를 재기동한다.
- `git pull`은 Pi에 있는 **B23 런타임 어댑터**(재실 래치·10Hz 인덱스)를 덮어쓸 수 있다. pull 뒤 mmWave가 `NO_OCC`/`R1_TIME`이면 어댑터가 빠진 것이다.

---

## 7. 로그 / 데이터 위치

| 경로 | 내용 |
|---|---|
| `logs/runtime.log` | nohup 기동 로그 |
| `.runtime.pid` | 백그라운드 PID |
| `/tmp/chromium-display.log` | LCD Chromium 로그 |
| `RaspberryPi/Runtime/data/` | SQLite·필드 데이터 (보존) |
| `RaspberryPi/LCD/static/` | LCD HTML/CSS (백엔드가 서빙) |
| `.env` | 로컬 설정 (git 제외) |

---

## 8. 자주 막히는 것

| 증상 | 확인 |
|---|---|
| `:8000` 이미 사용 | 예전 `run_backend` / LCD `server.py` 남아 있음 → `pkill` 후 재기동 |
| `/display` → **404** | `app.py`에 LCD 라우트 없음 / pull로 패치 소실 → 패치 후 재기동 |
| Chromium은 떴는데 LCD 검정/빈 화면 | `curl`로 `/display`·`/common.css`·`/api/state`가 200인지 확인 |
| Chromium이 안 뜸 / 즉시 종료 | `DISPLAY=:0`, `XDG_RUNTIME_DIR=/run/user/1000`, `/tmp/chromium-display.log` |
| ESP 연결 0 | ESP 목표 IP가 옛 주소(`192.168.137.x` 등)인지 확인 |
| 센서 NO_DATA / `NONE` | ESP 전원/와이파이, `:9000` established, warm-up 3~4분 |
| Risk UNAVAILABLE | 센서 유입 없음 → 수신부터 해결 |
| mmWave `ai=WARMUP` | 기동 후 30초 대기. seq가 늘면 정상 |
| mmWave `ai=NO_OCC` | ESP 재실이 계속 `null`. `occ=? latch=?`. 사람이 레이더 앞에 있어야 `true` 펄스라도 옴 |
| mmWave `ai=PHYS_OK` 인데 LCD/Risk가 이상 | B23는 관찰용. Risk는 `vRR` 벤더 BPM. **3-C** |
| mmWave `err=R1_TIME` | 샘플 인덱스 어댑터 없는 빌드. 물리 시계를 R1이 거절 |
| `br`/`rr`이 안 바뀜 | `/api/status` 게시 ~15초. 패킷 age_s가 작으면 통신은 살아 있음 |
| 필드 모니터 글자가 `…`로 잘림 | 짧은 라벨이 기본. 원문은 `--raw-labels`. 의미는 **3-C** |

---

## 9. 한 줄 요약

```bash
cd /home/sandi/safenest-team-main
bash ./run_safenest.sh --install   # 최초만
bash ./run_safenest.sh             # 2-A 백엔드
curl -s -o /dev/null -w "%{http_code}\n" http://127.0.0.1:8000/display   # 200이어야 함
# 2-B LCD
DISPLAY=:0 XDG_RUNTIME_DIR=/run/user/1000 \
  chromium --kiosk --ozone-platform=x11 \
  --user-data-dir=/tmp/safenest-chromium-display \
  http://127.0.0.1:8000/display &
# ESP → 192.168.0.3:9000 / :5005
```

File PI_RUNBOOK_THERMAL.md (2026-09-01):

# SafeNest Thermal V2 Pi 필드 실행 가이드

Raspberry Pi 옆에서 Thermal baseline / Candidate A / Candidate B를 바꿔 켜고 확인하는 **현장 운영 매뉴얼**이다.
일반 SafeNest 기동은 `PI_RUNBOOK.md`. 이 문서는 Thermal 비교만 다룬다.

기준 경로: `/home/sandi/safenest-team-main`
기준 저장소: `jinsu1011/safenest-embedded-competition`
필드 IP(바뀔 수 있음): `192.168.0.3`

**팀 기본 Thermal은 바뀌지 않았다.** `./run_safenest.sh`는 계속 `thermal_public_sdt_fp32_active`다. A를 켠다고 Team default가 바뀌는 것이 아니다.

---

## 0. 가장 빠른 실행 요약

```bash
cd /home/sandi/safenest-team-main
git fetch origin
git switch main
git pull --ff-only origin main
git rev-parse HEAD
```

이미 떠 있는 SafeNest가 있으면 먼저 끈다 (핫 스위칭 없음):

```bash
kill "$(cat .runtime.pid)" 2>/dev/null || true
pkill -f "backend/run_backend.py" || true
ss -ltnp | grep -E ":8000|:9000" || echo "tcp free"
```

**하나만** 고른다.

```bash
# 기존 Team baseline (비교용 런처. 기본 모델과 동일 selector)
bash ./run_safenest_thermal_test.sh baseline

# Candidate A  (offline A_PREFERRED, CONTROLLED_TEAM_TEST, 기본값 아님)
bash ./run_safenest_thermal_test.sh a

# Candidate B  (offline B_NOT_COMPETITIVE, 비교 전용)
bash ./run_safenest_thermal_test.sh b
```

다른 터미널에서 필드 모니터 (스크립트는 하나뿐):

```bash
cd /home/sandi/safenest-team-main/RaspberryPi/Runtime
python3 hil/pi_field_monitor.py
```

헤더에 아래처럼 보여야 한다.

```text
Thermal: BASELINE | thermal_public_sdt_fp32_active | PUBLIC_SDT_BILINEAR_62X80_FRAME_MINMAX_V1
Thermal: A | thermal_tv2_candidate_a_a0_fp32_v1 | FRAME_ROBUST_P2_P98_V1
Thermal: B | thermal_tv2_candidate_b_seed42_fp32_test_v1 | FRAME_ROBUST_P2_P98_V1
```

이 줄은 **프로세스가 어떤 모델을 들고 기동했는지**다. 센서 LIVE / 추론 성공을 증명하지 않는다.

LCD는 백엔드와 별개다. `/display`가 200인 뒤 Chromium을 Pi 그래픽 세션에서 연다 (4절).

---

## 1. Pi 최신화

```bash
cd /home/sandi/safenest-team-main
git fetch origin
git switch main
git pull --ff-only origin main
git rev-parse HEAD
```

- 실행은 **이 클론만**. `/home/sandi/integration`, `/home/sandi/safenest-runtime` 등 옛 클론은 기동하지 말 것.
- `main`을 Pi에서 직접 고치지 말 것. 변경은 worktree → PR → merge → 여기 `git pull --ff-only`.
- 의존성이 비어 있으면 최초 1회: `bash ./run_safenest.sh --install`

---

## 2. 서버 실행

모델은 **프로세스 기동 시 한 번** 고른다. 실행 중 전환은 없다.

| 상황 | 명령 | selector | 의미 |
|---|---|---|---|
| 평소 SafeNest | `bash ./run_safenest.sh` | `thermal_public_sdt_fp32_active` | Team 기본. 테스트 모드 아님 |
| 비교 baseline | `bash ./run_safenest_thermal_test.sh baseline` | 같은 selector | 비교 런처로 baseline 고정 |
| Candidate A | `bash ./run_safenest_thermal_test.sh a` | `thermal_tv2_candidate_a_a0_fp32_v1` | A_PREFERRED offline / 기본값 아님 |
| Candidate B | `bash ./run_safenest_thermal_test.sh b` | `thermal_tv2_candidate_b_seed42_fp32_test_v1` | B_NOT_COMPETITIVE / 비교만 |

런처는 기존 `run_safenest.sh`를 `exec`한다. 새 런타임 프로그램이 아니다.

기동 전 중복 확인:

```bash
cd /home/sandi/safenest-team-main
pgrep -af run_backend.py || true
ss -ltnp | grep -E ":8000|:9000" || true
ss -lunp | grep 5005 || true
```

### 2-A. baseline (비교 런처)

포그라운드 (디버그용, 로그가 바로 보임):

```bash
cd /home/sandi/safenest-team-main
bash ./run_safenest_thermal_test.sh baseline
```

백그라운드 (LCD / 모니터를 다른 터미널에서 쓸 때):

```bash
cd /home/sandi/safenest-team-main
mkdir -p logs
nohup bash ./run_safenest_thermal_test.sh baseline \
  > logs/runtime-thermal-baseline.log 2>&1 &
echo $! > .runtime.pid
```

### 2-B. Candidate A

```bash
# foreground
bash ./run_safenest_thermal_test.sh a

# background
mkdir -p logs
nohup bash ./run_safenest_thermal_test.sh a \
  > logs/runtime-thermal-a.log 2>&1 &
echo $! > .runtime.pid
```

### 2-C. Candidate B

```bash
# foreground
bash ./run_safenest_thermal_test.sh b

# background
mkdir -p logs
nohup bash ./run_safenest_thermal_test.sh b \
  > logs/runtime-thermal-b.log 2>&1 &
echo $! > .runtime.pid
```

### 2-D. 평소 기동 (비교가 아닐 때)

```bash
# foreground
bash ./run_safenest.sh

# background
mkdir -p logs
nohup bash ./run_safenest.sh > logs/runtime.log 2>&1 &
echo $! > .runtime.pid
```

`./run_safenest.sh`와 `./run_safenest_thermal_test.sh baseline`은 **같은 Thermal selector**다. 차이는 비교 런처가 `SAFENEST_THERMAL_TEST_MODE=1`을 켠다는 점뿐이다. Team default를 바꾸려면 코드/매니페스트를 바꿔야 하며, 이 런처로는 바뀌지 않는다.

포그라운드 = 즉시 로그 확인. 백그라운드 = LCD·모니터용. 둘 다 같은 런처다.

---

## 3. 현재 Thermal 모델 확인

기동 직후:

```bash
curl -fsS http://127.0.0.1:8000/health
curl -fsS http://127.0.0.1:8000/api/status >/tmp/safenest-status.json
curl -s -o /dev/null -w "display:%{http_code}\n" http://127.0.0.1:8000/display
ss -ltnp | grep -E ":8000|:9000"
ss -lunp | grep 5005
```

selector만 읽기 (`jq` 불필요, 표준 Python):

```bash
python3 - <<'PY'
import json, urllib.request
s = json.load(urllib.request.urlopen("http://127.0.0.1:8000/api/status"))
th = s.get("thermal") if isinstance(s.get("thermal"), dict) else {}
rt = th.get("runtime_status") or ((s.get("runtime_status") or {}).get("sensors") or {}).get("thermal") or {}
print("selector:", rt.get("model_selector") or "-")
print("preprocessing:", rt.get("preprocessing_id") or "-")
print("model_id:", rt.get("model_id") or "-")
print("sha256:", rt.get("model_sha256") or "-")
print("ai_status:", rt.get("ai_status") or "-")
print("blocked:", rt.get("blocked_reason") or "-")
PY
```

프레임이 아직 없어도 selector는 나와야 한다. `ai_status=BLOCKED`여도 **선택된 모델**은 맞다. 추론 성공과 섞지 말 것.

---

## 4. LCD 화면 띄우기

서버 기동 ≠ LCD Chromium 기동.

1. 백엔드가 `:8000`을 듣고 있어야 한다.
2. `/display`가 HTTP 200이어야 한다.

```bash
curl -s -o /dev/null -w "%{http_code}\n" http://127.0.0.1:8000/display
# 기대: 200
```

3. Chromium은 **Pi 그래픽 세션**에서 연다. SSH만으로는 물리 LCD가 안 바뀐다.

```bash
export DISPLAY=:0
export WAYLAND_DISPLAY=wayland-0
export XDG_RUNTIME_DIR=/run/user/1000
[ -f "$HOME/.Xauthority" ] && export XAUTHORITY="$HOME/.Xauthority"

pkill -f "chromium.*8000/display" 2>/dev/null || true

nohup chromium --kiosk --noerrdialogs --disable-infobars \
  --check-for-update-interval=31536000 \
  --user-data-dir=/tmp/safenest-chromium-display \
  --ozone-platform=x11 \
  http://127.0.0.1:8000/display \
  >/tmp/chromium-display.log 2>&1 &
```

확인:

```bash
pgrep -af "chromium.*8000/display" | head -3
```

일반 창:

```bash
DISPLAY=:0 chromium http://127.0.0.1:8000/display &
```

현재 팀 `main`의 `backend/app.py`가 `/display`를 `RaspberryPi/LCD/static/display.html`로 서빙한다.

---

## 5. 필드 모니터

모니터는 **하나**다. baseline / A / B용 별도 스크립트 없음. 실행 중인 프로세스의 `/api/status`를 읽는다.

```bash
cd /home/sandi/safenest-team-main/RaspberryPi/Runtime
python3 hil/pi_field_monitor.py
python3 hil/pi_field_monitor.py --once
python3 hil/pi_field_monitor.py --interval 2
python3 hil/pi_field_monitor.py --raw-labels
```

원격:

```bash
python3 hil/pi_field_monitor.py --base http://<PI_IP>:8000
```

`Ctrl+C`는 모니터만 종료한다. SafeNest 백엔드는 그대로다.

헤더 예:

```text
SafeNest field monitor  |  2026-08-31 15:10:00  |  Δ window 4.0s
Thermal: A | thermal_tv2_candidate_a_a0_fp32_v1 | FRAME_ROBUST_P2_P98_V1
```

| 헤더 | 의미 |
|---|---|
| `Thermal: BASELINE \| thermal_public_sdt_fp32_active \| …` | 기본/비교 baseline |
| `Thermal: A \| thermal_tv2_candidate_a_a0_fp32_v1 \| …` | Candidate A |
| `Thermal: B \| thermal_tv2_candidate_b_seed42_fp32_test_v1 \| …` | Candidate B |
| `Thermal: UNKNOWN \| <raw>` | 매핑에 없는 selector. 원문을 그대로 둠 |
| `Thermal: UNAVAILABLE \| selector=-` | `/api/status`에 selector가 없음 |

이 줄은 프로세스 선택 결과다. Thermal AI가 유효한 예측을 내고 있는지는 아래 표의 `thermal` 행 (`status`, `ai`, `err`)과 Verdict `UDP flow`를 본다.

짧은 라벨 `FALL_PX` = `HUMAN_FALL_PROXY` (자세 프록시). 실제 낙상 확정이 아니다.

---

## 6. 모델 비교 순서

과학 검증 프로토콜이 아니다. 같은 자리에서 세 모델을 한 번씩 보는 현장 비교다.

1. 카메라/사람 위치를 최대한 고정한다.
2. baseline 기동 → 모니터/LCD 확인 → 서기 / 앉기 / 숙이기 / 웅크리기 / 누운 자세를 가능한 만큼.
3. 런타임 종료. 포트가 비었는지 확인.
4. Candidate A 기동 → 같은 조건 반복.
5. 런타임 종료.
6. Candidate B 기동 → 같은 조건 반복.

볼 것 (짧게):

- 헤더 Thermal 모델이 방금 켠 것과 일치하는가
- UDP thermal frames `Δ`가 증가하는가
- thermal sensor `LIVE`
- Thermal AI 상태 (`WARMUP` / 클래스 / `FALL_PX`)
- `HUMAN_NORMAL` → `HUMAN_FALL_PROXY` 전환이 수상하면 기록만. 실제 낙상으로 쓰지 말 것
- latency가 보이면 참고
- risk는 bounded proxy 유지
- LCD state

환경이 비슷할수록 비교가 쉽다. 기기 도메인 최종 검증은 아니다.

---

## 7. 중지 / 재시작 / 모델 변경

핫 스위칭 없음. 반드시 종료 후 다른 선택으로 다시 기동.

```bash
cd /home/sandi/safenest-team-main

# LCD Chromium (백엔드와 별개)
pkill -f "chromium.*8000/display" 2>/dev/null || true

# 백엔드
kill "$(cat .runtime.pid)" 2>/dev/null || true
pkill -f "backend/run_backend.py" || true

ss -ltnp | grep -E ":8000|:9000" || echo "tcp free"
ss -lunp | grep 5005 || echo "udp free"
```

그다음 2절에서 다른 모델을 기동한다.

---

## 8. 포트 / URL

| 포트 | 용도 |
|---|---|
| TCP `:8000` | FastAPI / Web / LCD `/display` / admin |
| TCP `:9000` | ESP 스칼라 텔레메트리 (mmWave / CO₂ / PIR) |
| UDP `:5005` | ESP 열화상 프레임 |

| 경로 | 용도 |
|---|---|
| `http://<PI_IP>:8000/display` | LCD |
| `http://<PI_IP>:8000/admin` | 관리 |
| `http://<PI_IP>:8000/dashboard` | 대시보드 |
| `http://<PI_IP>:8000/health` | liveness |
| `http://<PI_IP>:8000/api/status` | 센서·AI·risk·Thermal `runtime_status` |
| `http://<PI_IP>:8000/api/state` | LCD 상태 |

---

## 9. 로그 확인

| 파일 | 언제 |
|---|---|
| `logs/runtime.log` | `./run_safenest.sh` 백그라운드 |
| `logs/runtime-thermal-baseline.log` | 비교 런처 baseline 백그라운드 |
| `logs/runtime-thermal-a.log` | Candidate A 백그라운드 |
| `logs/runtime-thermal-b.log` | Candidate B 백그라운드 |
| `/tmp/chromium-display.log` | LCD Chromium |

```bash
tail -f logs/runtime-thermal-a.log
```

기동 직후 아래가 보여야 한다 (백엔드 `ai/runtime.py`):

```text
[SafeNest Thermal]
THERMAL SELECTOR: …
MODEL ID: …
MODEL SHA: …
PREPROCESSING: …
CONTROLLED TEST MODE: 0 또는 1
```

비교 런처는 추가로:

```text
[SafeNest Thermal Test]
choice: a
selector: thermal_tv2_candidate_a_a0_fp32_v1
```

---

## 10. 문제 발생 시 빠른 점검

| 증상 | 볼 것 |
|---|---|
| `:8000` 안 열림 | `pgrep -af run_backend.py`, `ss -ltnp \| grep 8000`, 로그 `tail` |
| `/display` → 404 | 현재 `main`이면 `app.py`에 라우트가 있어야 함. 옛 클론/옛 프로세스가 `:8000`을 잡고 있지 않은지 |
| `/display` 200인데 LCD 검정 | Chromium `DISPLAY=:0`인지, 옛 Chromium이 다른 페이지를 띄웠는지, `/tmp/chromium-display.log` |
| Chromium 프로세스만 있고 화면 없음 | 잘못된 `DISPLAY`, `XDG_RUNTIME_DIR=/run/user/1000`, `XAUTHORITY` |
| 모니터 헤더가 기대한 모델이 아님 | 이전 프로세스가 안 죽었거나, 다른 클론을 기동함. 종료 후 다시 |
| selector는 맞는데 Thermal AI가 BLOCKED | 정상일 수 있음 (UDP 없음 / STALE / WARMUP). 선택과 추론을 분리해서 볼 것 |
| 모델을 바꿨는데 화면이 그대로 | 핫 스위칭 없음. 종료 확인 후 재기동 |

---

## 11. 모델 의미 / 제한사항

| 선택 | selector | 오프라인 상태 | 전처리 |
|---|---|---|---|
| Team 기본 / 비교 baseline | `thermal_public_sdt_fp32_active` | 현재 런타임 기본 | 프레임 min-max (`PUBLIC_SDT_BILINEAR_62X80_FRAME_MINMAX_V1`) |
| A | `thermal_tv2_candidate_a_a0_fp32_v1` | A_PREFERRED, CONTROLLED_TEAM_TEST, 기본값 아님 | `FRAME_ROBUST_P2_P98_V1` |
| B | `thermal_tv2_candidate_b_seed42_fp32_test_v1` | B_NOT_COMPETITIVE, CONTROLLED_COMPARISON_ONLY | 같은 robust 전처리 |

A/B는 프레임 안 2%/98% percentile로 상대 명암을 정규화한다. baseline과 입력이 다르다. 선택기가 모델과 전처리 경로를 같이 고른다.

입력 geometry는 `TEAM_RUNTIME_62X80_AS_RECEIVED_EXPERIMENTAL_BRIDGE`다. 기기/소스 geometry 검증은 아직이다.

공통:

- `HUMAN_FALL_PROXY` = 정적 누운/자세 프록시. **실제 낙상 확정이 아니다.**
- 임상 검증 아님. 기기 도메인 검증 아님. production 승인 아님.
- risk 공식·임계값·CO₂·mmWave는 그대로다. Thermal은 bounded proxy만.
- Candidate A가 오프라인에서 낫다고 해서 Team default가 바뀐 것이 아니다.
- Candidate B는 비교 전용이다. 선호 모델이 아니다.

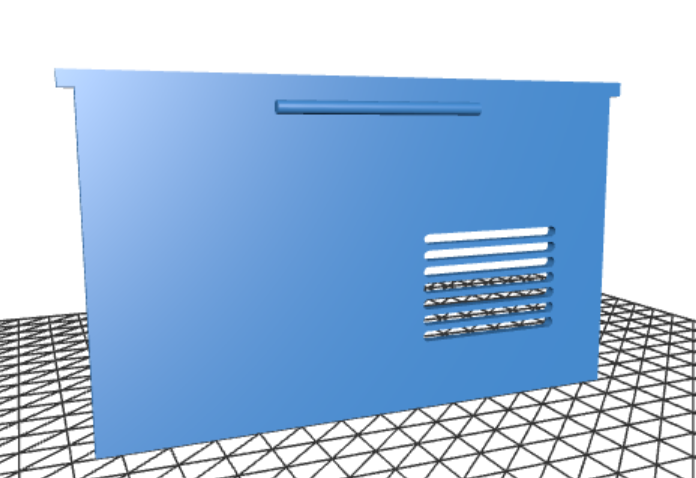
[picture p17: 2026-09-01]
final-report/assets/3d_sensor_housing_sliding_back.png

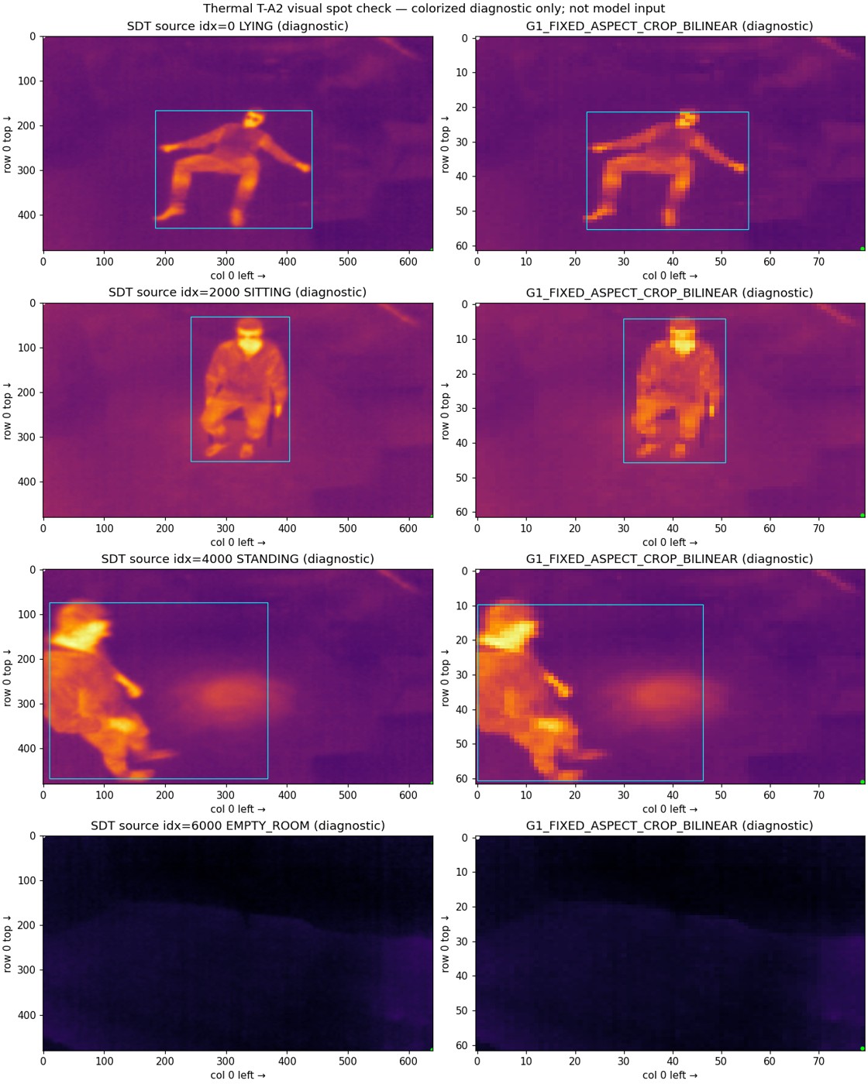
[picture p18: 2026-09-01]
final-report/assets/thermal_spotcheck.jpg

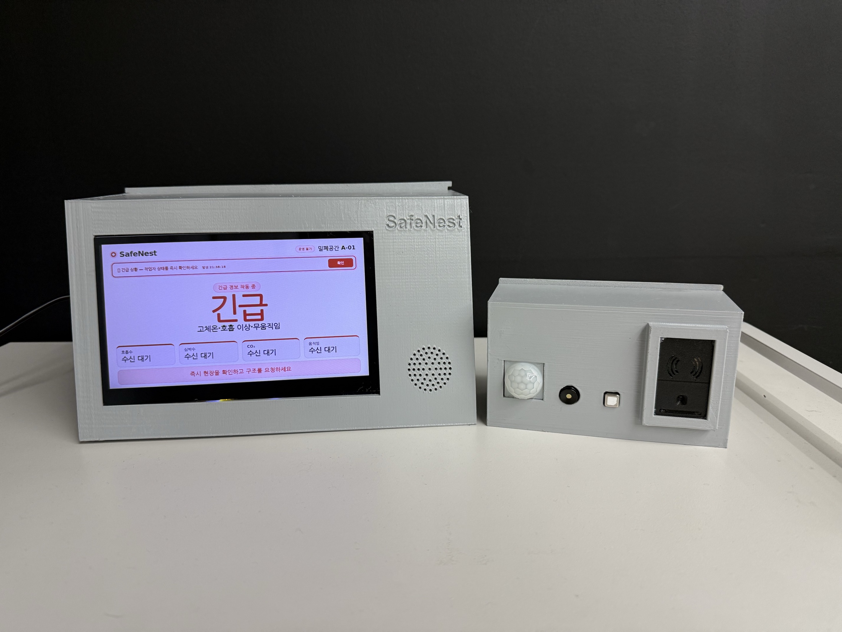
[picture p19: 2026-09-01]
final-report/assets/hw_product_full_emergency.jpg

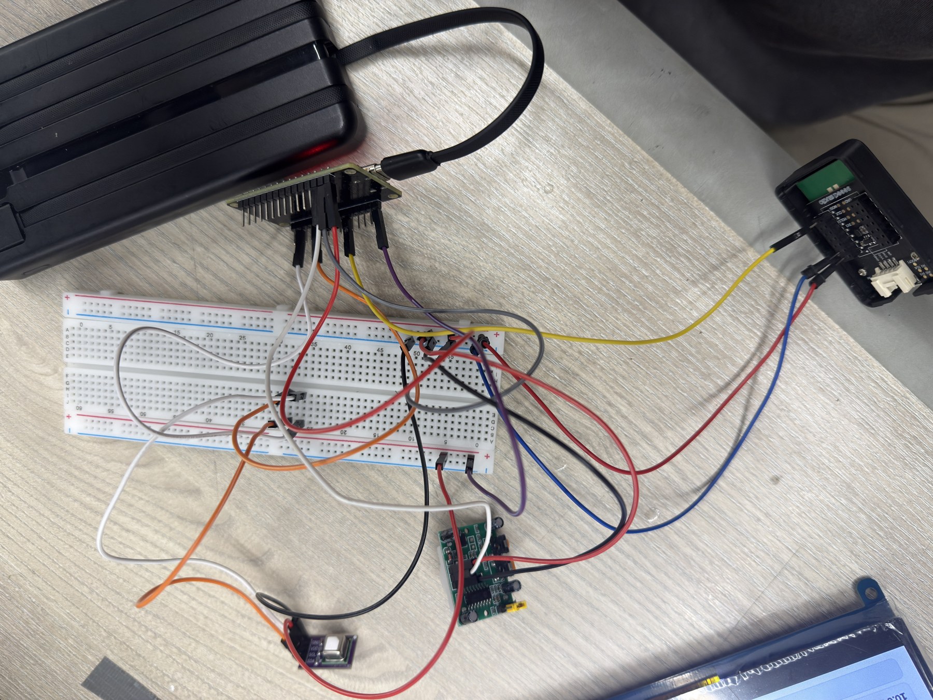
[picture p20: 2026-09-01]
final-report/assets/hw_bench.jpg

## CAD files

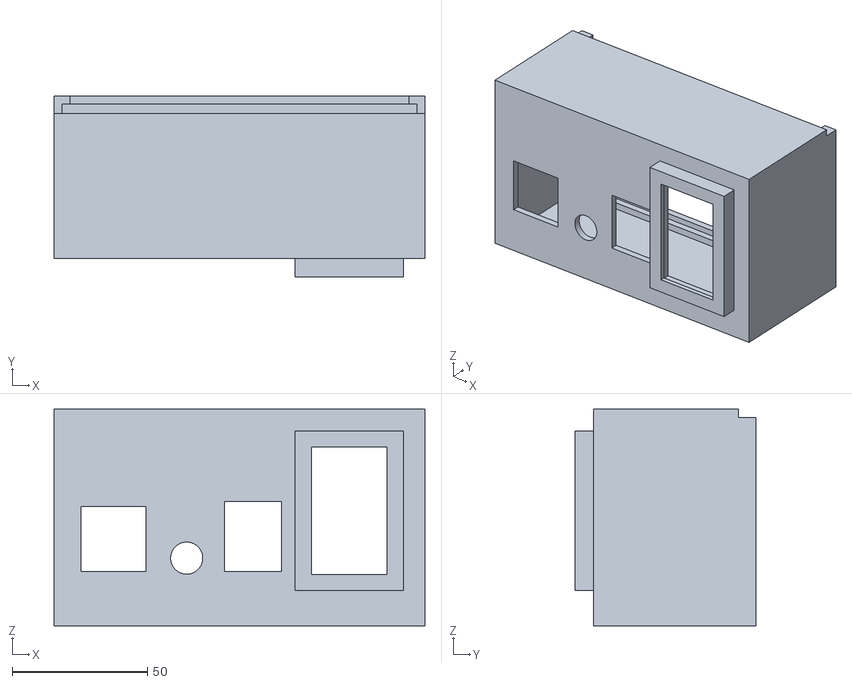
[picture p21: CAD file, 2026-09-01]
hardware/3d_models/housing_body.stl
137.0 x 67.0 x 80.0

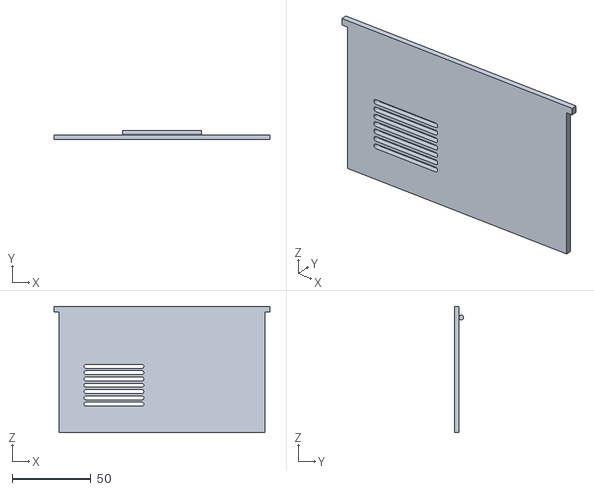
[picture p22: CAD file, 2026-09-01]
hardware/3d_models/sliding_back_panel.stl
137.0 x 5.90 x 80.0

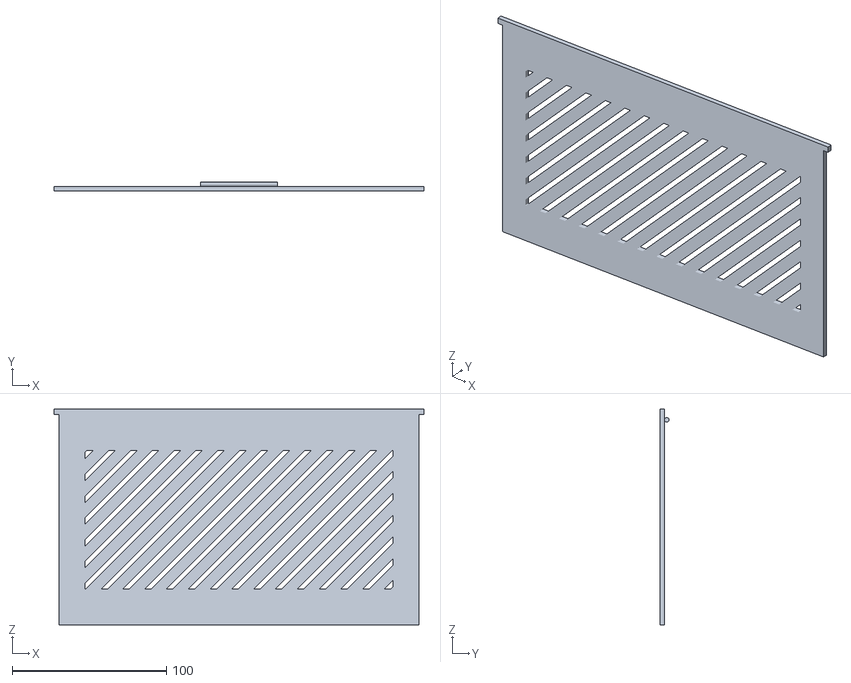
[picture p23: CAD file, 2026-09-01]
hardware/3d_models/trapezoid_T_back_panel.stl
240.0 x 5.90 x 140.0

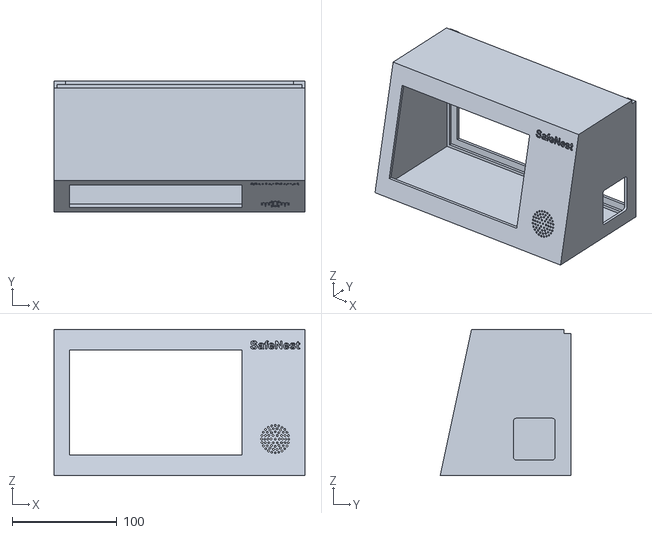
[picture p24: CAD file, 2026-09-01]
hardware/3d_models/trapezoid_housing_body.stl
240.0 x 125.0 x 140.0

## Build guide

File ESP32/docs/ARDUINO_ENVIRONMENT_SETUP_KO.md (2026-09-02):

# SafeNest ESP32 Arduino 개발 환경 구축 가이드

이 문서는 다른 PC에서도 SafeNest ESP32 통합 센서 펌웨어를 빌드하고 ESP32에 업로드할 수 있도록 필요한 프로그램, 보드 패키지, Arduino 라이브러리, 설정 파일과 실행 절차를 정리한 문서입니다.

대상 스케치:

```text
ESP32/Arduino/esp32_sensor_node/esp32_sensor_node.ino
```

이 스케치가 실제 ESP32에 올라가는 **정본(canonical) 펌웨어**입니다. 저장소에는 이 스케치 하나만 있습니다.

> 이 프로젝트의 기준 보드는 일반적인 ESP32-WROOM 계열의 `ESP32 Dev Module`입니다. XIAO ESP32C6용 보드 설정이 아닙니다. 소스의 핀 번호도 `ESP32 Dev Module` 기준이므로 다른 보드로 바꾸면 배선과 핀 정의를 함께 수정해야 합니다.

CO₂는 Sensirion SCD4x가 아니라 **Winsen MH-Z19B UART**를 사용합니다. 따라서 SCD4x 라이브러리가 필요 없습니다. MR60은 UART2(GPIO 16/17), MH-Z19B는 UART1(GPIO 32/33)을 씁니다. MH-Z19B 모듈 전원은 4.5–5.5 V이며 ESP32 3.3 V 레일로 켜지 않습니다. 변경 이력과 배선 상세는 `ESP32/Arduino/esp32_sensor_node/ESP32.md`를 봅니다.

## 1. 준비물

- ESP32 Dev Module(ESP32-WROOM 계열)
- 데이터 통신이 가능한 USB 케이블
- MR60BHA2 60 GHz mmWave 센서
- Winsen MH-Z19B NDIR CO₂ 센서 (별도 4.5–5.5 V 전원 필요)
- PIR 센서
- Waveshare Thermal Camera HAT / MI48xx(80 × 62) 열화상 센서
- Raspberry Pi와 ESP32가 함께 접속할 수 있는 **2.4 GHz Wi-Fi**
- Windows, macOS 또는 Linux PC

ESP32는 저속 센서 데이터를 Raspberry Pi의 TCP `9000` 포트로, 열화상 데이터를 UDP `5005` 포트로 전송합니다. 펌웨어만 단독으로 업로드할 수는 있지만 전체 시스템 동작을 확인하려면 Raspberry Pi 수신 프로그램이 먼저 실행 중이어야 합니다.

## 2. 설치해야 하는 프로그램과 패키지

### 2.1 Arduino IDE

[Arduino IDE 공식 다운로드](https://www.arduino.cc/en/software/)에서 Arduino IDE 2.x의 최신 안정 버전을 설치합니다.

CLI 기반 설치를 원하는 경우에는 [Arduino CLI](https://arduino.github.io/arduino-cli/latest/installation/)를 대신 사용할 수 있습니다. GUI 절차는 3절, CLI 절차는 8절을 따릅니다.

### 2.2 ESP32 보드 패키지

Arduino IDE에서 다음 보드 매니저 URL을 등록합니다.

```text
https://espressif.github.io/arduino-esp32/package_esp32_index.json
```

설치 대상:

| 구분 | 설치/선택 항목 | 비고 |
|---|---|---|
| 보드 패키지 | `esp32` by Espressif Systems | 안정 버전 사용 |
| 보드 | `ESP32 Dev Module` | Arduino FQBN: `esp32:esp32:esp32` |
| 시리얼 속도 | `115200` baud | 업로드 후 Serial Monitor 설정 |

설치 순서:

1. Arduino IDE에서 `File > Preferences`를 엽니다.
2. `Additional boards manager URLs`에 위 URL을 추가합니다.
3. `Tools > Board > Boards Manager`를 엽니다.
4. `esp32`를 검색하고 **Espressif Systems**가 제공하는 패키지를 설치합니다.
5. `Tools > Board > esp32 > ESP32 Dev Module`을 선택합니다.

이 스케치에서 사용하는 `Arduino.h`, `WiFi.h`, `WiFiUdp.h`, `Wire.h`, `SPI.h`, FreeRTOS API는 ESP32 보드 패키지에 포함되므로 별도 라이브러리로 설치하지 않습니다.

### 2.3 외부 Arduino 라이브러리

정본 스케치의 직접 외부 의존성은 하나입니다. CO₂는 MH-Z19B UART를 스케치 안에서 직접 처리하므로 별도 라이브러리가 없습니다.

| Library Manager 검색 이름 | 제공자 | 필요한 헤더 | 권장 버전/주의 사항 |
|---|---|---|---|
| `Seeed Arduino mmWave` | Seeed Studio | `Seeed_Arduino_mmWave.h` | 검증 기준 안정 계열 `1.0.0`; MR60BHA2 지원 필요 |

함께 설치되는 의존성:

| 상위 라이브러리 | 하위 의존성 | 처리 방법 |
|---|---|---|
| Seeed Arduino mmWave | `Adafruit NeoPixel`, `hp_BH1750` | 설치 창에서 `Install all` 선택 |

Arduino IDE에서 설치하는 방법:

1. 왼쪽의 `Library Manager` 아이콘을 누르거나 `Sketch > Include Library > Manage Libraries...`를 엽니다.
2. `Seeed Arduino mmWave`를 검색해 Seeed Studio 제공 라이브러리를 설치합니다.
3. 의존성 설치 여부를 물으면 `Install all`을 선택합니다.
4. 설치가 끝나면 Arduino IDE를 한 번 재시작합니다.

Seeed 라이브러리가 Library Manager에서 검색되지 않으면 [Seeed mmWave 공식 저장소](https://github.com/Seeed-Projects/Seeed-mmWave-library)의 안정 릴리스 ZIP을 내려받아 `Sketch > Include Library > Add .ZIP Library...`로 설치합니다. ZIP으로 수동 설치할 때는 위 표의 하위 의존성도 Library Manager에서 따로 설치합니다. 프리릴리스나 개발 브랜치는 API 호환성을 다시 확인하기 전까지 사용하지 않는 것이 안전합니다.

## 3. 프로젝트 받기

Git을 사용하는 방법:

```bash
git clone https://github.com/jinsu1011/safenest-embedded-competition-bridege.git
cd safenest-embedded-competition
```

Git을 사용하지 않으면 GitHub의 `Code > Download ZIP`으로 받은 뒤 압축을 풉니다. `.ino` 파일 하나만 전달하지 말고 최소한 다음 구조를 유지해야 합니다.

```text
<repository>/
└── ESP32/
    └── Arduino/
        └── esp32_sensor_node/
            ├── esp32_sensor_node.ino
            ├── secrets.example.h
            └── secrets.h            # 사용자가 생성, Git에 올리지 않음
```

Arduino 스케치 폴더 이름과 `.ino` 파일의 기본 이름은 모두 `esp32_sensor_node`로 같아야 합니다.

## 4. 개인 설정 파일 만들기

Wi-Fi 비밀번호 같은 개인정보는 소스에 직접 적지 않고 스케치 폴더의 `secrets.h`에 둡니다. 이 파일은 `.gitignore`에 등록되어 Git에 커밋되지 않습니다.

Windows PowerShell:

```powershell
Copy-Item .\ESP32\Arduino\esp32_sensor_node\secrets.example.h .\ESP32\Arduino\esp32_sensor_node\secrets.h
```

macOS/Linux:

```bash
cp ESP32/Arduino/esp32_sensor_node/secrets.example.h ESP32/Arduino/esp32_sensor_node/secrets.h
```

생성한 `secrets.h`를 다음과 같이 수정합니다.

```cpp
#pragma once

constexpr char WIFI_SSID[] = "2.4_GHz_Wi-Fi_이름";
constexpr char WIFI_PASSWORD[] = "Wi-Fi_비밀번호";
constexpr char RPI_HOST[] = "192.168.1.44";  // Raspberry Pi의 실제 IPv4 주소
constexpr uint16_t RPI_PORT = 9000;
```

주의 사항:

- ESP32는 이 구성에서 2.4 GHz Wi-Fi를 사용합니다.
- `RPI_HOST`에는 `localhost`가 아니라 ESP32에서 접근할 수 있는 Raspberry Pi의 LAN IPv4 주소를 넣습니다.
- `RPI_PORT`는 Raspberry Pi 수신 서버의 TCP 포트 `9000`과 같아야 합니다.
- 열화상 UDP 포트 `5005`는 현재 `.ino`의 `THERMAL_UDP_PORT`에 정의되어 있습니다.
- 실제 `secrets.h`를 메신저, 문서 또는 Git으로 공유하지 마십시오. 다른 사용자는 예제 파일에서 자신의 값을 만들어야 합니다.

## 5. 배선 확인

현재 스케치에 고정된 ESP32 핀은 다음과 같습니다.

| 장치/신호 | ESP32 핀 | 연결 방향 또는 설명 |
|---|---:|---|
| 공통 I²C SDA | GPIO 21 | Thermal 제어 버스 |
| 공통 I²C SCL | GPIO 22 | Thermal 제어 버스 |
| PIR OUT | GPIO 13 | ESP32 디지털 입력 |
| MH-Z19B TX | GPIO 32 | 센서 TX → ESP32 RX (UART1) |
| MH-Z19B RX | GPIO 33 | 센서 RX ← ESP32 TX (UART1) |
| MR60BHA2 TX | GPIO 16 | 센서 TX → ESP32 RX |
| MR60BHA2 RX | GPIO 17 | 센서 RX ← ESP32 TX |
| Thermal SCLK | GPIO 18 | SPI clock |
| Thermal MISO | GPIO 19 | 센서 → ESP32 |
| Thermal MOSI | GPIO 23 | ESP32 → 센서 |
| Thermal CS | GPIO 27 | SPI chip select |
| Thermal READY | GPIO 26 | ESP32 입력 |
| Thermal RESET | GPIO 25 | ESP32 출력 |

모든 모듈과 ESP32의 GND를 공통으로 연결합니다. 센서 전원 전압과 핀 허용 전압은 반드시 각 센서의 데이터시트 및 사용 중인 모듈 보드 사양을 확인하십시오. 상세 통신 규약은 [COMMUNICATION_PROTOCOL.md](./COMMUNICATION_PROTOCOL.md)를 참고합니다.

## 6. 컴파일 및 업로드

1. Arduino IDE에서 `ESP32/Arduino/esp32_sensor_node/esp32_sensor_node.ino`를 엽니다.
2. `Tools > Board`에서 `ESP32 Dev Module`을 선택합니다.
3. `Tools > Port`에서 ESP32가 연결된 포트를 선택합니다.
4. 먼저 `Sketch > Verify/Compile`로 컴파일합니다.
5. 오류가 없으면 `Upload`를 눌러 플래시합니다.
6. 업로드 후 `Tools > Serial Monitor`를 열고 `115200 baud`를 선택합니다.

ESP32가 포트 목록에 나타나지 않으면 다음을 확인합니다.

- 충전 전용이 아닌 데이터 USB 케이블인지 확인
- 다른 USB 포트 사용
- 보드에 장착된 USB-UART 칩에 따라 CP210x 또는 CH340 드라이버 설치
- Windows 장치 관리자 또는 macOS/Linux의 직렬 장치 목록에서 포트 확인
- 업로드 연결 중 필요하면 보드의 `BOOT` 버튼을 누른 상태에서 업로드 시작

## 7. 정상 동작 확인

업로드 직후 Serial Monitor에서 다음 흐름을 확인합니다.

```text
SafeNest ESP32 sensor node starting
[identity] device=esp32-01 ...
[wifi] connecting to ... asynchronously
```

이후 10초마다 출력되는 `[health]` 로그에서 다음 항목을 확인합니다.

| 항목 | 정상 예시 | 의미 |
|---|---|---|
| `wifi` | `up` | Wi-Fi 연결 성공 |
| `rpi` | 설정한 Raspberry Pi IP | 전송 목적지 |
| `co2` | 0이 아닌 측정값 | MH-Z19B 측정 수신 |
| `resp`, `heart` | 사람이 감지될 때 값 출력 | MR60BHA2 데이터 수신 |
| `thermal_frames` | 계속 증가 | 열화상 프레임 캡처 진행 |
| `udp_sent` | 계속 증가 | Raspberry Pi로 UDP 전송 진행 |
| `udp_failed` | 지속 증가하지 않음 | UDP 전송 오류 여부 |

Raspberry Pi 쪽에서도 TCP `9000`과 UDP `5005`가 수신 대기 중이어야 합니다. PC 또는 Raspberry Pi 방화벽이 이 통신을 막지 않는지 확인합니다.

## 8. 선택 사항: Arduino CLI로 동일 환경 만들기

다음 명령은 Arduino CLI가 설치되어 있고 터미널에서 `arduino-cli`를 실행할 수 있다는 전제입니다.

```bash
arduino-cli config init
arduino-cli config add board_manager.additional_urls https://espressif.github.io/arduino-esp32/package_esp32_index.json
arduino-cli core update-index
arduino-cli core install esp32:esp32
arduino-cli lib install "Seeed Arduino mmWave"
```

컴파일:

```bash
arduino-cli compile --fqbn esp32:esp32:esp32 ESP32/Arduino/esp32_sensor_node
```

업로드 예시:

```bash
arduino-cli upload --fqbn esp32:esp32:esp32 --port COM5 ESP32/Arduino/esp32_sensor_node
```

macOS/Linux에서는 `COM5` 대신 실제 포트(예: `/dev/cu.usbserial-...`, `/dev/ttyUSB0`)를 넣습니다. 포트는 다음 명령으로 확인할 수 있습니다.

```bash
arduino-cli board list
```

## 9. 재현성을 위한 버전 기록

모든 팀원이 완전히 같은 결과를 얻어야 한다면 “최신 버전”만 사용하지 말고, 최초로 정상 컴파일·실기 동작을 확인한 뒤 아래 버전을 기록해 공유합니다.

```bash
arduino-cli version
arduino-cli core list
arduino-cli lib list
```

권장 기록표:

| 구성 요소 | 프로젝트 요구 조건 | 팀 검증 버전 기입란 |
|---|---|---|
| Arduino IDE 또는 CLI | IDE 2.x 또는 호환 CLI | `____________` |
| ESP32 by Espressif Systems | 안정 버전, `ESP32 Dev Module` 지원 | `____________` |
| Seeed Arduino mmWave | 안정 계열 `1.0.0` | `____________` |
| Adafruit NeoPixel | Seeed 라이브러리가 요구하는 버전 | `____________` |
| hp_BH1750 | Seeed 라이브러리가 요구하는 버전 | `____________` |

버전을 고정한 CLI 설치 예시는 다음 형식입니다.

```bash
arduino-cli core install esp32:esp32@<검증한_버전>
arduino-cli lib install "Seeed Arduino mmWave@1.0.0"
```

## 10. 자주 발생하는 오류

| 오류/증상 | 원인 | 해결 방법 |
|---|---|---|
| `Seeed_Arduino_mmWave.h: No such file or directory` | 다른 24 GHz radar 라이브러리를 설치했거나 라이브러리 누락 | 정확히 `Seeed Arduino mmWave` 설치 |
| `secrets.h: No such file or directory` | 개인 설정 파일 미생성 | 4절의 명령으로 예제 파일을 복사 |
| 여러 라이브러리가 발견되었다는 메시지 | 이름이 비슷한 구형/복제 라이브러리가 함께 설치됨 | Arduino libraries 폴더에서 중복을 제거하고 정확한 제공자 버전만 유지 |
| 포트가 보이지 않음 | USB 케이블 또는 USB-UART 드라이버 문제 | 데이터 케이블, CP210x/CH340 드라이버, 다른 USB 포트 확인 |
| 업로드 중 연결 실패 | 자동 부트 진입 실패 또는 포트 점유 | Serial Monitor를 닫고 재시도, 필요하면 `BOOT` 버튼 사용 |
| Wi-Fi 연결 실패 | 5 GHz 전용 SSID, 잘못된 비밀번호 | 2.4 GHz SSID와 `secrets.h` 재확인 |
| `wifi=up`인데 Pi에 데이터가 없음 | Pi IP/포트/방화벽 또는 수신 서버 문제 | `RPI_HOST`, TCP 9000, UDP 5005, Pi 실행 상태와 방화벽 확인 |
| 센서 값만 비어 있음 | 배선, 전원, RX/TX 방향 또는 센서 펌웨어 문제 | 5절 배선과 공통 GND 확인; MR60BHA2는 필요 시 공식 안내에 따라 펌웨어 확인 |

## 11. 다른 사람에게 전달할 때 체크리스트

- [ ] 저장소 전체 또는 최소 ESP32 폴더 구조를 전달했다.
- [ ] 실제 `secrets.h`가 아니라 `secrets.example.h`만 전달했다.
- [ ] 사용 보드가 `ESP32 Dev Module`임을 알렸다.
- [ ] ESP32 보드 패키지와 `Seeed Arduino mmWave` 라이브러리의 설치를 안내했다.
- [ ] 라이브러리 설치 시 `Install all`로 하위 의존성을 설치했다.
- [ ] 검증에 사용한 IDE, ESP32 core, 라이브러리 버전을 기록했다.
- [ ] 2.4 GHz Wi-Fi 및 Raspberry Pi IP를 각 사용자 환경에 맞게 설정했다.
- [ ] TCP 9000, UDP 5005 포트와 방화벽을 확인했다.
- [ ] 업로드 후 Serial Monitor를 `115200 baud`로 확인했다.

## 공식 참고 자료

- [Espressif Arduino-ESP32 설치 문서](https://docs.espressif.com/projects/arduino-esp32/en/latest/installing.html)
- [Seeed Arduino mmWave 라이브러리](https://github.com/Seeed-Projects/Seeed-mmWave-library)
- [Seeed MR60BHA2 시작 가이드](https://wiki.seeedstudio.com/getting_started_with_mr60bha2_mmwave_kit/)
- [SafeNest ESP32 통신 규약](./COMMUNICATION_PROTOCOL.md)

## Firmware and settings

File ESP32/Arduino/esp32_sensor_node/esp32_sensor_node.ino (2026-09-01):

/*
 * SafeNest ESP32 sensor node
 *
 * Sensors:
 *   - Seeed MR60BHA2 (UART2 GPIO 16/17): respiration and heart rate
 *   - Winsen MH-Z19B (UART1 GPIO 32/33): CO2
 *   - PIR (digital input): motion
 *   - Waveshare Thermal Camera HAT / MI48xx (I2C control + SPI data): 80 x 62
 *
 * Transport:
 *   - TCP for low-rate mmWave/CO2/PIR JSON telemetry
 *   - Chunked UDP for big-endian uint16 Thermal frames
 *
 * The Arduino loop never calls delay(). Sensor scheduling uses millis().
 * TCP reconnect/writes and Thermal UDP writes run in separate FreeRTOS tasks.
 * If the network is slow, the one-slot thermal queue keeps only the newest frame.
 *
 * MH-Z19B power: Vin 4.5-5.5 V, peak 150 mA. Do not power from the ESP32 3.3 V
 * rail. UART is 9600 8N1 TTL 3.3 V with TX/RX crossed on UART1 (GPIO 32/33).
 * Never share UART2 (GPIO 16/17) with the MR60.
 */

#include <Arduino.h>
#include <esp_system.h>
#include <freertos/event_groups.h>
#include <freertos/semphr.h>
#include <WiFi.h>
#include <WiFiUdp.h>
#include <Wire.h>
#include <SPI.h>
#include <errno.h>
#include <lwip/sockets.h>
#include "Seeed_Arduino_mmWave.h"
#include "secrets.h"

// -----------------------------------------------------------------------------
// Device identity. Wi-Fi and Raspberry Pi settings live in ignored secrets.h.
// ----------------------------------------------------------------------------
constexpr char DEVICE_ID[] = "esp32-01";
char bootId[33] = {};
constexpr uint16_t THERMAL_UDP_PORT = 5005;

// -----------------------------------------------------------------------------
// ESP32 Dev Module wiring. MH-Z19B is on UART1; MR60 stays on UART2.
// ----------------------------------------------------------------------------
constexpr int PIN_I2C_SDA = 21;
constexpr int PIN_I2C_SCL = 22;
constexpr int PIN_PIR = 13;
constexpr int PIN_MMWAVE_RX = 16;  // ESP32 RX <- MR60BHA2 TX
constexpr int PIN_MMWAVE_TX = 17;  // ESP32 TX -> MR60BHA2 RX
// UART1 for MH-Z19B. Never share UART2 (16/17) with the MR60.
// GPIO 32/33 are free after the v2 pin map (I2C 21/22, PIR 13, thermal
// SPI/I2C 18/19/23/27/26/25). They are not flash/strapping pins on WROOM.
constexpr int PIN_MHZ19_RX = 32;  // ESP32 RX <- MH-Z19B TX
constexpr int PIN_MHZ19_TX = 33;  // ESP32 TX -> MH-Z19B RX

constexpr int PIN_THERMAL_SCLK = 18;
constexpr int PIN_THERMAL_MISO = 19;
constexpr int PIN_THERMAL_MOSI = 23;
constexpr int PIN_THERMAL_CS = 27;
constexpr int PIN_THERMAL_READY = 26;
constexpr int PIN_THERMAL_RESET = 25;

constexpr uint32_t USB_BAUD = 115200;
constexpr uint32_t MMWAVE_BAUD = 115200;
constexpr uint32_t MHZ19_BAUD = 9600;
constexpr uint32_t THERMAL_SPI_HZ = 8000000;

// Runtime schedules.
// MH-Z19B command 0x86 has no Sensirion-style getDataReadyStatus. Winsen
// manuals (v1.7, 2020-10-15) do not prove each UART read is a new NDIR
// conversion. This node therefore infers producer identity:
//   - at most one accepted UART sample per CO2_UART_SAMPLE_PERIOD_MS
//   - event identity class INFERRED_UART_SAMPLE (not SCD40 conversion)
// 5000 ms matches the SCD4x ~5 s cadence this v2 node used to expose and
// is slower than the ~1 s PWM encoding period. It is NOT a claim that the
// optical cell converts at this rate.
constexpr uint32_t PIR_PERIOD_MS = 20;
constexpr uint32_t CO2_UART_SAMPLE_PERIOD_MS = 5000;
constexpr uint32_t CO2_UART_RESPONSE_TIMEOUT_MS = 200;
constexpr uint32_t CO2_PREHEAT_MS = 180000;  // Winsen: 3 min
constexpr uint16_t CO2_PPM_MAX_ACCEPTED = 10000;
// 10 Hz matches the 1.3.0 phase contract. PHASE_MAX_AGE_MS is 500, so a 1 Hz
// snapshot would publish breath_phase as null on almost every packet and the
// Pi 300-sample window would never fill. LCD can ignore the extra packets.
// TCP writes remain isolated in their own task.
constexpr uint32_t TELEMETRY_PERIOD_MS = 100;
constexpr uint32_t HEALTH_LOG_PERIOD_MS = 10000;
// If MI48 is unpowered or hung off I2C, a probe-first init never pulses
// GPIO25. Recovery always resets then probes. Serial 't' is debug-only.
constexpr uint32_t THERMAL_RECOVER_PERIOD_MS = 2000;
constexpr uint32_t THERMAL_STALE_REINIT_MS = 7000;
constexpr uint32_t THERMAL_I2C_MISS_LOG_MS = 10000;
constexpr uint32_t MMWAVE_STALE_MS = 10000;
constexpr uint32_t CO2_STALE_MS = 15000;
constexpr uint32_t PHASE_MAX_AGE_MS = 500;
// The MR60 reports 0x0F09 occupancy on its own cadence, independent of the
// respiration/heart-rate stream. This bound only has to outlive normal report
// gaps; once it lapses the field goes null (unknown), which suppresses mmWave
// inference rather than asserting an empty room.
constexpr uint32_t PRESENCE_MAX_AGE_MS = 5000;
constexpr char NODE_FIRMWARE_VERSION[] =
    "safenest-esp32-sensor-node/1.7.10-mhz19b.1";
constexpr char DIAGNOSTIC_BUILD_ID[] =
    "mhz19b-thermal-reinit-20260901-09";
constexpr char MMWAVE_SCHEMA_VERSION[] = "1.3";
constexpr char CO2_SENSOR_MODEL[] = "MH-Z19B";
constexpr char CO2_EVENT_IDENTITY_CLASS[] = "INFERRED_UART_SAMPLE";

// -----------------------------------------------------------------------------
// Link diagnostics.
//
// A "disconnect" on this link is really a missed receive deadline on the Pi.
// Both receivers close the socket themselves when one packet does not arrive
// in time, and neither waits as long as this node is willing to stall:
//
//   RaspberryPi/LCD/server.py             connection.settimeout(2.0). Its
//                                         header recv is wrapped in
//                                         `except socket.timeout: continue`,
//                                         but the payload recv is not, so one
//                                         2 s gap between the 16-byte header
//                                         and the JSON body raises
//                                         socket.timeout -- an OSError, which
//                                         its handler treats as fatal.
//   RaspberryPi/Runtime/gateway/          5 s total deadline per field.
//     receiver.py
//
// Arduino-ESP32 3.x NetworkClient::write() is not bounded by writeAll()'s
// old 5000 ms stall timer. It select()-waits WIFI_CLIENT_SELECT_TIMEOUT_US
// (1 s) up to WIFI_CLIENT_MAX_WRITE_RETRY (10) times, so one client.write()
// can sit in the TX mutex for ~10000 ms. Field logs of write_max_ms=10012
// with stall_ms=0/zero_writes=0 are that path: the wait happens inside
// write(), so the application timer never starts. The Pi LCD receiver has
// already closed (2 s) long before that returns, which is why peer_closed,
// tcp_errno=104 (ECONNRESET) and connect_ms≈1500 follow.
//
// writeAll() therefore calls lwip_send(MSG_DONTWAIT) itself. An 800 ms retry
// loop on EAGAIN was still long enough to desynchronize the Pi: a partial
// SNST prefix (field wrote=97/808) forces this node to close, then
// reconnect SYN storms fill the TX queue even with thermal UDP off. Skip
// before any byte is on the wire; only a started packet uses the finish
// deadline.
// ----------------------------------------------------------------------------
constexpr uint32_t PI_PACKET_DEADLINE_MS = 2000;
// Warn below the Pi deadline so the log shows the approach, not only the crash.
constexpr uint32_t TELEMETRY_GAP_WARN_MS = 1500;
constexpr uint32_t TCP_WRITE_WARN_MS = 150;
// No byte sent yet: abandon this snapshot and keep the socket.
constexpr uint32_t TCP_WRITE_SKIP_MS = 40;
// Some bytes already on the wire: finish or close (partial SNST is fatal).
constexpr uint32_t TCP_WRITE_DEADLINE_MS = 200;
constexpr uint32_t TCP_CONNECT_TIMEOUT_MS = 4000;
// After a partial-write close, wait before SYN. 300 ms was still fast enough
// to pile SYN-RECV on a weak AP uplink (errno 119 / connect_ms=1503).
constexpr uint32_t TCP_RECONNECT_DELAY_MS = 2000;
constexpr uint32_t TCP_CONNECT_FAIL_DELAY_MS = 2500;
constexpr uint8_t TCP_CONNECT_FAILS_BEFORE_REASSOC = 5;
constexpr uint32_t SERIAL_ERROR_LOG_PERIOD_MS = 1000;
constexpr uint32_t TCP_MUTEX_WARN_MS = 100;
// UDP sendto is O_NONBLOCK, so the mutex should be held for milliseconds.
// 250 ms turns a stuck datagram into a counted timeout instead of a 3 s
// invisible wait that itself misses the Pi deadline.
constexpr uint32_t TCP_MUTEX_MAX_WAIT_MS = 250;
constexpr uint32_t UDP_DATAGRAM_WARN_MS = 40;
// 2 ms between chunks was only a CPU yield. Nine 1200-byte datagrams still
// hit the radio in ~34 ms, which is what filled the lwIP pool (errno 12) and
// left no airtime for the 1 Hz TCP write. 20 ms is long enough for the TCP
// task to wake, take the mutex, and finish a ~3 ms write, and 8 gaps stay
// inside the ~1000 ms 1 fps period and the Pi's 500 ms thermal reassembly
// window (measured from the last chunk, not the first).
constexpr uint32_t UDP_CHUNK_GAP_MS = 20;
// A live telemetry write holds TCP_CRITICAL_BIT for a few milliseconds.
// Waiting this out and then continuing the same frame is the interleave;
// returning Preempted used to drop the remaining chunks. Connect() holds the
// bit much longer, but tcpLinkHealthy is already false then, so we stand down
// instead of waiting out the handshake.
constexpr uint32_t UDP_YIELD_TO_TCP_MAX_MS = 80;
// Free-heap low-water used to trigger udp.stop()/begin() every 5 s. That
// malloc/free of the 1460-byte WiFiUDP TX buffer plus a new PCB is what
// produced heap≈74 KB with max_alloc≈45 KB (fragmentation, not a leak):
// stopping TX recovered 74→90→105→122 KB as lwIP pbufs drained. ENOMEM
// now pauses the thermal sender so those pbufs can return; the socket is
// rebuilt only when the fd itself looks dead.
constexpr uint32_t HEAP_RECLAIM_LOW_WATER_BYTES = 48000;
constexpr uint32_t UDP_ENOMEM_BACKOFF_MIN_MS = 250;
constexpr uint32_t UDP_ENOMEM_BACKOFF_MAX_MS = 2000;
constexpr uint32_t UDP_SLOW_TCP_HOLDOFF_MS = 250;
// udpStarted was only cleared when Wi-Fi dropped, so once sendto() entered a
// failing state the task retried the same socket forever: udp_sent froze at 61
// for the rest of the run while udp_failed kept climbing. Rebuilding the socket
// after a run of failures gives the transmitter a way back without a reboot.
constexpr uint32_t UDP_MAX_CONSECUTIVE_FAILURES = 10;
// The per-2-second [link] firehose was 38 fields on one line, five times more
// often than [health]. Same cadence as [health] keeps it readable; 's' still
// prints one on demand and 'l' silences the periodic copy.
constexpr uint32_t DIAG_LOG_PERIOD_MS = 10000;

enum class Mhz19Txn : uint8_t {
  IDLE,
  AWAIT_RESPONSE,
};

// -----------------------------------------------------------------------------
// Thermal-camera constants (MI48xx + MI0801/MI0802, 80 x 62).
// ----------------------------------------------------------------------------
constexpr uint8_t THERMAL_ADDRESS_A = 0x40;
constexpr uint8_t THERMAL_ADDRESS_B = 0x41;

// Winsen MH-Z19B UART read-concentration command 0x86 (9 bytes, 9600 8N1).
// checksum = (NOT (byte1..byte7)) + 1; ppm = high*256 + low.
constexpr uint8_t MHZ19_READ_CMD[9] = {0xFF, 0x01, 0x86, 0x00, 0x00,
                                       0x00, 0x00, 0x00, 0x79};

constexpr uint8_t REG_EVK_TEST = 0x00;
constexpr uint8_t REG_SENSOR_POWERUP = 0xB0;
constexpr uint8_t REG_FRAME_MODE = 0xB1;
constexpr uint8_t REG_FW_VERSION_1 = 0xB2;
constexpr uint8_t REG_FW_VERSION_2 = 0xB3;
constexpr uint8_t REG_FRAME_RATE = 0xB4;
constexpr uint8_t REG_STATUS = 0xB6;
constexpr uint8_t REG_SENSOR_TYPE = 0xBA;

constexpr uint8_t STATUS_DATA_READY = 0x10;
constexpr uint8_t STATUS_BOOTING = 0x20;
constexpr uint8_t MODE_CONTINUOUS = 0x02;

constexpr size_t THERMAL_WIDTH = 80;
constexpr size_t THERMAL_HEIGHT = 62;
constexpr size_t THERMAL_PIXEL_COUNT = THERMAL_WIDTH * THERMAL_HEIGHT;
constexpr size_t THERMAL_HEADER_WORDS = THERMAL_WIDTH;
constexpr size_t THERMAL_CAPTURE_WORDS =
    THERMAL_HEADER_WORDS + THERMAL_PIXEL_COUNT;

// MI48 FRAME_RATE is a divisor of the ~25 FPS native sensor. 25 → ~1.0 FPS.
// Lowering this value raises bandwidth and ESP32 CPU/SPI load.
//
// Divisor 4 (6.25 FPS) is what the Wi-Fi TX path could not sustain: one frame
// is 9 datagrams, so 6.25 FPS put ~57 datagrams/s and ~64 KB/s on the radio in
// 160 ms bursts. Divisor 12 (~2.08 FPS) still competed with 1 Hz TCP until
// writes were fail-fast. 25 keeps the frame format identical at about half
// that UDP rate; raise it back only with the [link] udp_kbps and tcp drop
// counters in view.
constexpr uint8_t THERMAL_FRAME_RATE_DIVIDER = 25;

// -----------------------------------------------------------------------------
// SafeNest TCP protocol v1 for scalar telemetry.
// Outer header (16 bytes, network byte order):
//   magic[4]="SNST", version:u8, type:u8, flags:u16,
//   packet_sequence:u32, payload_length:u32
// Packet type 1 payload: UTF-8 JSON.
// Thermal UDP logical payload: 16-byte metadata followed by 4960 uint16 words.
// -----------------------------------------------------------------------------
constexpr uint8_t PROTOCOL_VERSION = 1;
constexpr uint8_t PACKET_TELEMETRY_JSON = 1;
constexpr uint8_t PACKET_THERMAL_U16_BE = 2;
constexpr size_t PACKET_HEADER_SIZE = 16;
constexpr size_t THERMAL_META_SIZE = 16;

// SafeNest Thermal UDP v1. A 1200-byte datagram stays below the common
// Ethernet/Wi-Fi MTU after IPv4 and UDP headers, avoiding IP fragmentation.
// Header fields are network byte order and every chunk repeats the frame CRC32.
constexpr char THERMAL_UDP_MAGIC[] = "SNTU";
constexpr uint8_t THERMAL_UDP_VERSION = 1;
constexpr size_t THERMAL_UDP_HEADER_SIZE = 32;
constexpr size_t THERMAL_UDP_DATAGRAM_SIZE = 1200;
constexpr size_t THERMAL_UDP_CHUNK_SIZE =
    THERMAL_UDP_DATAGRAM_SIZE - THERMAL_UDP_HEADER_SIZE;
constexpr size_t THERMAL_PAYLOAD_SIZE =
    THERMAL_META_SIZE + THERMAL_PIXEL_COUNT * sizeof(uint16_t);
constexpr uint16_t THERMAL_UDP_CHUNK_COUNT =
    (THERMAL_PAYLOAD_SIZE + THERMAL_UDP_CHUNK_SIZE - 1) /
    THERMAL_UDP_CHUNK_SIZE;

struct TelemetrySnapshot {
  uint32_t sequence;
  uint32_t uptimeMs;
  float respirationRate;
  float heartRate;
  uint16_t co2Ppm;
  bool pirMotion;
  bool respirationValid;
  bool heartValid;
  bool co2Valid;
  bool phaseSamplePresent;
  // Inferred MH-Z19B UART sample identity. Same event_id on later TCP
  // snapshots is a cached retransmission; Pi slope must ignore repeats.
  uint32_t co2MeasurementEventId;
  uint32_t co2MeasurementMonotonicMs;
  bool co2MeasurementEventValid;
  bool co2Preheat;
  // Tri-state MR60 occupancy. `humanDetectedKnown == false` must serialize as
  // JSON null, never false: the Pi presence gate treats false as "room empty"
  // and would then suppress mmWave inference for the wrong reason.
  bool humanDetectedRaw;
  bool humanDetectedKnown;
  float totalPhase;
  float breathPhase;
  float heartPhase;
  uint32_t phaseTimestampMs;
  uint32_t phaseSequence;
};

struct ThermalTxFrame {
  uint32_t frameSequence;
  uint32_t uptimeMs;
  uint16_t minimumRaw;
  uint16_t maximumRaw;
  uint16_t pixels[THERMAL_PIXEL_COUNT];
};

// Per-write forensics. A bare bool made a 2 ms success and a 4.9 s stall that
// eventually succeeded look identical, yet only the second one outlives the
// Pi's receive timeout and gets the socket closed underneath us.
struct TcpWriteReport {
  size_t bytesWritten;
  uint32_t elapsedMs;
  uint32_t longestStallMs;
  uint16_t zeroWrites;
  uint16_t partialWrites;
  int lastErrno;
  bool connectedAtEnd;
};

enum class ThermalSendResult {
  Sent,
  Preempted,
  Failed,
  // The Serial kill switch dropped the frame. Kept distinct from Preempted so
  // a deliberate A/B test never inflates the contention counter.
  Suppressed,
  // The TCP session is down, so the transmitter yielded the radio to let it
  // reconnect. Distinct from Suppressed because nobody asked for it, and from
  // Preempted because no TCP write was actually waiting on the mutex.
  Deferred,
};

HardwareSerial mmWaveSerial(2);
HardwareSerial mhz19Serial(1);

// The library's own SEEED_MR60BHA2::isHumanDetected() cannot express "unknown":
// it returns false both when the room is empty and when no 0x0F09 report has
// been parsed yet, and it self-clears its validity flag on read. Overriding
// handleType() captures the report itself, so an absent report stays
// distinguishable from a negative one. The base implementation is still
// invoked, leaving library state untouched, and the base class has already
// verified both frame checksums before dispatching here.
class SafeNestMR60BHA2 : public SEEED_MR60BHA2 {
 public:
  bool handleType(uint16_t type, const uint8_t *data,
                  size_t dataLength) override {
    if (type == static_cast<uint16_t>(
                    TypeHeartBreath::ReportHumanDetection)) {
      // The vendor handler reads data[0] unguarded; refuse a truncated report
      // here instead of letting it read out of bounds.
      if (dataLength < 1) return false;
      presenceRaw_ = data[0] != 0;
      presencePending_ = true;
    }
    return SEEED_MR60BHA2::handleType(type, data, dataLength);
  }

  // Same one-shot out-parameter idiom as getBreathRate()/getHeartRate(): the
  // return value means "a new report was parsed", never "nobody is present".
  bool takePresence(bool &value) {
    if (!presencePending_) return false;
    presencePending_ = false;
    value = presenceRaw_;
    return true;
  }

  // SeeedmmWave::fetch() keeps a static startFrame that never times out.
  // One false SOF 0x01 consumes real frames as payload for the rest of the
  // boot. Assemble UART locally, then dispatch checksummed frames here.
  bool ingestFrame(const uint8_t *bytes, size_t len) {
    return processFrame(bytes, len);
  }

 private:
  bool presenceRaw_ = false;
  bool presencePending_ = false;
};

SafeNestMR60BHA2 mmWave;
SPIClass thermalSpi(VSPI);

QueueHandle_t telemetryQueue = nullptr;
QueueHandle_t thermalQueue = nullptr;
EventGroupHandle_t networkEvents = nullptr;
SemaphoreHandle_t networkTxMutex = nullptr;
constexpr EventBits_t TCP_CRITICAL_BIT = BIT0;

uint16_t thermalCapture[THERMAL_CAPTURE_WORDS];
// These ~10 KiB objects are global on purpose. Keeping either on a task stack
// can overflow the default Arduino loop stack on a non-PSRAM ESP32.
ThermalTxFrame thermalProducerFrame;
ThermalTxFrame thermalNetworkFrame;
uint8_t thermalAddress = 0;
bool thermalStarted = false;
uint32_t lastThermalRecoverMs = 0;
uint32_t lastThermalProgressMs = 0;
uint32_t lastRecoverCaptureAttempts = 0;

float respirationRate = NAN;
float heartRate = NAN;
float totalPhase = NAN;
float breathPhase = NAN;
float heartPhase = NAN;
uint16_t co2Ppm = 0;
bool pirMotion = false;
bool humanDetectedRaw = false;
bool phaseSamplePresent = false;

uint32_t lastRespirationMs = 0;
uint32_t lastHeartMs = 0;
uint32_t lastPresenceMs = 0;
uint32_t lastCo2Ms = 0;
uint32_t lastThermalStatusPollMs = 0;
uint32_t lastPirPollMs = 0;
uint32_t lastCo2PollMs = 0;
uint32_t lastTelemetryMs = 0;
uint32_t lastHealthLogMs = 0;
uint32_t telemetrySequence = 0;
uint32_t thermalSequence = 0;
uint32_t thermalCrcErrors = 0;
uint32_t thermalRangeErrors = 0;
uint32_t co2MeasurementEventId = 0;
uint32_t co2MeasurementMonotonicMs = 0;
bool co2MeasurementEventValid = false;
Mhz19Txn mhz19Txn = Mhz19Txn::IDLE;
uint32_t mhz19RequestSentMs = 0;
uint32_t co2ChecksumFailures = 0;
uint32_t co2TimeoutFailures = 0;
uint32_t co2ShortFrameFailures = 0;
uint32_t co2AcceptedSamples = 0;
uint16_t co2LastUartPpm = 0;
// Written by the network tasks on core 0 and read by loop() on core 1. Each
// counter has exactly one writer and aligned 32-bit accesses are atomic on
// Xtensa, so volatile only has to stop the compiler caching them in registers.
volatile uint32_t telemetryQueueOverwrites = 0;
volatile uint32_t thermalQueueOverwrites = 0;
volatile uint32_t tcpConnectionFailures = 0;
volatile uint32_t tcpSendFailures = 0;
volatile uint32_t thermalUdpFramesSent = 0;
volatile uint32_t thermalFramesPreempted = 0;
volatile uint32_t thermalTcpYields = 0;
volatile uint32_t thermalUdpSendFailures = 0;
volatile uint32_t heapReclaims = 0;
volatile uint32_t heapReclaimSkippedTcp = 0;
volatile uint32_t udpHoldoffEvents = 0;
volatile uint32_t udpHoldoffUntilMs = 0;
volatile uint32_t udpBackoffMs = 0;
volatile uint32_t tcpWriteTimeouts = 0;

// Link diagnostics written by the network tasks on core 0, under the same
// single-writer, aligned-32-bit rule as the counters above.
volatile uint32_t tcpSessions = 0;
volatile uint32_t tcpDrops = 0;
volatile uint32_t tcpShortSessions = 0;
volatile uint32_t tcpPeerClosed = 0;
volatile uint32_t tcpWriteStalls = 0;
volatile uint32_t tcpPartialWrites = 0;
volatile uint32_t tcpMutexTimeouts = 0;
volatile uint32_t tcpMutexWaitMaxMs = 0;
volatile uint32_t tcpMutexWaitSlow = 0;
volatile uint32_t tcpWriteMaxMs = 0;
volatile uint32_t tcpSlowWrites = 0;
volatile uint32_t telemetryGapMaxMs = 0;
volatile uint32_t telemetryGapOverWarn = 0;
volatile uint32_t telemetryGapOverDeadline = 0;
volatile uint32_t telemetryPacketsSent = 0;
volatile uint32_t lastTelemetrySentMs = 0;
volatile uint32_t udpDatagramsSent = 0;
volatile uint32_t udpBytesSent = 0;
volatile uint32_t udpDatagramMaxMs = 0;
volatile uint32_t udpSlowDatagrams = 0;
volatile uint32_t udpFrameMaxMs = 0;
volatile uint32_t thermalFramesSuppressed = 0;
volatile uint32_t thermalFramesDeferred = 0;
volatile uint32_t udpSocketRestarts = 0;
volatile int32_t tcpLastErrno = 0;
volatile int32_t udpLastErrno = 0;
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
void loop() {
  const uint32_t now = millis();
  ++loopIterations;

  pollMmWave(now);
  pollCo2(now);
  maybeRecoverThermalCamera(now);
  captureThermalIfReady(now);
  // SPI capture blocks UART servicing. Drain again so a mid-frame SOF does
  // not sit in the Seeed assembler until the next ~1 fps camera tick.
  pollMmWave(millis());

  if (scheduleDue(now, lastPirPollMs, PIR_PERIOD_MS)) {
    pirMotion = digitalRead(PIN_PIR) == HIGH;
  }

  publishTelemetrySnapshot(now);
  handleSerialCommand();
  logLinkDiagnostics(now);
  logHealth(now);

  // Cooperative yield only; there is intentionally no delay() in runtime.
  taskYIELD();
}

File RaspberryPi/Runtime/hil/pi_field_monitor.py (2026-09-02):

#!/usr/bin/env python3
"""SafeNest Pi field monitor — storage / AI input / link / risk / LCD (table view).

Read-only. Polls GET /health, /api/status, /api/state.

The header Thermal line is inferred from GET /api/status runtime_status
(model_selector / preprocessing_id), not from launch flags or logs.

Examples (on Pi):
  python3 hil/pi_field_monitor.py
  python3 hil/pi_field_monitor.py --once
  python3 hil/pi_field_monitor.py --interval 3
  python3 hil/pi_field_monitor.py --raw-labels

Examples (from Mac):
  python3 hil/pi_field_monitor.py --base http://<PI_IP>:8000
"""

from __future__ import annotations

import argparse
import json
import shutil
import sys
import time
import urllib.error
import urllib.request
from typing import Any


SENSORS = ("mmwave", "thermal", "co2", "pir")

# Short labels for the table. Full names are spelled out in the legend below.
AI_STATE_SHORT = {
    "PHYSIOLOGY_ELIGIBLE": "PHYS_OK",
    "ABSENT": "ABSENT",
    "QUALITY_SUPPRESSED": "Q_LOW",
    "RR_UNAVAILABLE": "NO_RR",
    "WINDOW_NOT_READY": "WARMUP",
    "PRESENCE_UNAVAILABLE": "NO_OCC",
    "PRESENCE_FALSE": "EMPTY",
    "WINDOW_UNAVAILABLE": "NO_WIN",
    "INPUT_UNAVAILABLE": "NO_IN",
    "NORMAL": "NORMAL",
    "RAPID_OR_ABNORMAL": "RAPID",
    "APNEA": "APNEA",
    "NOT_HUMAN": "NO_HUM",
    "HUMAN_NORMAL": "HUMAN",
    "HUMAN_FALL": "FALL",
    "HUMAN_FALL_PROXY": "FALL_PX",
    "VACANT": "VACANT",
    "OCCUPIED": "OCC",
    "MOTION": "MOVE",
    "NO_MOTION": "STILL",
}

ERR_SHORT = {
    "WINDOW_NOT_READY": "WARMUP",
    "PRESENCE_UNAVAILABLE": "NO_OCC",
    "PRESENCE_FALSE": "EMPTY",
    "R1_TIMESTAMP_GRID_INCONSISTENT": "R1_TIME",
    "WINDOW_CONTAINS_LARGE_GAP": "GAP",
    "SENSOR_NO_DATA": "NO_DATA",
    "SENSOR_INVALID": "BAD",
    "SENSOR_STALE": "STALE",
    "SENSOR_DISCONNECTED": "DISC",
    "QUALITY_SUPPRESSED": "Q_LOW",
    "QUALITY_FAIL": "Q_LOW",
    "UNAVAILABLE_INVALID_DECODE": "NO_RR",
    "PHASE_MISSING": "NO_PH",
    "PHASE_STALE": "OLD_PH",
    "BOOT_BOUNDARY": "BOOT",
    "TIMESTAMP_INVALID": "BAD_TS",
    "PHASE_SEQUENCE_MISSING": "NO_SEQ",
    "SOURCE_RATE_BELOW_TARGET": "SLOW",
    "R1_SAMPLE_COUNT_MISMATCH": "R1_N",
    "INT8_QUANTIZATION_REVIEW_REQUIRED": "INT8",
    "CANONICAL_FRESHNESS_METADATA_MISSING": "NO_META",
    "PRESENCE_STATE_UNAVAILABLE": "NO_OCC",
    "THERMAL_FRAME_MISSING": "NO_FRM",
    "INSUFFICIENT_CONTINUOUS_DURATION": "WARMUP",
    "INPUT_WARMUP": "WARMUP",
    "MODEL_RUNTIME_UNAVAILABLE": "NO_MDL",
}

RISK_SHORT = {
    "RESPIRATION_NORMAL": "RR_OK",
    "RESPIRATION_ABNORMAL": "RR_ABN",
    "RESPIRATION_INPUT_UNAVAILABLE": "RR_NA",
    "NOT_HUMAN": "NO_HUM",
    "HUMAN_NORMAL": "HUMAN",
    "HUMAN_FALL": "FALL",
    "HUMAN_FALL_PROXY": "FALL_PX",
    "CO2_NORMAL": "CO2_OK",
    "CO2_WARNING": "CO2_WN",
    "CO2_DANGER": "CO2_DG",
    "CO2_IMMEDIATE_DANGER": "CO2_NOW",
    "MOTION": "MOVE",
    "NO_MOTION": "STILL",
    "NO_MOTION_RISING": "STILL+",
    "LONG_NO_MOTION": "STILL++",
    "UNAVAILABLE": "NA",
    "RULE_FALLBACK": "RULE",
    "NORMAL": "OK",
    "WARNING": "WARN",
    "DANGER": "DANGER",
}

STATUS_SHORT = {
    "LIVE": "LIVE",
    "NO_DATA": "NONE",
    "STALE": "STALE",
    "DISCONNECTED": "DISC",
    "INVALID": "BAD",
    "DEGRADED": "DEG",
}

# Process-selected Thermal identity. Unknown selectors stay UNKNOWN + raw id.
THERMAL_SELECTOR_LABELS = {
    "thermal_public_sdt_fp32_active": "BASELINE",
    "thermal_tv2_candidate_a_a0_fp32_v1": "A",
    "thermal_tv2_candidate_b_seed42_fp32_test_v1": "B",
}


def short_label(value: Any, mapping: dict[str, str], *, raw: bool) -> Any:
    if value is None:
        return None
    text = str(value)
    if raw:
        return text
    return mapping.get(text, text)


def get_json(base: str, path: str, timeout: float) -> dict[str, Any]:
    url = base.rstrip("/") + path
    req = urllib.request.Request(url, headers={"Accept": "application/json"})
    with urllib.request.urlopen(req, timeout=timeout) as resp:
        return json.load(resp)


def cell(value: Any, width: int) -> str:
    text = "-" if value is None else str(value)
    if len(text) > width:
        text = text[: max(0, width - 1)] + "…"
    return text.ljust(width)


def table(headers: list[str], rows: list[list[Any]], widths: list[int] | None = None) -> str:
    if widths is None:
        widths = []
        for i, h in enumerate(headers):
            col = [str(h)] + [("-" if r[i] is None else str(r[i])) for r in rows]
            widths.append(min(28, max(len(c) for c in col)))
    sep = "+" + "+".join("-" * (w + 2) for w in widths) + "+"
    lines = [sep]
    lines.append("| " + " | ".join(cell(h, w) for h, w in zip(headers, widths)) + " |")
    lines.append(sep)
    for row in rows:
        lines.append("| " + " | ".join(cell(v, w) for v, w in zip(row, widths)) + " |")
    lines.append(sep)
    return "\n".join(lines)


def fmt_num(v: Any) -> str:
    if v is None:
        return "-"
    if isinstance(v, float):
        if abs(v) >= 100:
            return f"{v:.0f}"
        return f"{v:.2f}"
    return str(v)


def delta(curr: Any, prev: Any) -> str:
    if curr is None or prev is None:
        return "-"
    try:
        d = float(curr) - float(prev)
    except (TypeError, ValueError):
        return "-"
    if abs(d) < 1e-9:
        return "0"
    if d > 0:
        return f"+{fmt_num(d)}"
    return fmt_num(d)


def judge_flow(d: float | None, *, need_positive: bool = True) -> str:
    if d is None:
        return "?"
    if need_positive:
        return "YES" if d > 0 else "NO"
    return "OK" if d >= 0 else "DROP"


def sensor_block(status: dict[str, Any], name: str) -> dict[str, Any]:
    block = status.get(name)
    return block if isinstance(block, dict) else {}


def dig(mapping: Any, *keys: str, default: Any = None) -> Any:
    cur = mapping
    for key in keys:
        if not isinstance(cur, dict):
            return default
        cur = cur.get(key, default)
    return cur


def thermal_runtime_status(status: Any) -> dict[str, Any]:
    """Read Thermal identity from GET /api/status. Never from env or logs."""

    if not isinstance(status, dict):
        return {}
    thermal = status.get("thermal")
    if isinstance(thermal, dict):
        runtime = thermal.get("runtime_status")
        if isinstance(runtime, dict):
            return runtime
    nested = dig(status, "runtime_status", "sensors", "thermal", default={})
    return nested if isinstance(nested, dict) else {}


def friendly_thermal_choice(selector: Any) -> str:
    text = str(selector).strip() if selector is not None else ""
    if not text:
        return "UNAVAILABLE"
    return THERMAL_SELECTOR_LABELS.get(text, "UNKNOWN")
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

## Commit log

2026-09-01 Import files from safenest-embedded-competition
    Copy all files from the safenest-embedded-competition repo, keeping the
    existing README.md untouched.
    [2026-07-25_breath_paced_12rpm__S001_BREATH_PACED_12_01.csv, 2026-07-25_entry_exit_10__S001_ENTRY_EXIT_01.csv, 2026-07-25_entry_exit_10__S001_ENTRY_EXIT_02.csv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]
2026-09-01 Add esp32_sensor_node_mhz19b_20260901-2130-junwoo sketch
2026-09-01 chore: 제출용 저장소 구조 정리
    개발 이력 보관용 archive/research, 학습 데이터셋과 실험 스크립트,
    중복 ESP32 스케치와 사용하지 않는 LCD/Web 자산을 제거하고
    실제 실행 경로에 필요한 파일만 남긴다.
    관리자 화면이 서빙되지 않는 스크립트 이름을 참조하던 문제를 고치고,
    활성 mmWave 경로에 필요한 torch 의존성을 Raspberry Pi 설치 목록에 포함한다.
    ESP32 정본 스케치 경로를 paths.py와 문서 기준으로 통일한다.
    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
    [2026-07-25_breath_paced_12rpm__S001_BREATH_PACED_12_01.csv, 2026-07-25_entry_exit_10__S001_ENTRY_EXIT_01.csv, 2026-07-25_entry_exit_10__S001_ENTRY_EXIT_02.csv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]
2026-09-02 chore: 제출용 저장소 최신 production 상태 통합
    [20260822_thermal_field_measurement_summary.csv]
2026-09-02 chore: 실기기 최신 production 상태 통합 (Risk 1.3.3 · 재실 게이팅 · bbox 자세)
    팀 운영 저장소 main 53b1019 (fix/web: serve thermal client from canonical
    route) 기준으로 제출용 브릿지를 최신화한다. 실기기 Raspberry Pi 에 올라가
    동작 중인 코드와 동일한 상태다.
    - PR #87 CO2 주의는 room baseline lock 이후에만 발생
    - PR #88 비재실에서는 위험·긴급 없이 CO2 주의만. 빈방 5000 ppm 은 WARNING,
    재실 5000 ppm 은 즉시 긴급. LCD occupied 판정을 presence_detected 로 변경
    - PR #89 필드 모니터 서기/앉기 HUMAN, 눕기 FALL_PX (bbox 종횡비)
    - PR #90 CO2 주의일 때 호흡이상 음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
2026-09-02 UI·문서·HIL 판정 기준을 Risk Formula V1 1.3.3 계약에 정합화
    대시보드 위험 사유 라벨을 현행 엔진이 실제로 발행하는 코드에 맞춘다.
    호흡 정상범위 10-24 rpm, 무움직임 180초로 정정하고, 재실 게이팅 사유
    (VACANT_DANGER_SUPPRESSED 등)에 한글 라벨을 추가한다. 구형 엔진만
    발행하던 HIGH_CO2_WARNING/DANGER 라벨은 제거한다.
    CO2 센서 표기를 실제 탑재 부품인 MH-Z19B로 통일한다(대시보드·게스트).
    열화상은 temperature_calibrated=false 이므로 게스트 화면에 "온도 보정
    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
2026-09-02 Repair docs deletion and ESP32 rename fallout, drop thermal A/B launcher
    Recent GitHub-web commits deleted docs/ and RaspberryPi/Runtime/docs/, and
    renamed the canonical ESP32 sketch to esp32_sensor_node/. Neither change
    updated the references pointing at them, so the submission bundle no longer
    verified: verify_bundle.py reported ok:false, test_phase2_source_contracts
    errored on all 11 cases, README carried 5 dead relative links, and
    COMPONENT_SOURCES.json listed 4 paths that no longer exist.
    ESP32 rename (blobs are byte-identical; only paths moved):
    - paths.py, verify_bundle.py, COMPONENT_SOURCES.json, README.md,
    THIRD_PARTY_NOTICES.md, ESP32/docs, ESP32.md now point at
    esp32_se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
    [pi_field_monitor.py]
2026-09-02 Stop ESP32 docs from presenting absent sketches as current
    Two places named sketch folders that do not exist in this repository and
    presented them as the current state, which was the last remaining case of
    documentation describing a tree other than this one.
    ESP32/docs/COMMUNICATION_PROTOCOL.md, CO2 section
    The comparison table keyed its rows on esp32_sensor_node_260828_v2 and
    esp32_sensor_node_mhz19b_v2, neither of which is here, under a sentence
    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
